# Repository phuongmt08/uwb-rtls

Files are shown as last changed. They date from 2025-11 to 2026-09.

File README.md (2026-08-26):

<div align="center">

# UWB-RTLS

### On-device indoor positioning for autonomous mobile robots







**[Results](#experimental-validation) · [System](#system-overview) · [Features](#core-capabilities) · [Quick start](#quick-start) · [Documentation](#documentation)**

</div>

UWB-RTLS is an end-to-end real-time location system developed for indoor mobile robots. Fixed UWB Anchors measure their distance to a mobile Tag using DS-TWR. The Tag validates the ranges, selects a reliable Anchor subset, fuses UWB with IMU data, and calculates its pose directly on an STM32F411. RTLS Studio provides wireless configuration, live diagnostics, visualization, and experiment logging.

<table>
  <tr>
    <th align="center">Best evaluated MAE</th>
    <th align="center">Best evaluated RMSE</th>
    <th align="center">Positioning</th>
    <th align="center">Validation</th>
  </tr>
  <tr>
    <td align="center"><strong>8.5 cm</strong></td>
    <td align="center"><strong>10.9 cm</strong></td>
    <td align="center"><strong>On the Tag</strong></td>
    <td align="center"><strong>2 real environments</strong></td>
  </tr>
</table>

## System Overview

Fixed Anchors provide UWB references around the operating area. The mobile Tag performs ranging and position estimation, sends pose data directly to the vehicle controller, and exposes configuration and telemetry through the BLE gateway.

```mermaid
flowchart TD
    Anchors["Fixed UWB Anchors"] <-->|"DS-TWR ranging"| Tag["Mobile Tag<br/>On-device positioning"]
    Tag -->|"Pose over USB"| Robot["Vehicle Controller"]
    Tag <-->|"Configuration + telemetry"| Gateway["BLE Gateway"]
    Gateway <-->|"USB serial"| Studio["RTLS Studio"]
```

Positioning remains operational without the desktop application: RTLS Studio is a configuration and observability tool, not the positioning engine.

## System in Practice

The experimental platform uses the developed Anchor/Tag hardware and a 1:10-scale vehicle. The photographs below show the actual Chapter 5 test-yard deployment.

<p align="center">
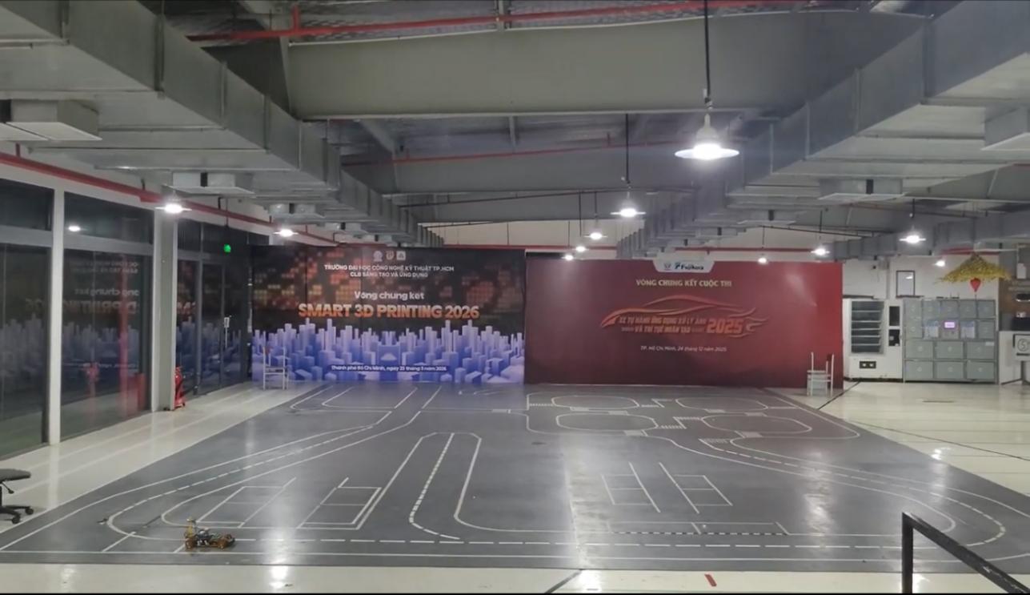
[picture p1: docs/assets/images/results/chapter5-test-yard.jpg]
Full UWB RTLS test-yard environment
  <br>
  <sub>Full four-Anchor test-yard deployment</sub>
</p>

<table>
  <tr>
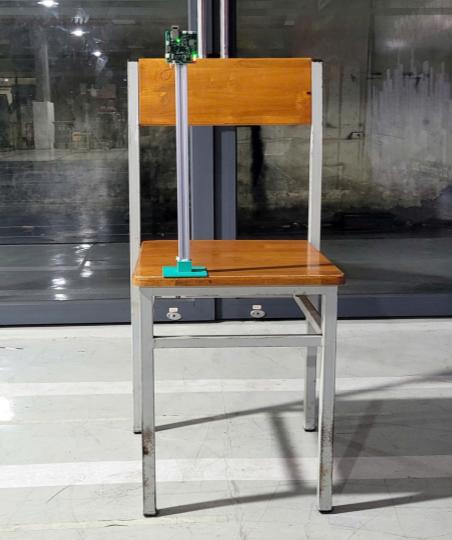
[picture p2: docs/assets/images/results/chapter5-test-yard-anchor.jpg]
UWB Anchor mounted at the test yard
    <td width="50%" align="center"><br><sub>Anchor installed at the surveyed height</sub></td>
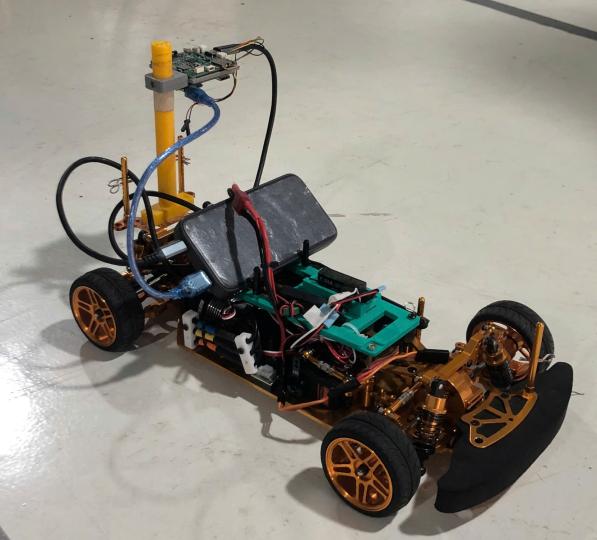
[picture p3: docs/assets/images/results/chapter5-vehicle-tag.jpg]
Mobile robot carrying the UWB Tag
    <td width="50%" align="center"><br><sub>1:10-scale vehicle carrying the Tag</sub></td>
  </tr>
</table>

RTLS Studio provides the host-side view of the deployed system for device configuration, diagnostics, and experiment recording.

<p align="center">
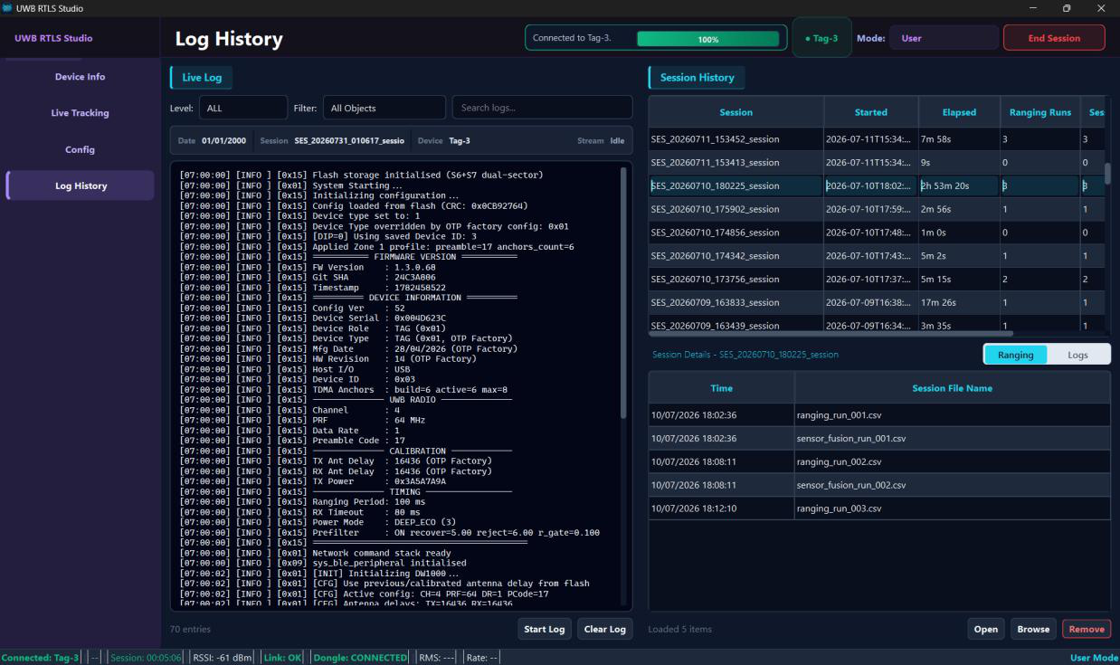
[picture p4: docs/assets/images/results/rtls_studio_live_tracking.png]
RTLS Studio diagnostics and session history
  <br>
  <sub>Connected-device diagnostics, live logs, and recorded ranging sessions</sub>
</p>

## Experimental Validation

Two dynamic cases were evaluated: a large, mostly line-of-sight test yard and a furnished classroom with stronger multipath and partial obstruction. Direct trilateration and UKF outputs were recorded simultaneously so both estimators saw the same motion and UWB measurements.

### Evaluation protocol

| Item | Method |
|---|---|
| Reference path | Manually surveyed control points connected by interpolation |
| Point error | Euclidean distance from each estimate to the nearest point on the reference path |
| Active interval | Samples before departure and after the vehicle stopped were excluded |
| Repetition | Three runs for each trajectory or Anchor configuration |
| Reported metrics | MAE, RMSE, 95th-percentile error, and maximum error |

### Case 1 — Test yard, four Anchors

The first case used a **9.76 m × 11.64 m** indoor test yard with mostly clear line of sight. Four Anchors surrounded the working area at **0.895 m**, while the Tag was mounted at **0.350 m**. The vehicle followed two surveyed trajectories, each repeated three times.

<table>
  <tr>
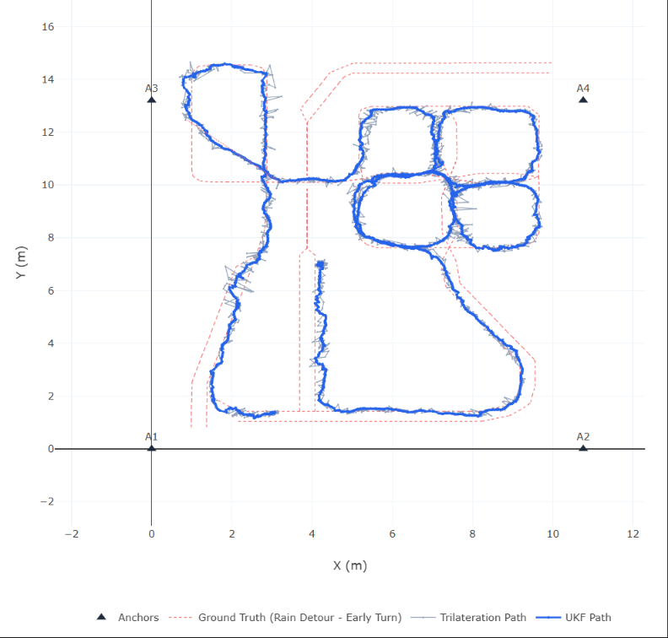
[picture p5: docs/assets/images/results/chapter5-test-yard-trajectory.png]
Test-yard reference, trilateration, and UKF trajectories
    <td width="50%" align="center"></td>
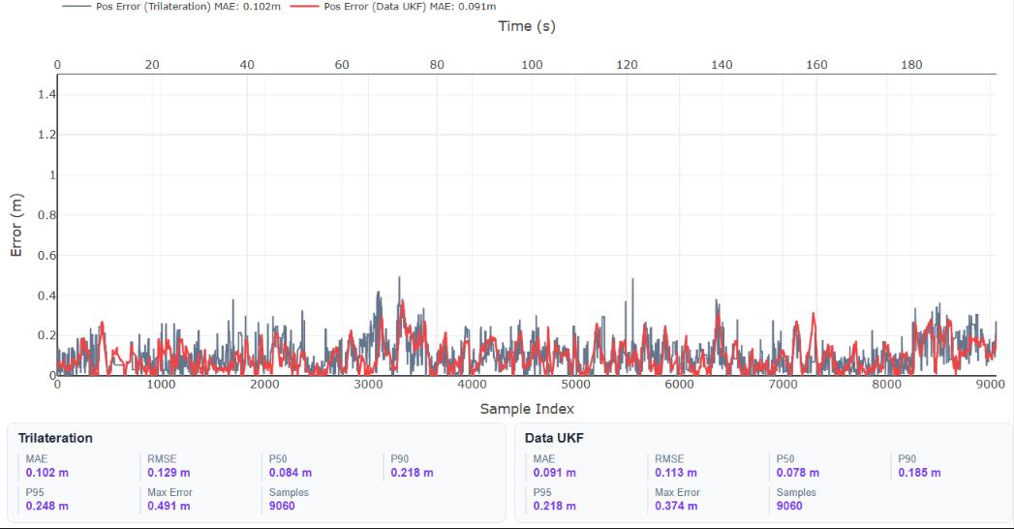
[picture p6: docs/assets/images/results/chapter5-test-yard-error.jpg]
Test-yard position error over time
    <td width="50%" align="center"></td>
  </tr>
  <tr>
    <td align="center"><sub>Reference path, direct trilateration, and UKF trajectory</sub></td>
    <td align="center"><sub>Position error from the same representative run</sub></td>
  </tr>
</table>

| Estimator | MAE (m) | RMSE (m) | P95 (m) | Max (m) |
|---|---:|---:|---:|---:|
| Direct trilateration | 0.102 ± 0.006 | 0.134 ± 0.010 | 0.268 ± 0.024 | 0.782 ± 0.281 |
| **UKF** | **0.091 ± 0.005** | **0.117 ± 0.005** | **0.236 ± 0.014** | **0.456 ± 0.063** |

Across the test-yard runs, the UKF reduced average MAE by **10.9%**, RMSE by **12.8%**, and maximum error from **0.782 m to 0.456 m**.

### Case 2 — Classroom, four and six Anchors

The second case used an **8.3 m × 8.7 m** classroom containing desks, people, and reflective surfaces. Anchors were installed at **2.495 m** and the Tag at **0.585 m**. Both four- and six-Anchor layouts were tested to measure the value of additional spatial redundancy.

<table>
  <tr>
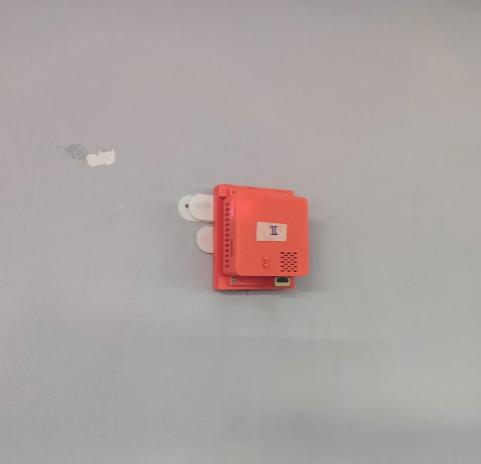
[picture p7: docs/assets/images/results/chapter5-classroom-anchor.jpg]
UWB Anchor mounted on a classroom wall
    <td width="50%" align="center"></td>
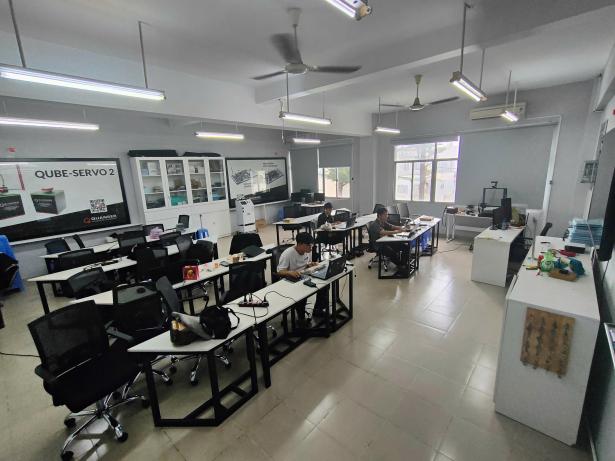
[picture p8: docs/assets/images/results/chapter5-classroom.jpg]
Classroom UWB RTLS deployment
    <td width="50%" align="center"></td>
  </tr>
  <tr>
    <td align="center"><sub>Wall-mounted Anchor</sub></td>
    <td align="center"><sub>Classroom deployment with furniture and occupants</sub></td>
  </tr>
</table>

<table>
  <tr>
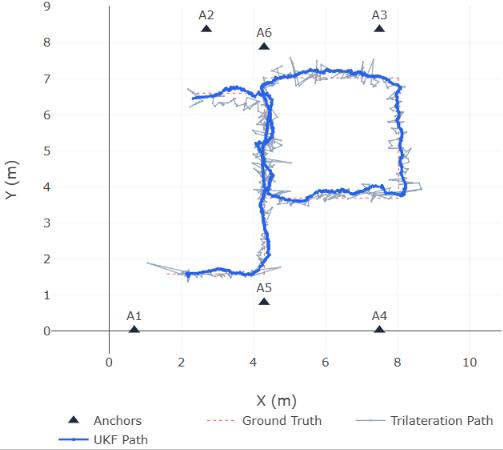
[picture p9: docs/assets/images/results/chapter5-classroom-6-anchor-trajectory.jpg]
Six-Anchor classroom trajectory result
    <td width="50%" align="center"></td>
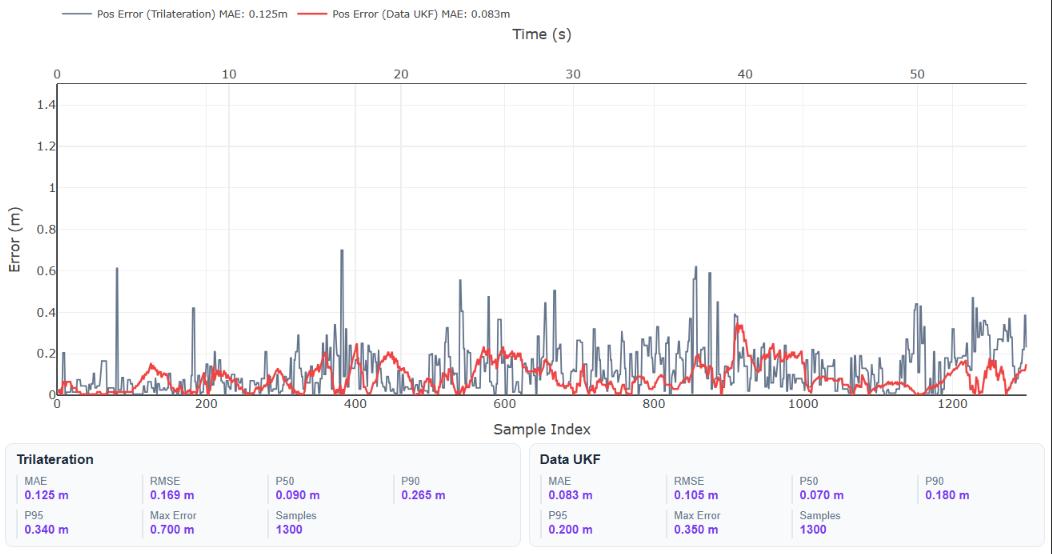
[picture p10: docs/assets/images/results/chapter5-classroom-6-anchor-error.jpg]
Six-Anchor classroom position error
    <td width="50%" align="center"></td>
  </tr>
  <tr>
    <td align="center"><sub>Six-Anchor reference, trilateration, and UKF trajectories</sub></td>
    <td align="center"><sub>Position error from the same representative run</sub></td>
  </tr>
</table>

| Layout | Estimator | MAE (m) | RMSE (m) | P95 (m) | Max (m) |
|---|---|---:|---:|---:|---:|
| 4 Anchors | Direct trilateration | 0.173 ± 0.027 | 0.230 ± 0.037 | 0.457 ± 0.084 | 1.099 ± 0.131 |
| 4 Anchors | **UKF** | **0.139 ± 0.036** | **0.185 ± 0.043** | **0.393 ± 0.085** | **0.583 ± 0.064** |
| 6 Anchors | Direct trilateration | 0.123 ± 0.006 | 0.177 ± 0.007 | 0.340 ± 0.035 | 1.150 ± 0.562 |
| 6 Anchors | **UKF** | **0.085 ± 0.013** | **0.109 ± 0.015** | **0.215 ± 0.035** | **0.340 ± 0.026** |

The six-Anchor UKF configuration produced the strongest overall result: **8.5 cm MAE**, **10.9 cm RMSE**, **21.5 cm P95**, and **34.0 cm maximum error**. The result demonstrates the benefit of additional valid ranging links in a difficult indoor environment.

> **Measurement scope:** the reference trajectory was reconstructed from manually measured control points, not an independent motion-capture system. The results therefore quantify tracking performance under the documented procedure rather than metrology-grade absolute accuracy.

## Core Capabilities

| Area | Implemented capability | Purpose |
|---|---|---|
| Ranging | Asymmetric DS-TWR with TDMA scheduling | Measures multiple Tag-to-Anchor ranges without clock synchronization |
| Measurement validation | Spatial innovation prefilter | Rejects inconsistent range combinations before estimation |
| Anchor selection | Robust precision and WGDOP ranking | Chooses a geometrically useful three-Anchor measurement set |
| Sensor fusion | 8-state UWB/IMU UKF | Estimates planar position, velocity, yaw, and IMU biases |
| Embedded runtime | FreeRTOS task-based firmware | Separates ranging, fusion, communication, storage, and supervision |
| Hardware flexibility | Unified Tag/Anchor STM32 firmware | Selects the device role and Anchor identity without maintaining separate applications |
| Configuration | Persistent profiles with CRC-protected storage | Keeps deployment parameters across resets |
| Communication | Shared Protobuf messages with COBS-framed transport | Maintains one contract across STM32, BLE, and Python |
| Desktop tooling | RTLS Studio and firmware programmer | Supports commissioning, live diagnostics, logs, and updates |

## Hardware and Software

| Layer | Main technology | Responsibility |
|---|---|---|
| Tag and Anchor MCU | STM32F411CEU6, Cortex-M4F | Real-time protocol, positioning, sensor fusion, and interfaces |
| UWB radio | Decawave/Qorvo DW1000 module | Precision packet timestamping for DS-TWR |
| Motion sensor | 6-DOF SPI IMU | Acceleration and yaw-rate input to the UKF |
| BLE nodes | Nordic nRF52 | Wireless configuration and telemetry |
| USB gateway | Nordic nRF52840 dongle | BLE central and USB bridge |
| Embedded OS | FreeRTOS | Deterministic task and queue organization |
| Desktop | Python 3.10+ and PyQt6 | RTLS Studio, programming, and analysis tools |

### Verified Development Environment

| Tool | Verified version |
|---|---|
| STM32CubeIDE | 1.19.0; project supports the 1.10+ workflow |
| Arm GNU Toolchain | 10.3.1 and 13.3.Rel1 |
| GNU Make | 4.4.1 |
| Nordic nRF5 SDK | 17.1.0 |
| Python | 3.10+; 3.12 verified |

## Quick Start

The commands below build the repository and launch RTLS Studio. Device flashing, antenna-delay calibration, Anchor surveying, and commissioning are covered in the [Getting Started Guide](docs/getting_started.md) and [Deployment Guide](docs/deployment.md).

### 1. Clone and generate the shared protocol

```powershell
git clone --recursive https://github.com/phuongmt08/uwb-rtls.git
cd uwb-rtls
make -C protocol
```

### 2. Build the STM32 firmware

Install STM32CubeIDE or an Arm GNU toolchain, then point `GCC_PATH` to its compiler `bin` directory.

```powershell
$env:GCC_PATH = "C:\path\to\arm-none-eabi\bin"
make -C firmware/uwb -j8
```

The build produces ELF, HEX, and BIN files under `firmware/uwb/build`.

### 3. Build the BLE firmware when required

The gateway and BLE bridge targets use Nordic nRF5 SDK 17.1.0.

```powershell
$env:SDK_ROOT = "C:\nRF5_SDK_17.1.0_ddde5a0"
make -C firmware/ble_firmware/central/armgcc
make -C firmware/ble_firmware/peripheral/armgcc
```

### 4. Launch RTLS Studio

```powershell
cd software
python -m venv .venv
.\.venv\Scripts\Activate.ps1
pip install -r requirements.txt
python uwb_rtls_studio/main.py
```

### 5. Commission a deployment

1. Install at least four Anchors around the operating area and assign unique IDs.
2. Survey their coordinates and create the deployment profile in RTLS Studio.
3. Mount the Tag on the vehicle and enter the Tag height.
4. Connect the BLE gateway, select the Tag, and push the configuration.
5. Start ranging and confirm that at least three valid Anchor links are available.
6. Monitor the embedded pose or record a session for offline evaluation.

## Repository Structure

```text
uwb-rtls/
├── firmware/     STM32 application, BLE firmware, and bootloader
├── software/     RTLS Studio, programmer, and analysis tools
├── protocol/     Protobuf contracts and generated bindings
├── hardware/     Schematics, PCB sources, and calibration data
└── docs/         Setup, deployment, architecture, algorithms, and thesis
```

## Documentation

| Start here | Scope |
|---|---|
| **[Getting Started](docs/getting_started.md)** | Toolchains, builds, flashing, and first connection |
| **[Deployment and Commissioning](docs/deployment.md)** | Physical layout, Anchor survey, calibration, and validation |
| **[Firmware Architecture](docs/firmware/architecture.md)** | Embedded layers, RTOS tasks, queues, and runtime ownership |
| **[DS-TWR Ranging Protocol](docs/firmware/ranging_protocol.md)** | Packet sequence, timestamps, timing, and TDMA behavior |
| **[Positioning Algorithms](docs/firmware/positioning_algorithms.md)** | Mathematical model, prefilter, Anchor selection, and UKF |
| **[Schematics and Specifications](docs/hardware/schematics_and_specs.md)** | Hardware boards, interfaces, and design references |
| **[RTLS Studio and Tools](docs/software/rtls_studio_and_tools.md)** | Desktop configuration, monitoring, logging, and programming |
| **[Thesis](docs/thesis/thesis_final.pdf)** | Full design, implementation, and experimental evaluation |

## Team

Developed at the **Faculty of Mechanical Engineering**, Ho Chi Minh City University of Technology and Engineering (**HCMUTE**).

- **Phuong Mai** — Firmware and system architecture
- **Dong Son** — Project co-developer
- **Trung Quan** — Project co-developer

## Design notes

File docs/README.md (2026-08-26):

# UWB-RTLS Documentation Index

[GitHub Repository](https://github.com/phuongmt08/uwb-rtls)

This directory contains the comprehensive technical documentation for the **UWB-RTLS** embedded indoor positioning system, covering firmware architecture, RF ranging protocols, positioning mathematics, hardware specifications, and desktop tools.

---

## 1. Documentation Map

| Section | Document | Description |
| --- | --- | --- |
| **Setup & Build** | **[Getting Started Guide](getting_started.md)** | Step-by-step toolchain setup, `GCC_PATH` configuration, and build instructions |
| **Firmware** | **[Firmware Architecture](firmware/architecture.md)** | Embedded layers, FreeRTOS runtime tasks, role selection, and source map |
| **Firmware** | **[DS-TWR Ranging Protocol](firmware/ranging_protocol.md)** | Timestamp mechanics, TDMA frame timing budget, and failure handling |
| **Firmware** | **[Positioning Algorithms](firmware/positioning_algorithms.md)** | Mahalanobis prefiltering, Huber weighting, WGDOP selection, and 8-State UKF |
| **Hardware** | **[Hardware Specifications](hardware/schematics_and_specs.md)** | System components, MCU/UWB/IMU/BLE pinout mappings, and power architecture |
| **Hardware** | **[Antenna Delay Calibration](hardware/antenna_calibration.md)** | Calibration theory, baseline measurement methodology, and tuning formula |
| **Software** | **[RTLS Studio & Tools](software/rtls_studio_and_tools.md)** | PyQt6 MVVM architecture, live 2D tracking, session export, and USB DFU Programmer |
| **Deployment** | **[Deployment & Commissioning](deployment.md)** | Anchor placement guidelines, GDOP optimization, and commissioning checklist |
| **Assets** | **[Asset Catalog](assets/README.md)** | Extracted thesis diagrams, architecture figures, and vector illustrations |

---

## 2. Thesis Benchmark & Performance Summary

The underlying academic thesis presents a modular indoor positioning system evaluated in a 6-Anchor classroom deployment:

| Metric | Measured Value | Operational Condition |
| --- | :---: | --- |
| **Mean Absolute Error (MAE)** | **$0.085\text{ m}$** ($8.5\text{ cm}$) | In-zone dynamic trajectory |
| **Root Mean Square Error (RMSE)** | **$0.109\text{ m}$** ($10.9\text{ cm}$) | 6-Anchor TDMA constellation |
| **95th-Percentile Error** | **$0.215\text{ m}$** ($21.5\text{ cm}$) | Under typical indoor multipath conditions |
| **Nominal Update Rate** | **$10\text{ Hz}$** ($100\text{ ms}$ frame) | Complete 6-Anchor ranging & UKF cycle |

---

## 3. Project Team & Credits

Developed at the **Faculty of Mechanical Engineering**, Ho Chi Minh City University of Technology and Engineering (**HCMUTE**).

- **Phuong Mai** — Lead Firmware & System Architecture
- **Dong Son** — Project Co-Developer
- **Trung Quan** — Project Co-Developer

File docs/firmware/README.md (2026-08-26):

# Firmware Documentation Guide

[Documentation Home](../README.md) · [Getting Started](../getting_started.md)

This section details the embedded firmware running on the STM32F411 microcontrollers, from low-level hardware abstraction up to real-time positioning algorithms and sensor fusion.

---

## 1. Reading Order

```mermaid
flowchart TD
    A["1. Firmware Architecture"] --> B["2. DS-TWR Ranging Protocol"]
    B --> C["3. Positioning Algorithms"]
```

1. **[Embedded Firmware Architecture](architecture.md)**
   - Role selection (Tag vs. Anchor via User Button hold).
   - Layered architecture (HAL $\rightarrow$ BSP $\rightarrow$ Middleware $\rightarrow$ Services $\rightarrow$ App).
   - FreeRTOS runtime task model and inter-task communication.

2. **[UWB Ranging Protocol](ranging_protocol.md)**
   - Asymmetric Double-Sided Two-Way Ranging (DS-TWR) message exchange.
   - TDMA superframe slot timing and multi-Anchor scheduling.
   - Outlier detection and timestamp arithmetic.

3. **[Embedded Positioning Algorithms](positioning_algorithms.md)**
   - Spatial Mahalanobis innovation prefiltering.
   - Robust Huber weighting and WGDOP Anchor triplet selection.
   - 8-State Unscented Kalman Filter (UKF) with 6-DOF IMU sensor fusion.

---

## 2. Architecture at a Glance

```
Fixed Anchors (0..N)
      ↕  UWB DS-TWR (10 Hz TDMA)
Mobile Robot Tag ──► Onboard 8-State UKF ──► USB CDC ──► Robot Controller
      ↕
BLE Node Bridge ──► BLE 5.0 ──► USB Dongle Gateway ──► RTLS Studio GUI
```

> **Core Principle:** Positioning calculations execute 100% onboard the Tag's STM32 MCU. Desktop tools and BLE gateways are strictly used for live visualization and configuration.

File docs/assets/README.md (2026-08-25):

# Documentation Assets

This directory contains visual material used by the technical Markdown documentation.

## Directory structure

```text
assets/
  images/
    thesis/
      raw/        Every image object extracted from all 128 PDF pages
      chapter3/   Curated Chapter 3 system figures
      chapter4/   Curated Chapter 4 figures with descriptive names
  diagrams/
    thesis/
      chapter3/   Exact Figure 3.1 deployment model
      chapter4/   Exact copies of the original diagram-type Chapter 4 figures
    english/
      chapter4/   English diagram translations
```

## Thesis figure extraction

All image objects from the complete 128-page thesis were extracted with Poppler:

```powershell
pdfimages -png thesis/thesis_final.pdf assets/images/thesis/raw/thesis-image
```

This produces 144 PNG files, numbered `thesis-image-000.png` through `thesis-image-143.png`. The count includes soft masks because they are independent image objects inside the PDF. No extracted object is translated, cropped, redrawn or otherwise modified.

The curated Chapter 3 and Chapter 4 files were selected from that extraction and renamed according to their thesis figure numbers. Soft-mask files for Figures 4.15 and 4.16 are retained because they are part of the original PDF image objects. Markdown should normally reference the main PNG, not the mask.

## Original thesis diagrams

| Diagram | Used by |
| --- | --- |
| `diagrams/thesis/chapter3/figure-3-1-system-deployment-model.png` | System overview |
| `diagrams/thesis/chapter4/figure-4-1-system-software-overview.png` | Documentation index and firmware architecture |
| `diagrams/thesis/chapter4/figure-4-8-ds-twr-sequence.png` | UWB ranging protocol |
| `diagrams/thesis/chapter4/figure-4-10-tdma-superframe.png` | UWB ranging protocol |
| `diagrams/thesis/chapter4/figure-4-14-extended-positioning-flow.png` | Embedded positioning algorithms |

Files under `diagrams/thesis` are exact, hash-verified copies of image objects extracted from the thesis. Their original language and content are intentionally preserved. English Markdown captions and surrounding explanations provide context without altering the source figures.

Files under `diagrams/english` are translated reproductions. A translated diagram must be checked against the original source geometry before it is referenced by documentation.

| English translation | Original source |
| --- | --- |
| `english/chapter4/figure-4-1-system-software-overview-en.svg` | `thesis/chapter4/figure-4-1-system-software-overview.png` |

## Source figure mapping

### Chapter 3

| File | Thesis figure | PDF page | Printed page |
| --- | --- | ---: | ---: |
| `chapter3/figure-3-1-system-deployment-model.png` | Figure 3.1 | 40 | 23 |

### Chapter 4

| File | Thesis figure | PDF page | Printed page |
| --- | --- | ---: | ---: |
| `figure-4-1-system-software-overview.png` | Figure 4.1 | 65 | 48 |
| `figure-4-2-firmware-startup-flow.png` | Figure 4.2 | 66 | 49 |
| `figure-4-3-firmware-layering.png` | Figure 4.3 | 66 | 49 |
| `figure-4-4-firmware-update-flow.png` | Figure 4.4 | 69 | 52 |
| `figure-4-5-flash-memory-map.png` | Figure 4.5 | 70 | 53 |
| `figure-4-6-dual-sector-storage.png` | Figure 4.6 | 72 | 55 |
| `figure-4-7-flash-write-and-swap-flow.png` | Figure 4.7 | 72 | 55 |
| `figure-4-8-ds-twr-sequence.png` | Figure 4.8 | 75 | 58 |
| `figure-4-9-tag-anchor-state-flow.png` | Figure 4.9 | 76 | 59 |
| `figure-4-10-tdma-superframe.png` | Figure 4.10 | 76 | 59 |
| `figure-4-11-initial-positioning-flow.png` | Figure 4.11 | 79 | 62 |
| `figure-4-12-system-mathematical-model.png` | Figure 4.12 | 80 | 63 |
| `figure-4-13-ukf-flow.png` | Figure 4.13 | 87 | 70 |
| `figure-4-14-extended-positioning-flow.png` | Figure 4.14 | 88 | 71 |
| `figure-4-15-nlos-cir-sample.png` | Figure 4.15 | 90 | 73 |
| `figure-4-16-los-cir-sample.png` | Figure 4.16 | 90 | 73 |
| `figure-4-17-ble-discovery-flow.png` | Figure 4.17 | 94 | 77 |
| `figure-4-18-ble-connection-flow.png` | Figure 4.18 | 95 | 78 |
| `figure-4-19-ble-data-exchange-flow.png` | Figure 4.19 | 95 | 78 |
| `figure-4-20-ble-disconnect-flow.png` | Figure 4.20 | 96 | 79 |
| `figure-4-21-unified-frame-format.png` | Figure 4.21 | 97 | 80 |
| `figure-4-22-ble-routing-flow.png` | Figure 4.22 | 98 | 81 |

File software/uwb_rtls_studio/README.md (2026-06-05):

# 🔵 UWB RTLS Studio

> Desktop monitoring dashboard cho hệ thống UWB RTLS (Ultra-Wideband Real-Time Location System).  
> Built with **PySide6** + **MVVM Architecture** + **Protobuf Protocol**.

---

## 📌 Tổng Quan

UWB RTLS Studio là ứng dụng desktop cho phép:
- **Detect & Connect** dongle NRF52840 Central qua USB
- **Scan & Select** các BLE devices (Tags, Anchors)
- **Live Tracking** — vị trí tag realtime trên 2D map
- **Config** — đọc/ghi cấu hình (anchor layout, time sync, UWB, Ranging, ...)
- **Calibration** — antenna delay tuning, IMU calibration (Developer)
- **Log & Session History** — xem logs, browse + debug past sessions

---

## 🏗 Architecture — MVVM + Repository

```
┌───────────────────────────────────────────────────────────────────────┐
│                         APPLICATION FLOW                              │
│                                                                       │
│   ┌──────────┐    ┌──────────┐    ┌──────────────────────────────┐   │
│   │  Dongle  │───►│   Scan   │───►│         Main Window          │   │
│   │  Popup   │    │  Popup   │    │  ┌─────┬─────┬─────┬───┬───┐│   │
│   │  (auto)  │    │  (list)  │    │  │Info │Track│Conf │Cal│Log ││   │
│   └──────────┘    └──────────┘    │  │ Tab │ Tab │ Tab │Tab│Tab ││   │
│                                    │  └─────┴─────┴─────┴───┴───┘│   │
│                                    │  [End Session]    [Status Bar]│   │
│                                    └──────────────────────────────┘   │
│                                              │ End Session           │
│                                              ▼                       │
│                                    ┌──────────────────┐              │
│                                    │   Repository     │              │
│                                    │  (Session Save)  │              │
│                                    │  data/sessions/  │              │
│                                    └──────────────────┘              │
└───────────────────────────────────────────────────────────────────────┘
```

### MVVM + Repository Layer Diagram

```
┌─────────────────┐     Qt Signals     ┌──────────────────┐    Direct     ┌─────────────────┐
│      VIEWS      │ ◄════════════════► │   VIEWMODELS     │ ════════════► │     MODELS      │
│  (Pure UI)      │                    │  (Business Logic) │              │  (Data/State)   │
├─────────────────┤                    ├──────────────────┤              ├─────────────────┤
│ • DonglePopup   │                    │ • DongleVM       │              │ • DongleModel   │
│ • ScanPopup     │                    │ • ScanVM         │              │ • DeviceModel   │
│ • MainWindow    │                    │ • MainVM         │              │ • SessionModel  │
│ • DeviceInfoTab │                    │ • DeviceInfoVM   │              │ • RangingModel  │
│ • TrackingTab   │                    │ • TrackingVM     │              │ • ConfigModel   │
│ • ConfigTab     │                    │ • ConfigVM       │              │ • TelemetryModel│
│ • CalibTab      │                    │ • CalibVM        │              │ • LogModel      │
│ • LogTab        │                    │ • LogVM          │              │                 │
└─────────────────┘                    └──────────────────┘              └─────────────────┘
                                              │         │
                                              ▼         ▼
                                    ┌──────────────────┐  ┌─────────────────┐
                                    │    SERVICES       │  │   REPOSITORY    │
                                    ├──────────────────┤  ├─────────────────┤
                                    │ • SerialService   │  │ • SessionRepo   │
                                    │ • ProtocolService │  │ • SessionBrowser│
                                    │ • DongleDetect    │  │                 │
                                    │ • DataExport      │  │ → data/sessions/│
                                    └──────────────────┘  └─────────────────┘
```

### Quy tắc MVVM

| Rule | Mô tả |
|---|---|
| View → ViewModel | View gọi ViewModel methods khi user tương tác |
| ViewModel → View | ViewModel emit Qt Signals, View listen via Slots |
| ViewModel → Model | ViewModel đọc/ghi Model trực tiếp |
| ViewModel → Repository | ViewModel gọi Repository để save/load sessions |
| View ✕ Model | View **KHÔNG BAO GIỜ** truy cập Model trực tiếp |
| ViewModel ✕ Import View | ViewModel **KHÔNG** import View classes |

---

## 🧵 Threading & Concurrency Architecture

Để đảm bảo ứng dụng không bị đơ (freeze), giật lag (stutter), hay tràn bộ nhớ (memory leak) khi phải nhận/gửi dữ liệu liên tục từ UWB/BLE ở tốc độ cao (ví dụ 10Hz - 30Hz), ứng dụng sử dụng mô hình đa luồng (Multi-threading) với **PyQt6 QThread** và cơ chế đồng bộ luồng nghiêm ngặt.

### 1. Phân chia luồng (Thread Separation)

Ứng dụng được chia làm 2 nhóm luồng chính:

*   **Main Thread (UI Thread):**
    *   Chạy vòng lặp sự kiện chính của Qt (`QApplication.exec()`).
    *   **Nhiệm vụ:** Render giao diện (Views), cập nhật bản đồ 2D tracking, xử lý logic (ViewModels), và quản lý trạng thái dữ liệu (Models).
    *   **Quy tắc:** Tuyệt đối KHÔNG chạy các tác vụ I/O (đọc/ghi file lớn, đọc/ghi Serial, network, delay/sleep) trên luồng này để tránh làm treo giao diện.
    *   Các `QTimer` (periodic poll battery, BLE status) cũng chạy trên Main Thread — chúng chỉ emit signal gọi `ProtocolService.send_command()` nên không blocking.

*   **Background Threads (Workers):**
    *   Chạy độc lập với UI, chuyên xử lý các tác vụ I/O hoặc blocking.
    *   `SerialReadWorker` (QThread): Chạy vòng lặp vô hạn `serial.read()`. Liên tục lắng nghe byte thô từ phần cứng mà không làm nghẽn UI.
    *   `DongleDetectWorker` (QThread): Gọi `serial.tools.list_ports` (hàm này rất chậm trên Windows, làm khựng app nếu chạy ở UI thread) để quét tìm thiết bị.
    *   `PeriodicPollWorker` (QThread): Chạy ngầm, dùng sleep/timer để định kỳ gửi lệnh hỏi (poll) pin, trạng thái hệ thống mỗi N giây.
    *   Tại bất kỳ thời điểm nào, chỉ có **TỐI ĐA 1 background thread** chiếm dụng cổng COM.

#### Vòng đời Thread & COM Port Ownership

Quan trọng: Trên Windows, một cổng COM chỉ cho phép **DUY NHẤT MỘT** process/object mở nó tại một thời điểm (Exclusive Access). Kiến trúc thread được thiết kế để đảm bảo điều này:

```
  Giai đoạn 1 (Detect)            Giai đoạn 2 (Runtime)
  ──────────────────────           ──────────────────────
  Main Thread (UI)                 Main Thread (UI)
  DongleDetectWorker (QThread)     SerialService._read_loop (threading.Thread)
     ↕ mở/đóng COM tạm thời          ↕ ĐỘC CHIẾM COM port
     ↕ (probe xong → đóng ngay)      ↕ (chạy suốt đến khi close)
     ↕ thread TỰ KẾT THÚC           
```

*   **`DongleDetectWorker` (QThread) — Thread lâm thời:**
    *   Chạy khi app khởi động, dò tìm dongle bằng protobuf handshake.
    *   Mở COM port tạm thời (< 0.5s) để gửi `device_information_get` → chờ ACK → **đóng ngay lập tức**.
    *   Khi tìm thấy dongle → emit signal → **thread tự chết**.
    *   Không bao giờ tồn tại đồng thời với Serial Reader Thread.

*   **`SerialService._read_loop` (threading.Thread) — Thread thường trú:**
    *   Chỉ được tạo SAU KHI DongleDetectWorker đã kết thúc.
    *   `SerialService.open(port)` tạo thread này — **ĐỘC CHIẾM COM port** xuyên suốt vòng đời app.
    *   Chạy vòng lặp vô hạn `serial.read()` để hứng dữ liệu từ phần cứng.
    *   Mọi tác vụ ghi (TX) đều đi qua `SerialService.write()` với `threading.Lock` bảo vệ.

*   **`PeriodicPollWorker` — KHÔNG phải OS Thread:**
    *   Chỉ là các `QTimer` chạy trên Main Thread.
    *   Định kỳ gọi `ProtocolService.send_command()` (battery, BLE status, etc.).
    *   Không tạo thread mới, không mở COM port riêng.

### 2. Cơ chế đồng bộ và giao tiếp (Communication Mechanism)

Nếu luồng Background (như `SerialReadWorker`) trực tiếp thay đổi dữ liệu của Model hoặc gọi hàm vẽ của View, ứng dụng sẽ bị **CRASH** lập tức (Lỗi *Cross-thread UI access* hoặc *Race condition*). 
Vì vậy, luồng giao tiếp được thiết kế bảo mật bằng **Signals** và **Queues**:

*   **Từ Worker ➡️ Main Thread (Sử dụng Qt Signals):**
    *   Khi `SerialReadWorker` đọc được 1 khối byte, nó không tự xử lý mà phát ra một **Signal** (ví dụ: `data_received(bytes)`).
    *   Cơ chế của Qt (QueuedConnection) sẽ tự động bắt lấy tín hiệu này, đưa nó vào một hàng đợi an toàn, rồi Main Thread sẽ từ từ lấy ra xử lý.
    *   Main Thread giao khối byte cho `ProtocolService` để parse thành Protobuf, rồi cập nhật vào Model.

*   **Từ Main Thread ➡️ Hardware (Sử dụng Thread-safe Queue):**
    *   Khi người dùng nhấn nút trên giao diện, ViewModel sẽ ra lệnh tạo ra một mảng bytes.
    *   Thay vì gọi trực tiếp `serial.write()` (có thể bị OS block nếu buffer đầy), Main Thread đẩy mảng bytes này vào một **Thread-safe Queue** (`queue.Queue` trong Python).
    *   Một Service ở dưới (như `SerialService`) sẽ lấy dữ liệu từ Queue này và ghi xuống cổng USB một cách an toàn.

*   **Cơ chế chống tràn RAM (Backpressure & Buffering):**
    *   **Models:** Các model lưu trữ dữ liệu liên tục như `position_history` (Ranging) hay `entries` (Logs) sử dụng cấu trúc dữ liệu có giới hạn (như `collections.deque(maxlen=10000)`). Khi dữ liệu quá nhiều, cái cũ nhất sẽ tự động bị đẩy ra. Nhờ vậy, dù cắm máy chạy 24/7 thì RAM của app vẫn không bị phình to (Memory Leak).
    *   **Data Export/Repository:** Khi người dùng nhấn *End Session*, việc gom toàn bộ dữ liệu ghi xuống ổ cứng sẽ được đẩy sang Background Thread hoặc sử dụng Async I/O để giao diện vẫn mượt mà trong lúc lưu file lớn.

### 3. Cơ chế phân loại và điều phối dữ liệu (Data Routing & Queue)

Vì toàn bộ app kết nối qua duy nhất **1 Dongle**, rủi ro đơ app hoặc sập phần cứng do các Tab "giẫm đạp" lên nhau để giao tiếp là rất cao. Kiến trúc xử lý như sau:

*   **Bộ Điều Phối Trung Tâm (Central Dispatcher - `ProtocolService`):**
    *   Mọi dữ liệu từ Dongle bắn lên đều hội tụ về `ProtocolService`.
    *   Service này đọc mã lệnh (`tag`) và làm nhiệm vụ **Router**.
    *   *Ví dụ:* Gói tin streaming `ranging_result_t` bắn lên 10 lần/giây, `ProtocolService` sẽ **chỉ** phân phối nó về `LiveTrackingViewModel`. Các Tab khác như Info, Config, hay Log sẽ hoàn toàn không nhận được, không bị đánh thức, giúp bảo toàn CPU.

*   **Hàng Đợi Lệnh & Van Điều Tiết (Command Queue & Throttling):**
    *   Nếu Tab 1 đòi đọc Pin, Tab 3 đòi lưu Cấu hình, Tab 4 đòi lấy dữ liệu IMU trong cùng 1 mili-giây, Dongle UART Buffer sẽ bị tràn (Overflow).
    *   **Giải pháp:** Các Tab khi gửi lệnh **không** gọi trực tiếp vào phần cứng. Lệnh được đẩy vào một **Write Queue** (Hàng đợi gửi) nằm trong `SerialService`.
    *   Hệ thống sẽ bốc từng lệnh từ Queue ra, gửi xuống USB, và có khoảng nghỉ vi mô (vài ms) giữa các lệnh. Dongle sẽ không bao giờ bị nghẹn.

### 4. Sơ đồ Luồng (Thread & Concurrency Layout)

Dưới đây là sơ đồ kiến trúc luồng, minh họa rõ vị trí của **Queue** và **Semaphore (Lock)** để ngăn chặn đụng độ (Race Condition) làm crash app:

```text
                                [ MAIN THREAD (UI) ]
 ┌────────────────┐ ┌────────────────┐ ┌────────────────┐ ┌────────────────┐
 │ Tab 1 (Info)   │ │ Tab 2 (Track)  │ │ Tab 3 (Config) │ │ Tab 4 (Log)    │
 └───────┬────────┘ └───────┬────────┘ └───────┬────────┘ └───────┬────────┘
         │ (Gửi lệnh)       │ (Gửi lệnh)       │ (Gửi lệnh)       │
         ▼                  ▼                  ▼                  ▼
 ┌─────────────────────────────────────────────────────────────────────────┐
 │                       ProtocolService (Router)                          │
 └────────────────────────────────────┬────────────────────────────────────┘
                                      │ 1. Đẩy lệnh (bytes) vào Queue
                                      ▼
                      [ Thread-safe WRITE QUEUE ] (queue.Queue)
                                      │
 ═════════════════════════════════════╪═════════════════════════════════════
                                      │ 2. Background Thread lấy lệnh ra
                      [ BACKGROUND THREAD (I/O) ]
                                      │
 ┌────────────────────────────────────▼────────────────────────────────────┐
 │                            SerialService                                │
 │                                                                         │
 │  ┌─────────────────────┐                         ┌───────────────────┐  │
 │  │ SerialWriteWorker   │ ◄── (SEMAPHORE/LOCK) ──►│ SerialReadWorker  │  │
 │  │ (Pop lệnh từ Queue) │    (Bảo vệ cổng USB)    │ (Vòng lặp đọc)    │  │
 │  └────────┬────────────┘                         └─────────▲─────────┘  │
 │           │ 3. serial.write()                              │ 4. read()  │
 └───────────┼────────────────────────────────────────────────┼────────────┘
             ▼                                                │
       [ USB PORT ] ──────────────────────────────────────────┘
```

**Vai trò của các công cụ đồng bộ (Synchronization Tools):**
1.  **Thread-safe Queue (Hàng đợi gửi lệnh):** 
    Dùng để chứa các lệnh từ Main Thread dội xuống. `queue.Queue` tự động xử lý khóa (thread-safe), nên 5 Tab có ra lệnh cùng lúc thì lệnh vẫn xếp hàng ngay ngắn, không bị đè lên nhau.
2.  **Semaphore / Mutex Lock (Khóa bảo vệ cổng USB):**
    Thư viện `pyserial` có thể bị lỗi (Crash cấp OS) nếu có 2 luồng khác nhau cùng thao tác trên 1 cổng COM (một luồng đang `read()` thì luồng kia lại nhào vô `write()`). Để giải quyết, `SerialService` sử dụng một cái khóa (`QMutex` hoặc `threading.Semaphore`). 
    *Luật:* Trọng tài (Semaphore) chỉ cho 1 luồng cầm chìa khóa. Nếu WriteWorker đang gửi lệnh, ReadWorker phải đứng đợi vài mili-giây. Viết xong, trả chìa khóa lại thì ReadWorker mới được đọc. Điều này bảo vệ tuyệt đối cổng Dongle không bị đứng máy.

---

## 📂 Cấu Trúc Thư Mục

```
uwb_rtls_studio/
├── main.py                          # 🚀 Entry point — bootstrapper
├── version.py                       # 📌 Version string
├── README.md                        # 📖 File này
│
├── models/                          # 📦 DATA LAYER
│   ├── __init__.py                  #     Package description
│   ├── dongle_model.py              #     USB dongle state
│   ├── device_model.py              #     BLE devices (scan list, connected)
│   ├── session_model.py             #     Session lifecycle + data bundle + meta
│   ├── ranging_model.py             #     Position data + trajectory history
│   ├── config_model.py              #     All config groups
│   ├── telemetry_model.py           #     Battery, temperature, diagnostics
│   └── log_model.py                 #     Log entries (device + app logs)
│
├── viewmodels/                      # 🧠 LOGIC LAYER
│   ├── __init__.py                  #     Package description + MVVM diagram
│   ├── dongle_viewmodel.py          #     Detect + connect dongle flow
│   ├── scan_viewmodel.py            #     BLE scan + device selection flow
│   ├── main_viewmodel.py            #     Tab switching, session, User/Dev mode
│   ├── device_info_viewmodel.py     #     Tab 1: Device identity + telemetry
│   ├── live_tracking_viewmodel.py   #     Tab 2: Ranging + position updates
│   ├── config_viewmodel.py          #     Tab 3: Config (User+Dev scoped)
│   ├── calibration_viewmodel.py     #     Tab 4: Calibration (Developer only)
│   └── log_viewmodel.py             #     Tab 5: Log + Session History (User+Dev)
│
├── views/                           # 🎨 UI LAYER
│   ├── __init__.py                  #     Package description
│   ├── windows/
│   │   └── main_window.py           #     Main window (tabs + status bar)
│   ├── popups/
│   │   ├── dongle_popup.py          #     Popup 1: Detect dongle
│   │   └── scan_popup.py            #     Popup 2: Scan + connect device
│   ├── tabs/
│   │   ├── device_info_tab.py       #     Tab 1: Device Info (User+Dev)
│   │   ├── live_tracking_tab.py     #     Tab 2: Live Tracking (User+Dev)
│   │   ├── config_tab.py            #     Tab 3: Config (User+Dev scoped)
│   │   ├── calibration_tab.py       #     Tab 4: Calibration (Developer only)
│   │   └── log_tab.py               #     Tab 5: Log + Session History (User+Dev)
│   └── components/
│       ├── status_bar.py            #     Bottom status bar
│       ├── glass_button.py          #     Glassmorphism button
│       ├── position_canvas.py       #     2D position map (QPainter)
│       └── log_text_widget.py       #     Color-coded log display
│
├── services/                        # 🔌 I/O & COMMUNICATION LAYER
│   ├── __init__.py
│   ├── serial_service.py            #     USB/Serial port management
│   ├── protocol_service.py          #     HDLC + Protobuf encode/decode
│   ├── dongle_detect_service.py     #     Auto-detect dongle via protobuf probe
│   └── data_export_service.py       #     Manual export (ad-hoc CSV/JSON)
│
├── repository/                      # 💾 PERSISTENCE LAYER (NEW)
│   ├── __init__.py                  #     Package description
│   ├── session_repository.py        #     Save/load/list session bundles
│   └── session_browser.py           #     Browse + filter past sessions
│
├── workers/                         # ⚡ BACKGROUND THREADS
│   ├── __init__.py
│   ├── serial_read_worker.py        #     (DEPRECATED — merged into SerialService)
│   ├── dongle_detect_worker.py      #     Protobuf probe + port-change monitor + check all COMx 
│   └── periodic_poll_worker.py      #     (Placeholder — dùng QTimer trên Main Thread)
│
├── utils/                           # 🛠 UTILITIES
│   ├── __init__.py
│   ├── constants.py                 #     Probe config, baud rate, timeouts, UI sizes
│   ├── theme.py                     #     Dark theme (QSS stylesheet + colors)
│   └── helpers.py                   #     Format functions, conversions
│
├── resources/                       # 🎨 STATIC ASSETS
│   ├── __init__.py
│   └── icons/
│       └── README.txt               #     Icon inventory list
│
└── data/                            # 💾 SESSION HISTORY (gitignored)
    ├── __init__.py
    └── sessions/                    #     ← Tất cả session history ở đây
        ├── SES_20260530_123000_ranging/
        │   ├── session_meta.json    #     Metadata: type, time, device, stats
        │   ├── positions.csv        #     Position samples
        │   ├── logs.csv             #     Log entries
        │   ├── config_snapshot.json #     Device config snapshot
        │   └── ranging_stats.json   #     Ranging statistics
        ├── SES_20260530_140500_streaming/
        │   ├── session_meta.json
        │   └── logs.csv
        └── ... (all history preserved)
```

---

## 🔄 Application Flow

### Flow 1: Dongle Detection (Startup)

App tự động detect dongle bằng **protobuf handshake** — không dùng VID/PID.
```
App Start → DonglePopup opens → DongleDetectWorker start (background thread)

  ┌─── Phase 1: Initial Scan ────────────────────────────────────────────┐
  │                                                                       │
  │  1. Liệt kê TẤT CẢ COM ports hiện có (serial.tools.list_ports)      │
  │  2. Sắp xếp theo priority score:                                     │
  │     - STM VCP (0483:5740) → score cao nhất                          │
  │     - USB Serial / Virtual COM → score trung bình                    │
  │     - Bluetooth Serial → score âm (skip ưu tiên)                    │
  │  3. Với mỗi port (theo thứ tự priority):                            │
  │     a. Mở serial tạm thời (115200 baud, timeout 0.05s)              │
  │     b. Gửi protobuf: device_information_get (HDLC wrapped)          │
  │     c. Chờ response trong 0.5s                                       │
  │     d. Nhận ACK hoặc device_information_resp?                        │
  │        ├─ YES → Đây là dongle! → emit dongle_found → Phase 3        │
  │        └─ NO  → Retry (tối đa 3 lần) → không ACK → skip port       │
  │     e. ĐÓNG serial port ngay lập tức (giải phóng COM)               │
  │                                                                       │
  └───────────────────────────────────────────────────────────────────────┘

  ┌─── Phase 2: Monitor Port Changes (nếu Phase 1 không tìm thấy) ──────┐
  │                                                                       │
  │  1. Lưu danh sách ports hiện tại: known_ports = {COM1, COM2, ...}         │
  │  2. Mỗi 800ms, so sánh port list hiện tại với known_ports            │
  │     (chỉ gọi list_ports — KHÔNG mở COM port, rất nhẹ)               │
  │  3. Có port MỚI xuất hiện (dongle vừa cắm vào)?                     │
  │     ├─ YES → Đợi 500ms cho driver enumerate → Quay lại Phase 1      │
  │     └─ NO  → Tiếp tục monitor                                       │
  │  4. Hết timeout (30s) → emit timeout → hiện lỗi [Retry] / [Cancel]  │
  │                                                                       │
  └───────────────────────────────────────────────────────────────────────┘

  ┌─── Phase 3: Open & Verify ───────────────────────────────────────────┐
  │                                                                       │
  │  1. DongleDetectWorker thread TỰ KẾT THÚC (end session)                 │
  │  2. DongleModel nhận signal dongle_found(DongleInfo)                 │
  │  3. Mở serial CHÍNH THỨC qua SerialService.open(port)               │
  │     → Tạo SerialReader thread (ĐỘC CHIẾM COM port từ đây)          │
  │  4. Gửi device_information_get qua ProtocolService                   │
  │  5. Nhận device_information_resp?                                     │
  │     ├─ YES → Lấy fw_version, serial, role → ✅ dongle_verified      │
  │     └─ TIMEOUT (3s) → ⚠️ Proceed unverified                        │
  │  6. DonglePopup auto-close → Mở ScanPopup                           │
  │                                                                       │
  └───────────────────────────────────────────────────────────────────────┘
```

**Tại sao không dùng VID/PID?**
- VID/PID phụ thuộc vào USB chip cụ thể (Nordic, STM, etc.) — dễ sai.
- Protobuf handshake xác nhận được firmware thật sự đang chạy trên device.
- Có khả năng bị trùng với VID/PID khác của các device khác nhau.

### Flow 2: BLE Scanning (Scan Popup)

```
ScanPopup opens → Auto send ble_scan_start (tag=51)
              → Dongle scans BLE devices
              → Receive ble_scan_result (tag=54) for each device
              → Display in table: Name | Type | RSSI | MAC | Serial
              → User selects a TAG device
              → Click [Connect]
              → Send ble_connect (tag=53)
              → Log: "Connecting..."
              → Receive confirmation + adv info
              → Log: "✅ Connected to UWB-Tag-01"
              → Close popup → Open MainWindow
```

### Flow 3: Main Window (Tabs)

```
MainWindow opens with connected device
├── Tab 1: Device Info     → device_info, battery, ble_status     (User+Dev)
├── Tab 2: Live Tracking   → ranging_start/stop/result            (User+Dev)
├── Tab 3: Config          → anchor layout, time sync, UWB, ...   (User+Dev scoped)
├── Tab 4: Calibration     → pos_calib, calib_status, IMU         (Developer only)
└── Tab 5: Log & History   → device logs, session history browser  (User+Dev)

[End Session] → Dừng protobuf activities → Save session → Browse later
[Close Window] → Full app shutdown
```

### Flow 4: End Session (Chi tiết)

```
User đang ranging/streaming/log
         │
         ▼
    [🔴 End Session] clicked
         │
         ├─ 1. Gửi end_session_t (tag=65) với reason phù hợp
         │     - SESSION_END_REASON_RANGING_RESULTS  (nếu ranging)
         │     - SESSION_END_REASON_DEBUG_STREAMING   (nếu streaming)
         │     - SESSION_END_REASON_LOG_DATA          (nếu log upload)
         │
         ├─ 2. Dừng protobuf activities
         │     - ranging_stop_t (nếu ranging)
         │     - Stop log stream (nếu streaming)
         │     ⚠ KHÔNG disconnect dongle / BLE / device
         │
         ├─ 3. Bundle toàn bộ session data
         │     - SessionState (type, time, stats)
         │     - Positions CSV (nếu ranging)
         │     - Logs CSV (tất cả log trong session)
         │     - Config snapshot JSON
         │     - Ranging stats JSON (nếu ranging)
         │     - Device info + Dongle info
         │
         ├─ 4. Save vào Repository
         │     → data/sessions/SES_20260530_123000_ranging/
         │     → session_meta.json + positions.csv + logs.csv + ...
         │     → Session được lưu VĨNH VIỄN (không tự xóa)
         │
         ├─ 5. App vẫn chạy bình thường
         │     - Dongle vẫn connected (USB serial)
         │     - BLE device vẫn connected
         │     - Có thể bắt đầu session mới ngay
         │
         └─ 6. User browse session history bất kỳ lúc nào
               → Tab 5 (Log & History) → Session History section
               → Open session → xem lại data để debug
```

### Flow 5: Kill App (khác End Session)

```
User đóng window hoặc File > Exit
         │
         ├─ Nếu session đang active → auto End Session + save trước
         ├─ Disconnect BLE (ble_disconnect_t)
         ├─ Close serial port
         ├─ Stop all worker threads
         ├─ Cleanup resources
         └─ Exit process (sys.exit)
```

---

## 🖥 User Mode vs Developer Mode

### Tab Visibility

| Tab | User Mode | Developer Mode |
|-----|---|---|
| Tab 1: Device Info | ✅ Full | ✅ Full |
| Tab 2: Live Tracking | ✅ Full | ✅ Full |
| Tab 3: Config | ✅ User sections | ✅ All sections |
| Tab 4: Calibration | ❌ **Hidden** | ✅ Full |
| Tab 5: Log & History | ✅ Device logs | ✅ All logs |

### Config Tab — Section Visibility

| Config Section | User Mode | Developer Mode |
|---|---|---|
| 👤 Anchor/Tag Layout | ✅ Read | ✅ Read/Write |
| 👤 Time Synchronization | ✅ Read/Write | ✅ Read/Write |
| 👤 Ranging Configuration | ✅ Read/Write | ✅ Read/Write |
| 👤 UWB Basic Info | ✅ Read-only | ✅ Read/Write |
| 🔧 UWB Advanced Config | ❌ Hidden | ✅ Read/Write |
| 🔧 Sensor Fusion (UKF) | ❌ Hidden | ✅ Read/Write |
| 🔧 BLE Connection Params | ❌ Hidden | ✅ Read/Write |
| 🔧 System Commands | ❌ Hidden | ✅ |

### Log Tab — Content Visibility

| Log Content | User Mode | Developer Mode |
|---|---|---|
| Device Logs (INFO/WARN/ERROR) | ✅ | ✅ |
| Device Logs (DEBUG) | ❌ Filtered | ✅ |
| App Internal Logs | ❌ Hidden | ✅ |
| Raw Protocol Logs (TX/RX) | ❌ Hidden | ✅ |
| Session History Browser | ✅ | ✅ |
| Export CSV/TXT | ✅ | ✅ |
| Clear Device Logs | ❌ Hidden | ✅ |
| Advanced Filters | ❌ Hidden | ✅ |

Toggle via dropdown/button in title bar.

---

## 📡 Protocol Dependency

Toàn bộ communication sử dụng **Protobuf** messages qua **HDLC framing**.

| Layer | Module | Location |
|---|---|---|
| Proto defs | `protocol.proto` | `protocol/protos/` |
| Python bindings | `protocol_pb2.py` | `software/common/` |
| HDLC + Parser | `transport.py` | `software/common/` |
| Command factory | `commands.py` | `software/common/` |

Packet flow:
```
ViewModel → CommandFactory.build() → ProtocolService.encode()
         → SerialService.write() → USB → Dongle → BLE → Device

Device → BLE → Dongle → USB → SerialService.read()
       → ProtocolService.decode() → dispatch → ViewModel
```

---

## 📦 Dependencies

| Package | Version | Purpose |
|---|---|---|
| PyQt6 | ≥ 6.5 | Qt GUI framework |
| pyserial | ≥ 3.5 | Serial/USB communication |
| protobuf | ≥ 4.0 | Protocol buffer runtime |

---

## 🚧 Development Status

- [x] Project layout (MVVM + Repository structure)
- [x] File scaffolding with documentation
- [x] Session persistence design (Repository layer)
- [x] Models implementation (dataclasses)
- [x] Services implementation (serial, protocol, dongle detect)
- [x] Workers implementation (DongleDetectWorker — protobuf probe)
- [x] ViewModels implementation (dongle, scan, device info, tracking)
- [x] Views implementation (PyQt6 UI — popups, tabs, main window)
- [x] Theme & styling (dark theme, glassmorphism)
- [x] Dongle auto-detection (protobuf handshake, event-based)
- [ ] Repository implementation (session save/load)
- [ ] PeriodicPollWorker (battery, BLE status)
- [ ] Calibration tab (Developer mode)
- [ ] Icon assets
- [ ] Testing
- [ ] Build & packaging

---

## ✍ Author

**Trung Quan** — UWB RTLS Project  
Date: 2026

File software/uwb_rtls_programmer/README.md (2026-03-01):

# UWB-RTLS Programmer

Ứng dụng Python + Qt6 để nạp firmware qua USB DFU (STM32 ROM DFU/bootloader DFU), tối ưu cho layout hiện tại:

- App range: `0x0800C000 .. 0x0803FFFF`
- App sectors: `0x0800C000`, `0x08010000`, `0x08020000`

## Tính năng

- Scan theo VID/PID đang nhập (mặc định `0483:DF11`) để tránh bắt nhầm thiết bị DFU khác
- Auto Connect từ danh sách thiết bị đã scan
- Erase theo bảng sector có checkbox (S3..S7), gồm cả vùng App và Data storage
- Mass erase (gửi lệnh DFU `0x41`)
- Flash file `.hex` (Intel HEX), tự lấy địa chỉ từ file
- Nút chọn file `Browse` + lưu danh sách đường dẫn HEX gần đây
- Verify readback sau khi flash
- Nút `Build UWB` để build firmware `firmware/uwb` trực tiếp từ app
- Progress + log realtime

## Yêu cầu

- Python 3.10+
- Trên Windows: thiết bị DFU cần driver WinUSB/libusb (thường cài bằng Zadig)
- Cần có `make` (hoặc `mingw32-make`) trong PATH
- Cần đặt biến môi trường `GCC_PATH` trỏ tới thư mục GNU Arm toolchain (bin), ví dụ: `C:/ST/STM32CubeCLT/.../GNU-tools-for-STM32/bin`

## Cài đặt

```bat
cd software
install_requirements.bat
```

Script sẽ tự tạo virtualenv tại `software\\.venv` và cài toàn bộ modules từ `software\\requirements.txt`.
Script dùng `py -3.12`, nên cần cài Python 3.12 trên máy.

## Chạy

```bash
python main.py
```
    
## Quy trình khuyến nghị

1. Connect device
2. Chọn file `.hex` bằng `Browse` (hoặc chọn lại từ danh sách recent)
3. Tick sector cần xoá trong bảng (nếu không tick, `Erase App Sectors` sẽ báo lỗi)
4. Chạy `Erase App Sectors` hoặc `Mass Erase` nếu cần
5. Chạy `Flash`
6. Chạy `Verify`

## Lưu ý

- App chỉ được phép flash trong vùng `0x0800C000 .. 0x0803FFFF`.
- Nếu không connect được trên Windows, kiểm tra driver bằng Zadig (WinUSB) cho interface DFU.
- Nếu báo `No backend available`: PyUSB chưa thấy `libusb`. Dùng Python `3.12` cho venv, cài `libusb-package`, và cài driver DFU bằng Zadig (WinUSB/libusbK).

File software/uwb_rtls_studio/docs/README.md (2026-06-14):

# UWB RTLS Studio

Desktop app theo dõi và debug hệ thống UWB RTLS. App dùng **PyQt6**, kiến trúc
**MVVM + Repository**, giao tiếp firmware qua **HDLC + Protobuf**.

## Mục Tiêu Kiến Trúc

Project này phục vụ firmware/hardware workflow, nên code software chỉ giữ mức
cần thiết để dễ debug, dễ mở rộng command/API, và không over-engineering.

Nguyên tắc chính:

- Một dongle/COM port là nguồn giao tiếp duy nhất.
- Mọi command đi qua một command path chung.
- Mọi packet từ firmware đi vào packet repository chung trước khi phân phối.
- UI không parse protobuf và không truy cập raw packet trực tiếp.
- View chỉ hiển thị UI và phát trigger.

## Layer Ownership

```text
View
  UI widgets, user trigger, dialog confirm, table/chart rendering.

ViewModel
  Nhận trigger từ View, validate command/API, gọi Model/CommandBus,
  format dữ liệu cho View, emit Qt signals.

Model
  Business/domain logic: connection state, session lifecycle state,
  ranging state, calculations, buffer domain data.

Repository
  Nhận decoded protobuf packet, parse thành dict/domain data,
  cache dữ liệu dùng chung, lưu/load session history.

Data
  RawPacket, RawPacketStore, raw byte/file-based session data.

Service/Common
  Serial I/O, HDLC framing, protobuf encode/decode, command builder,
  command queue/cache/dedupe.
```

## Data Flow Từ Firmware Lên UI

```text
MCU/BLE peripheral
  -> Dongle
  -> SerialService.read()
  -> ProtocolService.decode_from_frames()
  -> ProtocolPacketRepository.handle_packet()
  -> RawPacketStore + domain repositories
  -> Model/ViewModel signals
  -> View update UI
```

Ví dụ `ranging_result`:

```text
protocol.proto:ranging_result
  -> ProtocolService decode
  -> ProtocolPacketRepository
  -> RangingRepository parse position/anchors
  -> RangingModel update history/stats
  -> LiveTrackingViewModel emit position_updated
  -> LiveTrackingTab/PositionCanvas render
```

Ví dụ `log_data`:

```text
protocol.proto:log_data
  -> ProtocolPacketRepository
  -> LogRepository parse firmware log records
  -> LogViewModel append live log/session log
  -> LogTab stream live log
  -> End Session saves logs.csv + logs.txt
```

## Command Flow Từ UI Xuống Firmware

```text
View button/action
  -> ViewModel method
  -> Model or CommandBus
  -> common.commands builder
  -> ProtocolService.wrap_packet()
  -> SerialService.write()
  -> Dongle/Device
```

View không gọi `ProtocolService.send_command()` trực tiếp.

## Shared State

`utils/app_state.py` là shared memory nhẹ cho app:

- shared config: anchor layout, sys config, ranging config.
- shared telemetry: battery, BLE status, RTOS diagnostics.
- shared job state: query queue, ranging session.
- thread registry: detect/read worker ownership.

Shared state không thay thế MVVM. View không nên đọc trực tiếp shared state.
ViewModel/Model/Repository đọc hoặc cập nhật shared state rồi emit signal cho UI.

## Repository Hiện Có

- `ProtocolPacketRepository`: entry point cho mọi decoded protobuf packet.
- `TelemetryRepository`: battery/telemetry packets.
- `BleScanRepository`: BLE scan result và advertising status.
- `RangingRepository`: ranging result/status và anchor layout.
- `ConfigRepository`: sys config, ranging config, sensor fusion, pos calib.
- `DiagnosticsRepository`: calibration status, RTOS resource/task stats.
- `LogRepository`: firmware log_data parsing và live/session log cache.
- `SessionRepository`: save/load session metadata, positions, logs, config snapshot.
- `SessionBrowser`: API browse/filter/open/delete session history.

## Thread Ownership

- UI thread: PyQt6 widgets, ViewModels, Models, repository signal handling.
- `SerialService`: owns the runtime serial port and read loop.
- `DongleDetectWorker`: temporary worker for probing COM ports before runtime open.
- Query queue: centralized in `SharedAppState`/`QueryQueueManager`.

Rule quan trọng: không mở nhiều serial owner cho cùng một COM port.

## Session History

Khi user bấm End Session:

1. `MainWindow` chỉ hỏi confirm.
2. `MainViewModel.end_session()` điều phối flow.
3. ViewModel gom positions/logs/config/device info từ domain layer.
4. `SessionRepository.save_session()` lưu:
   - `session_meta.json`
   - `positions.csv` nếu có ranging
   - `logs.csv` và `logs.txt` nếu có log
   - `config_snapshot.json` nếu có config
   - metadata vao `session_meta.json` va `data/sessions/index.json`
5. `LogViewModel.refresh_sessions()` cập nhật tab history.

## MVVM Rules

| Rule | Đúng |
| --- | --- |
| View -> ViewModel | View gọi method khi user thao tác |
| ViewModel -> View | ViewModel emit signal, View render |
| ViewModel -> CommandBus/Model | ViewModel validate và gọi command/domain API |
| Model -> Repository/Data | Model dùng data đã parse hoặc domain repository |
| Repository -> Data | Repository đọc/lưu raw/domain/session data |

| Anti-pattern | Tránh |
| --- | --- |
| View đọc `shared_app_state` trực tiếp | Đưa qua ViewModel signal |
| View tự gọi `SessionRepository` | Đưa qua MainViewModel/SessionRepository |
| ViewModel giữ `_protocol` private của Model | Dùng CommandBus hoặc Model public API |
| Nhiều Model cùng parse một packet | Parse tập trung ở Repository |
| Command gửi rải rác ở nhiều tab | Đi qua CommandBus/query queue |

## PyQt6

`uwb_rtls_studio` dùng PyQt6:

- signal: `pyqtSignal`
- widgets/core/gui: `PyQt6.QtWidgets`, `PyQt6.QtCore`, `PyQt6.QtGui`
- UI load: `PyQt6.uic.loadUi`

Không dùng PySide6 trong `uwb_rtls_studio`.

## Development Checklist

Khi thêm API mới từ `protocol.proto`:

1. Thêm command builder trong `software/common/commands.py` nếu là command TX.
2. Đảm bảo expected response trong query/command state machine nếu cần.
3. Thêm parse route trong repository phù hợp.
4. Repository emit signal hoặc cập nhật shared state/domain cache.
5. Model xử lý logic nghiệp vụ nếu cần.
6. ViewModel expose method/signal cho UI.
7. View chỉ bind signal và trigger method.

## Known Refactor Direction

Các phần đã đi đúng hướng nhưng còn có thể làm sạch tiếp:

- Giảm dần packet parsing còn lại trong `DeviceModel`.
- Cho `ScanModel` dùng hoàn toàn `BleScanRepository` thay vì fallback parse trực tiếp.
- Đưa các write/update shared state tạm thời trong ViewModel về Model khi domain logic lớn hơn.
- Chuẩn hóa session start time thay vì dùng end time làm start time khi session chưa có tracker riêng.
# 🔵 UWB RTLS Studio

> Desktop monitoring dashboard cho hệ thống UWB RTLS (Ultra-Wideband Real-Time Location System).  
> Built with **PySide6** + **MVVM Architecture** + **Protobuf Protocol**.

---

## 📌 Tổng Quan

UWB RTLS Studio là ứng dụng desktop cho phép:
- **Detect & Connect** dongle NRF52840 Central qua USB
- **Scan & Select** các BLE devices (Tags, Anchors)
- **Live Tracking** — vị trí tag realtime trên 2D map
- **Config** — đọc/ghi cấu hình (anchor layout, time sync, UWB, Ranging, ...)
- **Calibration** — antenna delay tuning, IMU calibration (Developer)
- **Log & Session History** — xem logs, browse + debug past sessions

---

## 🏗 Architecture — MVVM + Repository

```
┌───────────────────────────────────────────────────────────────────────┐
│                         APPLICATION FLOW                              │
│                                                                       │
│   ┌──────────┐    ┌──────────┐    ┌──────────────────────────────┐   │
│   │  Dongle  │───►│   Scan   │───►│         Main Window          │   │
│   │  Popup   │    │  Popup   │    │  ┌─────┬─────┬─────┬───┬───┐│   │
│   │  (auto)  │    │  (list)  │    │  │Info │Track│Conf │Cal│Log ││   │
│   └──────────┘    └──────────┘    │  │ Tab │ Tab │ Tab │Tab│Tab ││   │
│                                    │  └─────┴─────┴─────┴───┴───┘│   │
│                                    │  [End Session]    [Status Bar]│   │
│                                    └──────────────────────────────┘   │
│                                              │ End Session           │
│                                              ▼                       │
│                                    ┌──────────────────┐              │
│                                    │   Repository     │              │
│                                    │  (Session Save)  │              │
│                                    │  data/sessions/  │              │
│                                    └──────────────────┘              │
└───────────────────────────────────────────────────────────────────────┘
```

### MVVM + Repository Layer Diagram

```
┌─────────────────┐     Qt Signals     ┌──────────────────┐    Direct     ┌─────────────────┐
│      VIEWS      │ ◄════════════════► │   VIEWMODELS     │ ════════════► │     MODELS      │
│  (Pure UI)      │                    │  (Business Logic) │              │  (Data/State)   │
├─────────────────┤                    ├──────────────────┤              ├─────────────────┤
│ • DonglePopup   │                    │ • DongleVM       │              │ • DongleModel   │
│ • ScanPopup     │                    │ • ScanVM         │              │ • DeviceModel   │
│ • MainWindow    │                    │ • MainVM         │              │ • SessionModel  │
│ • DeviceInfoTab │                    │ • DeviceInfoVM   │              │ • RangingModel  │
│ • TrackingTab   │                    │ • TrackingVM     │              │ • ConfigModel   │
│ • ConfigTab     │                    │ • ConfigVM       │              │ • TelemetryModel│
│ • CalibTab      │                    │ • CalibVM        │              │ • LogModel      │
│ • LogTab        │                    │ • LogVM          │              │                 │
└─────────────────┘                    └──────────────────┘              └─────────────────┘
                                              │         │
                                              ▼         ▼
                                    ┌──────────────────┐  ┌─────────────────┐
                                    │    SERVICES       │  │   REPOSITORY    │
                                    ├──────────────────┤  ├─────────────────┤
                                    │ • SerialService   │  │ • SessionRepo   │
                                    │ • ProtocolService │  │ • SessionBrowser│
                                    │ • DongleDetect    │  │                 │
                                    │ • DataExport      │  │ → data/sessions/│
                                    └──────────────────┘  └─────────────────┘
```

### Quy tắc MVVM

| Rule | Mô tả |
|---|---|
| View → ViewModel | View gọi ViewModel methods khi user tương tác |
| ViewModel → View | ViewModel emit Qt Signals, View listen via Slots |
| ViewModel → Model | ViewModel đọc/ghi Model trực tiếp |
| ViewModel → Repository | ViewModel gọi Repository để save/load sessions |
| View ✕ Model | View **KHÔNG BAO GIỜ** truy cập Model trực tiếp |
| ViewModel ✕ Import View | ViewModel **KHÔNG** import View classes |

---

## 🧵 Threading & Concurrency Architecture

Để đảm bảo ứng dụng không bị đơ (freeze), giật lag (stutter), hay tràn bộ nhớ (memory leak) khi phải nhận/gửi dữ liệu liên tục từ UWB/BLE ở tốc độ cao (ví dụ 10Hz - 30Hz), ứng dụng sử dụng mô hình đa luồng (Multi-threading) với **PyQt6 QThread** và cơ chế đồng bộ luồng nghiêm ngặt.

### 1. Phân chia luồng (Thread Separation)

Ứng dụng được chia làm 2 nhóm luồng chính:

*   **Main Thread (UI Thread):**
    *   Chạy vòng lặp sự kiện chính của Qt (`QApplication.exec()`).
    *   **Nhiệm vụ:** Render giao diện (Views), cập nhật bản đồ 2D tracking, xử lý logic (ViewModels), và quản lý trạng thái dữ liệu (Models).
    *   **Quy tắc:** Tuyệt đối KHÔNG chạy các tác vụ I/O (đọc/ghi file lớn, đọc/ghi Serial, network, delay/sleep) trên luồng này để tránh làm treo giao diện.
    *   Các `QTimer` (periodic poll battery, BLE status) cũng chạy trên Main Thread — chúng chỉ emit signal gọi `ProtocolService.send_command()` nên không blocking.

*   **Background Threads (Workers):**
    *   Chạy độc lập với UI, chuyên xử lý các tác vụ I/O hoặc blocking.
    *   `SerialReadWorker` (QThread): Chạy vòng lặp vô hạn `serial.read()`. Liên tục lắng nghe byte thô từ phần cứng mà không làm nghẽn UI.
    *   `DongleDetectWorker` (QThread): Gọi `serial.tools.list_ports` (hàm này rất chậm trên Windows, làm khựng app nếu chạy ở UI thread) để quét tìm thiết bị.
    *   `PeriodicPollWorker` (QThread): Chạy ngầm, dùng sleep/timer để định kỳ gửi lệnh hỏi (poll) pin, trạng thái hệ thống mỗi N giây.
    *   Tại bất kỳ thời điểm nào, chỉ có **TỐI ĐA 1 background thread** chiếm dụng cổng COM.

#### Vòng đời Thread & COM Port Ownership

Quan trọng: Trên Windows, một cổng COM chỉ cho phép **DUY NHẤT MỘT** process/object mở nó tại một thời điểm (Exclusive Access). Kiến trúc thread được thiết kế để đảm bảo điều này:

```
  Giai đoạn 1 (Detect)            Giai đoạn 2 (Runtime)
  ──────────────────────           ──────────────────────
  Main Thread (UI)                 Main Thread (UI)
  DongleDetectWorker (QThread)     SerialService._read_loop (threading.Thread)
     ↕ mở/đóng COM tạm thời          ↕ ĐỘC CHIẾM COM port
     ↕ (probe xong → đóng ngay)      ↕ (chạy suốt đến khi close)
     ↕ thread TỰ KẾT THÚC           
```

*   **`DongleDetectWorker` (QThread) — Thread lâm thời:**
    *   Chạy khi app khởi động, dò tìm dongle bằng protobuf handshake.
    *   Mở COM port tạm thời (< 0.5s) để gửi `device_information_get` → chờ ACK → **đóng ngay lập tức**.
    *   Khi tìm thấy dongle → emit signal → **thread tự chết**.
    *   Không bao giờ tồn tại đồng thời với Serial Reader Thread.

*   **`SerialService._read_loop` (threading.Thread) — Thread thường trú:**
    *   Chỉ được tạo SAU KHI DongleDetectWorker đã kết thúc.
    *   `SerialService.open(port)` tạo thread này — **ĐỘC CHIẾM COM port** xuyên suốt vòng đời app.
    *   Chạy vòng lặp vô hạn `serial.read()` để hứng dữ liệu từ phần cứng.
    *   Mọi tác vụ ghi (TX) đều đi qua `SerialService.write()` với `threading.Lock` bảo vệ.

*   **`PeriodicPollWorker` — KHÔNG phải OS Thread:**
    *   Chỉ là các `QTimer` chạy trên Main Thread.
    *   Định kỳ gọi `ProtocolService.send_command()` (battery, BLE status, etc.).
    *   Không tạo thread mới, không mở COM port riêng.

### 2. Cơ chế đồng bộ và giao tiếp (Communication Mechanism)

Nếu luồng Background (như `SerialReadWorker`) trực tiếp thay đổi dữ liệu của Model hoặc gọi hàm vẽ của View, ứng dụng sẽ bị **CRASH** lập tức (Lỗi *Cross-thread UI access* hoặc *Race condition*). 
Vì vậy, luồng giao tiếp được thiết kế bảo mật bằng **Signals** và **Queues**:

*   **Từ Worker ➡️ Main Thread (Sử dụng Qt Signals):**
    *   Khi `SerialReadWorker` đọc được 1 khối byte, nó không tự xử lý mà phát ra một **Signal** (ví dụ: `data_received(bytes)`).
    *   Cơ chế của Qt (QueuedConnection) sẽ tự động bắt lấy tín hiệu này, đưa nó vào một hàng đợi an toàn, rồi Main Thread sẽ từ từ lấy ra xử lý.
    *   Main Thread giao khối byte cho `ProtocolService` để parse thành Protobuf, rồi cập nhật vào Model.

*   **Từ Main Thread ➡️ Hardware (Sử dụng Thread-safe Queue):**
    *   Khi người dùng nhấn nút trên giao diện, ViewModel sẽ ra lệnh tạo ra một mảng bytes.
    *   Thay vì gọi trực tiếp `serial.write()` (có thể bị OS block nếu buffer đầy), Main Thread đẩy mảng bytes này vào một **Thread-safe Queue** (`queue.Queue` trong Python).
    *   Một Service ở dưới (như `SerialService`) sẽ lấy dữ liệu từ Queue này và ghi xuống cổng USB một cách an toàn.

*   **Cơ chế chống tràn RAM (Backpressure & Buffering):**
    *   **Models:** Các model lưu trữ dữ liệu liên tục như `position_history` (Ranging) hay `entries` (Logs) sử dụng cấu trúc dữ liệu có giới hạn (như `collections.deque(maxlen=10000)`). Khi dữ liệu quá nhiều, cái cũ nhất sẽ tự động bị đẩy ra. Nhờ vậy, dù cắm máy chạy 24/7 thì RAM của app vẫn không bị phình to (Memory Leak).
    *   **Data Export/Repository:** Khi người dùng nhấn *End Session*, việc gom toàn bộ dữ liệu ghi xuống ổ cứng sẽ được đẩy sang Background Thread hoặc sử dụng Async I/O để giao diện vẫn mượt mà trong lúc lưu file lớn.

### 3. Cơ chế phân loại và điều phối dữ liệu (Data Routing & Queue)

Vì toàn bộ app kết nối qua duy nhất **1 Dongle**, rủi ro đơ app hoặc sập phần cứng do các Tab "giẫm đạp" lên nhau để giao tiếp là rất cao. Kiến trúc xử lý như sau:

*   **Bộ Điều Phối Trung Tâm (Central Dispatcher - `ProtocolService`):**
    *   Mọi dữ liệu từ Dongle bắn lên đều hội tụ về `ProtocolService`.
    *   Service này đọc mã lệnh (`tag`) và làm nhiệm vụ **Router**.
    *   *Ví dụ:* Gói tin streaming `ranging_result_t` bắn lên 10 lần/giây, `ProtocolService` sẽ **chỉ** phân phối nó về `LiveTrackingViewModel`. Các Tab khác như Info, Config, hay Log sẽ hoàn toàn không nhận được, không bị đánh thức, giúp bảo toàn CPU.

*   **Hàng Đợi Lệnh & Van Điều Tiết (Command Queue & Throttling):**
    *   Nếu Tab 1 đòi đọc Pin, Tab 3 đòi lưu Cấu hình, Tab 4 đòi lấy dữ liệu IMU trong cùng 1 mili-giây, Dongle UART Buffer sẽ bị tràn (Overflow).
    *   **Giải pháp:** Các Tab khi gửi lệnh **không** gọi trực tiếp vào phần cứng. Lệnh được đẩy vào một **Write Queue** (Hàng đợi gửi) nằm trong `SerialService`.
    *   Hệ thống sẽ bốc từng lệnh từ Queue ra, gửi xuống USB, và có khoảng nghỉ vi mô (vài ms) giữa các lệnh. Dongle sẽ không bao giờ bị nghẹn.

### 4. Sơ đồ Luồng (Thread & Concurrency Layout)

Dưới đây là sơ đồ kiến trúc luồng, minh họa rõ vị trí của **Queue** và **Semaphore (Lock)** để ngăn chặn đụng độ (Race Condition) làm crash app:

```text
                                [ MAIN THREAD (UI) ]
 ┌────────────────┐ ┌────────────────┐ ┌────────────────┐ ┌────────────────┐
 │ Tab 1 (Info)   │ │ Tab 2 (Track)  │ │ Tab 3 (Config) │ │ Tab 4 (Log)    │
 └───────┬────────┘ └───────┬────────┘ └───────┬────────┘ └───────┬────────┘
         │ (Gửi lệnh)       │ (Gửi lệnh)       │ (Gửi lệnh)       │
         ▼                  ▼                  ▼                  ▼
 ┌─────────────────────────────────────────────────────────────────────────┐
 │                       ProtocolService (Router)                          │
 └────────────────────────────────────┬────────────────────────────────────┘
                                      │ 1. Đẩy lệnh (bytes) vào Queue
                                      ▼
                      [ Thread-safe WRITE QUEUE ] (queue.Queue)
                                      │
 ═════════════════════════════════════╪═════════════════════════════════════
                                      │ 2. Background Thread lấy lệnh ra
                      [ BACKGROUND THREAD (I/O) ]
                                      │
 ┌────────────────────────────────────▼────────────────────────────────────┐
 │                            SerialService                                │
 │                                                                         │
 │  ┌─────────────────────┐                         ┌───────────────────┐  │
 │  │ SerialWriteWorker   │ ◄── (SEMAPHORE/LOCK) ──►│ SerialReadWorker  │  │
 │  │ (Pop lệnh từ Queue) │    (Bảo vệ cổng USB)    │ (Vòng lặp đọc)    │  │
 │  └────────┬────────────┘                         └─────────▲─────────┘  │
 │           │ 3. serial.write()                              │ 4. read()  │
 └───────────┼────────────────────────────────────────────────┼────────────┘
             ▼                                                │
       [ USB PORT ] ──────────────────────────────────────────┘
```

**Vai trò của các công cụ đồng bộ (Synchronization Tools):**
1.  **Thread-safe Queue (Hàng đợi gửi lệnh):** 
    Dùng để chứa các lệnh từ Main Thread dội xuống. `queue.Queue` tự động xử lý khóa (thread-safe), nên 5 Tab có ra lệnh cùng lúc thì lệnh vẫn xếp hàng ngay ngắn, không bị đè lên nhau.
2.  **Semaphore / Mutex Lock (Khóa bảo vệ cổng USB):**
    Thư viện `pyserial` có thể bị lỗi (Crash cấp OS) nếu có 2 luồng khác nhau cùng thao tác trên 1 cổng COM (một luồng đang `read()` thì luồng kia lại nhào vô `write()`). Để giải quyết, `SerialService` sử dụng một cái khóa (`QMutex` hoặc `threading.Semaphore`). 
    *Luật:* Trọng tài (Semaphore) chỉ cho 1 luồng cầm chìa khóa. Nếu WriteWorker đang gửi lệnh, ReadWorker phải đứng đợi vài mili-giây. Viết xong, trả chìa khóa lại thì ReadWorker mới được đọc. Điều này bảo vệ tuyệt đối cổng Dongle không bị đứng máy.

---

## 📂 Cấu Trúc Thư Mục

```
uwb_rtls_studio/
├── main.py                          # 🚀 Entry point — bootstrapper
├── version.py                       # 📌 Version string
├── README.md                        # 📖 File này
│
├── models/                          # 📦 DATA LAYER
│   ├── __init__.py                  #     Package description
│   ├── dongle_model.py              #     USB dongle state
│   ├── device_model.py              #     BLE devices (scan list, connected)
│   ├── session_model.py             #     Session lifecycle + data bundle + meta
│   ├── ranging_model.py             #     Position data + trajectory history
│   ├── config_model.py              #     All config groups
│   ├── telemetry_model.py           #     Battery, temperature, diagnostics
│   └── log_model.py                 #     Log entries (device + app logs)
│
├── viewmodels/                      # 🧠 LOGIC LAYER
│   ├── __init__.py                  #     Package description + MVVM diagram
│   ├── dongle_viewmodel.py          #     Detect + connect dongle flow
│   ├── scan_viewmodel.py            #     BLE scan + device selection flow
│   ├── main_viewmodel.py            #     Tab switching, session, User/Dev mode
│   ├── device_info_viewmodel.py     #     Tab 1: Device identity + telemetry
│   ├── live_tracking_viewmodel.py   #     Tab 2: Ranging + position updates
│   ├── config_viewmodel.py          #     Tab 3: Config (User+Dev scoped)
│   ├── calibration_viewmodel.py     #     Tab 4: Calibration (Developer only)
│   └── log_viewmodel.py             #     Tab 5: Log + Session History (User+Dev)
│
├── views/                           # 🎨 UI LAYER
│   ├── __init__.py                  #     Package description
│   ├── windows/
│   │   └── main_window.py           #     Main window (tabs + status bar)
│   ├── popups/
│   │   ├── dongle_popup.py          #     Popup 1: Detect dongle
│   │   └── scan_popup.py            #     Popup 2: Scan + connect device
│   ├── tabs/
│   │   ├── device_info_tab.py       #     Tab 1: Device Info (User+Dev)
│   │   ├── live_tracking_tab.py     #     Tab 2: Live Tracking (User+Dev)
│   │   ├── config_tab.py            #     Tab 3: Config (User+Dev scoped)
│   │   ├── calibration_tab.py       #     Tab 4: Calibration (Developer only)
│   │   └── log_tab.py               #     Tab 5: Log + Session History (User+Dev)
│   └── components/
│       ├── status_bar.py            #     Bottom status bar
│       ├── glass_button.py          #     Glassmorphism button
│       ├── position_canvas.py       #     2D position map (QPainter)
│       └── log_text_widget.py       #     Color-coded log display
│
├── services/                        # 🔌 I/O & COMMUNICATION LAYER
│   ├── __init__.py
│   ├── serial_service.py            #     USB/Serial port management
│   ├── protocol_service.py          #     HDLC + Protobuf encode/decode
│   ├── dongle_detect_service.py     #     Auto-detect dongle via protobuf probe
│   └── data_export_service.py       #     Manual export (ad-hoc CSV/JSON)
│
├── repository/                      # 💾 PERSISTENCE LAYER (NEW)
│   ├── __init__.py                  #     Package description
│   ├── session_repository.py        #     Save/load/list session bundles
│   └── session_browser.py           #     Browse + filter past sessions
│
├── workers/                         # ⚡ BACKGROUND THREADS
│   ├── __init__.py
│   ├── serial_read_worker.py        #     (DEPRECATED — merged into SerialService)
│   ├── dongle_detect_worker.py      #     Protobuf probe + port-change monitor + check all COMx 
│   └── periodic_poll_worker.py      #     (Placeholder — dùng QTimer trên Main Thread)
│
├── utils/                           # 🛠 UTILITIES
│   ├── __init__.py
│   ├── constants.py                 #     Probe config, baud rate, timeouts, UI sizes
│   ├── theme.py                     #     Dark theme (QSS stylesheet + colors)
│   └── helpers.py                   #     Format functions, conversions
│
├── resources/                       # 🎨 STATIC ASSETS
│   ├── __init__.py
│   └── icons/
│       └── README.txt               #     Icon inventory list
│
└── data/                            # 💾 SESSION HISTORY (gitignored)
    ├── __init__.py
    └── sessions/                    #     ← Tất cả session history ở đây
        ├── SES_20260530_123000_ranging/
        │   ├── session_meta.json    #     Metadata: type, time, device, stats
        │   ├── positions.csv        #     Position samples
        │   ├── logs.csv             #     Log entries
        │   ├── config_snapshot.json #     Device config snapshot
        │   └── ranging_stats.json   #     Ranging statistics
        ├── SES_20260530_140500_streaming/
        │   ├── session_meta.json
        │   └── logs.csv
        └── ... (all history preserved)
```

---

## 🔄 Application Flow

### Flow 1: Dongle Detection (Startup)

App tự động detect dongle bằng **protobuf handshake** — không dùng VID/PID.
```
App Start → DonglePopup opens → DongleDetectWorker start (background thread)

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

  ┌─── Phase 2: Monitor Port Changes (nếu Phase 1 không tìm thấy) ──────┐
  │                                                                       │
  │  1. Lưu danh sách ports hiện tại: known_ports = {COM1, COM2, ...}         │
  │  2. Mỗi 800ms, so sánh port list hiện tại với known_ports            │
  │     (chỉ gọi list_ports — KHÔNG mở COM port, rất nhẹ)               │
  │  3. Có port MỚI xuất hiện (dongle vừa cắm vào)?                     │
  │     ├─ YES → Đợi 500ms cho driver enumerate → Quay lại Phase 1      │
  │     └─ NO  → Tiếp tục monitor                                       │
  │  4. Hết timeout (30s) → emit timeout → hiện lỗi [Retry] / [Cancel]  │
  │                                                                       │
  └───────────────────────────────────────────────────────────────────────┘

  ┌─── Phase 3: Open & Verify ───────────────────────────────────────────┐
  │                                                                       │
  │  1. DongleDetectWorker thread TỰ KẾT THÚC (end session)                 │
  │  2. DongleModel nhận signal dongle_found(DongleInfo)                 │
  │  3. Mở serial CHÍNH THỨC qua SerialService.open(port)               │
  │     → Tạo SerialReader thread (ĐỘC CHIẾM COM port từ đây)          │
  │  4. Gửi device_information_get qua ProtocolService                   │
  │  5. Nhận device_information_resp?                                     │
  │     ├─ YES → Lấy fw_version, serial, role → ✅ dongle_verified      │
  │     └─ TIMEOUT (3s) → ⚠️ Proceed unverified                        │
  │  6. DonglePopup auto-close → Mở ScanPopup                           │
  │                                                                       │
  └───────────────────────────────────────────────────────────────────────┘
```

**Tại sao không dùng VID/PID?**
- VID/PID phụ thuộc vào USB chip cụ thể (Nordic, STM, etc.) — dễ sai.
- Protobuf handshake xác nhận được firmware thật sự đang chạy trên device.
- Có khả năng bị trùng với VID/PID khác của các device khác nhau.

### Flow 2: BLE Scanning (Scan Popup)

```
ScanPopup opens → Auto send ble_scan_start (tag=51)
              → Dongle scans BLE devices
              → Receive ble_scan_result (tag=54) for each device
              → Display in table: Name | Type | RSSI | MAC | Serial
              → User selects a TAG device
              → Click [Connect]
              → Send ble_connect (tag=53)
              → Log: "Connecting..."
              → Receive confirmation + adv info
              → Log: "✅ Connected to UWB-Tag-01"
              → Close popup → Open MainWindow
```

### Flow 3: Main Window (Tabs)

```
MainWindow opens with connected device
├── Tab 1: Device Info     → device_info, battery, ble_status     (User+Dev)
├── Tab 2: Live Tracking   → ranging_start/stop/result            (User+Dev)
├── Tab 3: Config          → anchor layout, time sync, UWB, ...   (User+Dev scoped)
├── Tab 4: Calibration     → pos_calib, calib_status, IMU         (Developer only)
└── Tab 5: Log & History   → device logs, session history browser  (User+Dev)

[End Session] → Dừng protobuf activities → Save session → Browse later
[Close Window] → Full app shutdown
```

### Flow 4: End Session (Chi tiết)

```
User đang ranging/streaming/log
         │
         ▼
    [🔴 End Session] clicked
         │
         ├─ 1. Gửi end_session_t (tag=65) với reason phù hợp
         │     - SESSION_END_REASON_RANGING_RESULTS  (nếu ranging)
         │     - SESSION_END_REASON_DEBUG_STREAMING   (nếu streaming)
         │     - SESSION_END_REASON_LOG_DATA          (nếu log upload)
         │
         ├─ 2. Dừng protobuf activities
         │     - ranging_stop_t (nếu ranging)
         │     - Stop log stream (nếu streaming)
         │     ⚠ KHÔNG disconnect dongle / BLE / device
         │
         ├─ 3. Bundle toàn bộ session data
         │     - SessionState (type, time, stats)
         │     - Positions CSV (nếu ranging)
         │     - Logs CSV (tất cả log trong session)
         │     - Config snapshot JSON
         │     - Ranging stats JSON (nếu ranging)
         │     - Device info + Dongle info
         │
         ├─ 4. Save vào Repository
         │     → data/sessions/SES_20260530_123000_ranging/
         │     → session_meta.json + positions.csv + logs.csv + ...
         │     → Session được lưu VĨNH VIỄN (không tự xóa)
         │
         ├─ 5. App vẫn chạy bình thường
         │     - Dongle vẫn connected (USB serial)
         │     - BLE device vẫn connected
         │     - Có thể bắt đầu session mới ngay
         │
         └─ 6. User browse session history bất kỳ lúc nào
               → Tab 5 (Log & History) → Session History section
               → Open session → xem lại data để debug
```

### Flow 5: Kill App (khác End Session)

```
User đóng window hoặc File > Exit
         │
         ├─ Nếu session đang active → auto End Session + save trước
         ├─ Disconnect BLE (ble_disconnect_t)
         ├─ Close serial port
         ├─ Stop all worker threads
         ├─ Cleanup resources
         └─ Exit process (sys.exit)
```

---

## 🖥 User Mode vs Developer Mode

### Tab Visibility

| Tab | User Mode | Developer Mode |
|-----|---|---|
| Tab 1: Device Info | ✅ Full | ✅ Full |
| Tab 2: Live Tracking | ✅ Full | ✅ Full |
| Tab 3: Config | ✅ User sections | ✅ All sections |
| Tab 4: Calibration | ❌ **Hidden** | ✅ Full |
| Tab 5: Log & History | ✅ Device logs | ✅ All logs |

### Config Tab — Section Visibility

| Config Section | User Mode | Developer Mode |
|---|---|---|
| 👤 Anchor/Tag Layout | ✅ Read | ✅ Read/Write |
| 👤 Time Synchronization | ✅ Read/Write | ✅ Read/Write |
| 👤 Ranging Configuration | ✅ Read/Write | ✅ Read/Write |
| 👤 UWB Basic Info | ✅ Read-only | ✅ Read/Write |
| 🔧 UWB Advanced Config | ❌ Hidden | ✅ Read/Write |
| 🔧 Sensor Fusion (UKF) | ❌ Hidden | ✅ Read/Write |
| 🔧 BLE Connection Params | ❌ Hidden | ✅ Read/Write |
| 🔧 System Commands | ❌ Hidden | ✅ |

### Log Tab — Content Visibility

| Log Content | User Mode | Developer Mode |
|---|---|---|
| Device Logs (INFO/WARN/ERROR) | ✅ | ✅ |
| Device Logs (DEBUG) | ❌ Filtered | ✅ |
| App Internal Logs | ❌ Hidden | ✅ |
| Raw Protocol Logs (TX/RX) | ❌ Hidden | ✅ |
| Session History Browser | ✅ | ✅ |
| Export CSV/TXT | ✅ | ✅ |
| Clear Device Logs | ❌ Hidden | ✅ |
| Advanced Filters | ❌ Hidden | ✅ |

Toggle via dropdown/button in title bar.

---

## 📡 Protocol Dependency

Toàn bộ communication sử dụng **Protobuf** messages qua **HDLC framing**.

| Layer | Module | Location |
|---|---|---|
| Proto defs | `protocol.proto` | `protocol/protos/` |
| Python bindings | `protocol_pb2.py` | `software/common/` |
| HDLC + Parser | `transport.py` | `software/common/` |
| Command factory | `commands.py` | `software/common/` |

Packet flow:
```
ViewModel → CommandFactory.build() → ProtocolService.encode()
         → SerialService.write() → USB → Dongle → BLE → Device

Device → BLE → Dongle → USB → SerialService.read()
       → ProtocolService.decode() → dispatch → ViewModel
```

---

## 📦 Dependencies

| Package | Version | Purpose |
|---|---|---|
| PyQt6 | ≥ 6.5 | Qt GUI framework |
| pyserial | ≥ 3.5 | Serial/USB communication |
| protobuf | ≥ 4.0 | Protocol buffer runtime |

---

## 🚧 Development Status

- [x] Project layout (MVVM + Repository structure)
- [x] File scaffolding with documentation
- [x] Session persistence design (Repository layer)
- [x] Models implementation (dataclasses)
- [x] Services implementation (serial, protocol, dongle detect)
- [x] Workers implementation (DongleDetectWorker — protobuf probe)
- [x] ViewModels implementation (dongle, scan, device info, tracking)
- [x] Views implementation (PyQt6 UI — popups, tabs, main window)
- [x] Theme & styling (dark theme, glassmorphism)
- [x] Dongle auto-detection (protobuf handshake, event-based)
- [ ] Repository implementation (session save/load)
- [ ] PeriodicPollWorker (battery, BLE status)
- [ ] Calibration tab (Developer mode)
- [ ] Icon assets
- [ ] Testing
- [ ] Build & packaging

---

## ✍ Author

**Trung Quan** — UWB RTLS Project  
Date: 2026

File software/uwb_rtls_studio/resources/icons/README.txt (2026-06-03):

# This directory contains icon assets for the UWB RTLS Studio application.
# 
# Required icons (SVG preferred, PNG fallback):
#   - app_icon.png          → Application icon (256x256)
#   - dongle.svg            → USB dongle icon
#   - tag.svg               → Tag device icon
#   - anchor.svg            → Anchor device icon
#   - battery_full.svg      → Battery 75-100%
#   - battery_mid.svg       → Battery 25-75%
#   - battery_low.svg       → Battery 0-25%
#   - signal_strong.svg     → RSSI > -50 dBm
#   - signal_medium.svg     → RSSI -50 to -70 dBm
#   - signal_weak.svg       → RSSI < -70 dBm
#   - connected.svg         → Green dot / checkmark
#   - disconnected.svg      → Red dot / X
#   - tab_info.svg          → Tab 1 icon
#   - tab_tracking.svg      → Tab 2 icon
#   - tab_config.svg        → Tab 3 icon
#   - tab_calib.svg         → Tab 4 icon
#   - tab_log.svg           → Tab 5 icon
#   - btn_start.svg         → Play / Start
#   - btn_stop.svg          → Stop / Square
#   - btn_refresh.svg       → Refresh / Reload
#   - btn_export.svg        → Download / Export
#   - btn_end_session.svg   → End session (red)
#
# Placeholder: Using emoji icons until proper SVG assets are created.

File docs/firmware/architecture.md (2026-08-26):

# Embedded Firmware Architecture

[Documentation home](../README.md) | [Firmware guide](README.md) | [Ranging protocol](ranging_protocol.md)

One STM32 firmware image supports both Tag and Anchor roles. Configuration selects the runtime behavior; hardware access and platform services remain shared.

## Runtime Roles

| Concern | Tag | Anchor |
|---|---|---|
| UWB | Initiates scheduled DS-TWR exchanges | Responds to DS-TWR exchanges |
| Positioning | Runs preprocessing, Anchor selection and UKF | Disabled |
| IMU | Supplies UKF prediction data | Platform service only |
| Communication | Commands and positioning telemetry | Configuration and status |

## Firmware Structure

```text
firmware/uwb/
|-- app/                  Tag and Anchor application state machines
|-- sys/                  Ranging, fusion, configuration, logging and power services
|-- middlewares/          TDMA, filters, trilateration and reusable state machines
|-- bsp/                  Board-level UWB, IMU, Flash, battery and I/O access
|-- deca/                 DW1000 driver adaptation
|-- Drivers/              STM32 HAL and CMSIS
|-- Middlewares/          FreeRTOS and third-party libraries
|-- USB_DEVICE/           USB CDC device stack
`-- Core/
    |-- Src/freertos.c    Tasks, queues, semaphores and mutexes
    `-- Inc/              Shared RTOS handles and application interfaces
```

Role logic stays in `app/`; system workflows stay in `sys/`; hardware access stays behind `bsp/`. This is the practical dependency boundary represented by thesis Figure 4.3.

<div align="center">

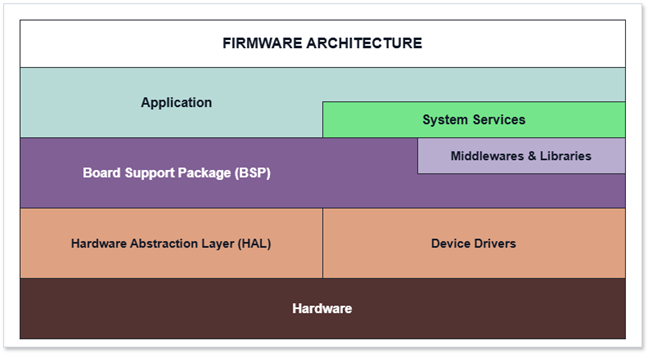
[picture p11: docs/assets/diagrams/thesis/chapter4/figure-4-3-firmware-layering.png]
Firmware Layering Architecture


</div>

## FreeRTOS Execution Architecture

The firmware uses a **preemptive, priority-based scheduler** on a single-core STM32F411. Tasks do not execute in parallel. The highest-priority task in the Ready state owns the CPU; queues, semaphores and delays move inactive tasks to the Blocked state.

```text
Higher urgency
|
|-- Realtime       UwbRanging
|-- High           SensorFusion
|-- Normal         Network
|-- BelowNormal    SysMonitoring
`-- Low
    |-- FlashStorage
    |-- IO
    `-- PM
Lower urgency
```

This ordering protects DS-TWR deadlines first, then positioning computation. Communication, monitoring, storage and power services run when the real-time path is blocked.

### Task Responsibilities

| Task | Priority | Stack | Activation | Responsibility |
|---|---:|---:|---|---|
| `UwbRanging` | Realtime | 6144 B | DW1000 semaphore or dynamic ranging deadline | Dispatches the DW1000 ISR work and advances the Tag/Anchor state machine |
| `SensorFusion` | High | 8192 B | Tag only; waits up to 20 ms for a UWB frame | Reads IMU data, predicts the UKF, preprocesses ranges, selects Anchors and performs the range update |
| `Network` | Normal | 4096 B | Service loop with 2 ms delay | Processes commands, serial transport and BLE peripheral service |
| `SysMonitoring` | BelowNormal | 2048 B | Every 30 s | Samples CPU, heap and task stack health, then publishes RTOS telemetry |
| `FlashStorage` | Low | 1536 B | Every 2 s | Flushes buffered logs to Flash when Flash logging is enabled |
| `IO` | Low | 1536 B | Button semaphore or 100 ms timeout | Handles button events, LED timing, ranging toggle and role-change reboot |
| `PM` | Low | 2560 B | Every 100 ms | Runs battery/power policy and uses SPI only when ranging is idle |

### Real-Time Ranging Path

```text
DW1000 EXTI interrupt
`-- release g_uwb_isr_sem
    `-- UwbRanging wakes at Realtime priority
        |-- lock g_spi1_mutex
        |-- dispatch DW1000 event
        |-- run Tag or Anchor state machine
        |-- unlock g_spi1_mutex
        `-- block until the next interrupt or protocol deadline
```

The hardware interrupt only signals work. Protocol processing runs in task context, where the state machine can safely use drivers, logging and RTOS services. A dynamic timeout also wakes `UwbRanging` when the next protocol deadline arrives without an interrupt.

### Tag Positioning Path

```text
UwbRanging / app_tag
`-- completed ranging frame
    `-- g_uwb_distance_queue [4 frames]
        `-- SensorFusion
            |-- discard queued stale frames; retain the newest frame
            |-- read IMU sample
            |   `-- g_imu_data_queue [8 samples]
            |       `-- drain samples and retain the newest for prediction
            |-- UKF prediction
            |-- range projection and prefilter
            |-- robust weights and Anchor-triplet selection
            |-- trilateration for initialization/diagnostics
            |-- UKF update from three ranges
            `-- publish fusion telemetry
```

`SensorFusion` exits immediately on an Anchor. Therefore Anchor firmware keeps the ranging, network, monitoring, I/O and power tasks but does not allocate runtime CPU to the positioning loop.

### Synchronization and Resource Ownership

| RTOS object | Producer / requester | Consumer / owner | Contract |
|---|---|---|---|
| `g_uwb_isr_sem` | DW1000 EXTI, ranging-control requests and IO ranging toggle | `UwbRanging` | Transfers UWB events into task context without performing long work in the ISR |
| `g_io_btn_sem` | Button EXTI | `IO` | Wakes button processing immediately; 100 ms timeout also services LED timing |
| `g_uwb_distance_queue` | `app_tag` | `SensorFusion` | Capacity 4; transfers complete range frames without sharing a mutable frame buffer |
| `g_imu_data_queue` | Sensor-fusion IMU acquisition | UKF prediction | Capacity 8; decouples sampling from prediction and allows stale samples to be drained |
| `g_spi1_mutex` | UWB, IMU and PM code | Current lock holder | Serializes the shared SPI bus; UWB holds it only around DW1000 dispatch |
| `g_logger_mutex` | Any logging task | Logger | Protects the shared RAM logging state |
| RAM log buffer | Logger | `FlashStorage` | Defers slow Flash writes away from the UWB timing path |

### Scheduling Semantics

| Situation | Scheduler behavior | Design consequence |
|---|---|---|
| DW1000 interrupt arrives | `UwbRanging` becomes Ready and preempts lower-priority work | Ranging deadlines take precedence over fusion and services |
| No UWB event is pending | `UwbRanging` blocks on its semaphore with a deadline timeout | CPU is available to other tasks |
| Several UWB frames accumulate | `SensorFusion` drains the queue and processes only the newest | Bounds latency instead of replaying obsolete positions |
| SPI is busy | IMU/UWB waits on the mutex; PM uses a non-blocking attempt | Power telemetry cannot delay active ranging |
| Log data is produced | Data remains in RAM until the background flush | Flash latency is removed from the critical UWB path |

### Task Execution Timing & Periodic Semantics

| Task | Execution Period / Trigger | Scheduling Behavior |
|---|---|---|
| `UwbRanging` | Event-driven (UWB Semaphore) + dynamic deadline timeout | Realtime preemption for timestamp dispatch |
| `SensorFusion` | Event-driven (Wait up to 20 ms for UWB distance queue) | Drains stale frames, executes UKF prediction & update |
| `Network` | 2 ms periodic service | Processes serial packets and BLE telemetry |
| `SysMonitoring` | 30 s periodic | Samples CPU load, heap usage, and stack watermarks |
| `FlashStorage` | 2 s periodic | Flushes RAM log buffers to persistent Flash |
| `PM` | 100 ms periodic | Battery voltage sensing and thermal policy |
| `IO` | Button EXTI + 100 ms timeout | Debounces pushbutton and services LED blink patterns |

## Source Traceability

| Concern | Source |
|---|---|
| Tasks, priorities and RTOS objects | `firmware/uwb/Core/Src/freertos.c` |
| ISR-to-task UWB signaling | `firmware/uwb/bsp/bsp_uwb.c` |
| Completed range-frame producer | `firmware/uwb/app/app_tag.c` |
| IMU queue and UKF ownership | `firmware/uwb/sys/sys_sensor_fusion.c` |
| Button ISR signaling | `firmware/uwb/bsp/bsp_io.c` |

## Continue Reading

- [UWB ranging protocol](ranging_protocol.md)
- [Embedded positioning algorithms](positioning_algorithms.md)

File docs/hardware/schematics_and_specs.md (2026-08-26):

# Hardware Specifications & Schematics

[Documentation Home](../README.md) · [Getting Started](../getting_started.md) · [Antenna Calibration](antenna_calibration.md) · [Deployment Guide](../deployment.md)

This document provides visual hardware references, 3D PCB layouts, component specifications, and pinout mappings for the **UWB-RTLS** hardware ecosystem.

---

## 1. Hardware Ecosystem Overview

<div align="center">

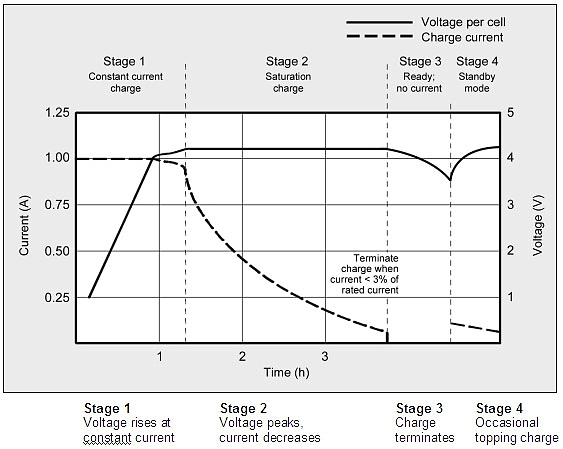
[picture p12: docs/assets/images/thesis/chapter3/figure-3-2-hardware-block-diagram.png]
Hardware System Architecture


</div>

The UWB-RTLS system utilizes three dedicated hardware entities designed for distinct roles in the positioning infrastructure:

| Hardware Entity | Core MCU | RF / Sensing Hardware | Power Supply | Primary System Role |
| --- | --- | --- | --- | --- |
| **Tag Board** | STM32F411CEU6 | DW1000 + 6-DOF IMU + nRF52832 | 3.7V LiPo / 5V USB | Mobile ranging, UKF fusion, USB pose stream |
| **Anchor Board** | STM32F411CEU6 | DW1000 + nRF52832 + 3-bit DIP | 5.0V USB Type-C | Fixed reference beacons (ID 0..7) |
| **USB Dongle Gateway** | Nordic nRF52840 | BLE 5.0 Central Controller | USB VBUS | Wireless telemetry bridge to PC GUI |

---

## 2. Tag Board Hardware

The Tag board is mounted directly onto the Autonomous Mobile Robot (AMR). It performs real-time DS-TWR ranging, reads high-rate inertial measurements from the 6-DOF IMU, executes the onboard 8-State UKF, and streams pose telemetry over USB CDC.

| Tag PCB Front (DW1000, STM32F411, 6-DOF IMU) | Tag PCB Back (nRF52832 BLE, LiPo Circuit) |
| :---: | :---: |
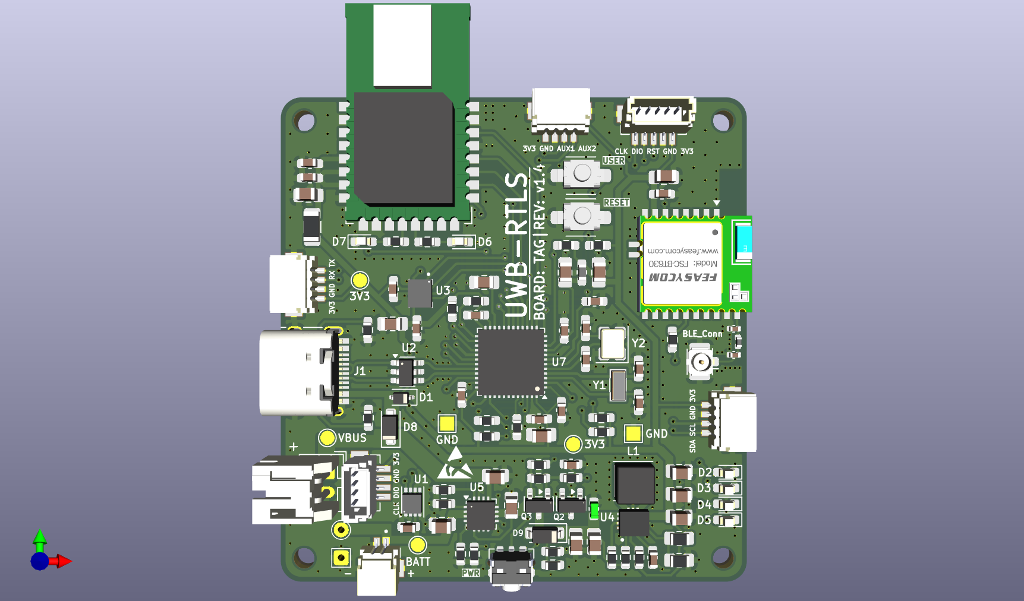
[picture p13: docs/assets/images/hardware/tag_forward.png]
Tag PCB Front
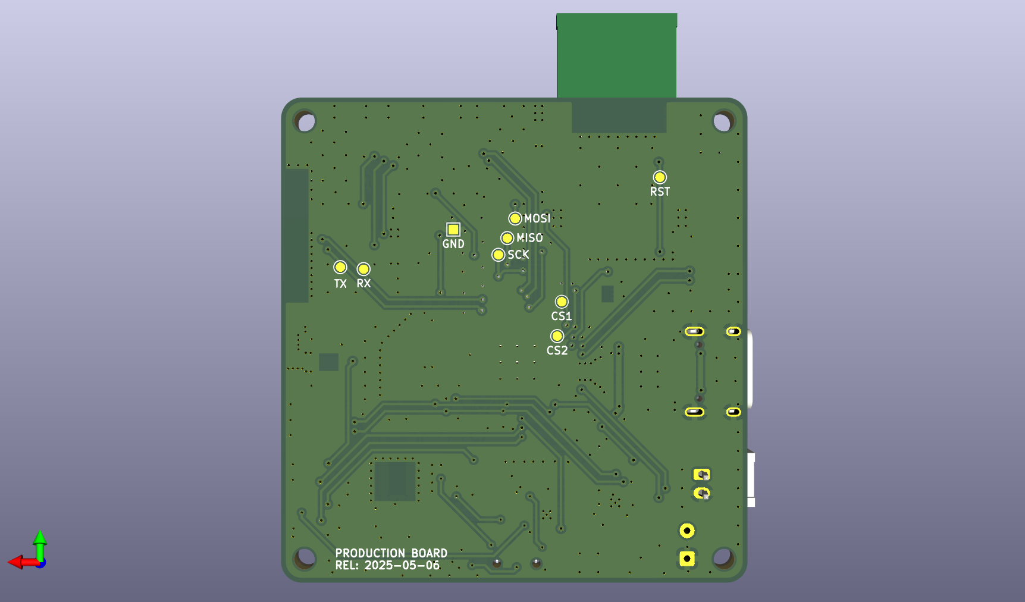
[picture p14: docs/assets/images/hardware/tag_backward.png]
Tag PCB Back
|  |  |

| Subsystem | Component | Interface | Key Function |
| --- | --- | --- | --- |
| **MCU** | STM32F411CEU6 | 100 MHz Cortex-M4F | Runs FreeRTOS, DS-TWR ranging, and 8-State UKF fusion |
| **UWB Radio** | Decawave DW1000 / BU01 | SPI1 @ 20 MHz + PB0 (EXTI) | Sub-nanosecond timestamping for time-of-flight |
| **Inertial Sensor** | 6-DOF IMU (Accel + Gyro) | SPI2 @ 100 Hz | High-rate motion prediction for UKF state propagation |
| **Wireless Bridge** | Nordic nRF52832 | USART1 @ 115200 baud | BLE 5.0 telemetry broadcast and OTA configuration |
| **Robot Link** | USB Type-C OTG FS | USB CDC Virtual COM | Streams real-time pose (`px, py, vx, vy, yaw`) to robot computer |
| **User Control** | Pushbutton (`PA0`) | EXTI0 | Hold ~3s: Role toggle & reboot; Click: Toggle ranging |

---

## 3. Anchor Board Hardware

Anchor boards are installed at fixed, surveyed coordinates around the tracking perimeter. Each Anchor responds to Tag ranging polls within its allocated TDMA time slot.

| Anchor PCB Front (DW1000, STM32, 3-bit DIP) | Anchor PCB Back (nRF52832 BLE, 5V LDO Rail) |
| :---: | :---: |
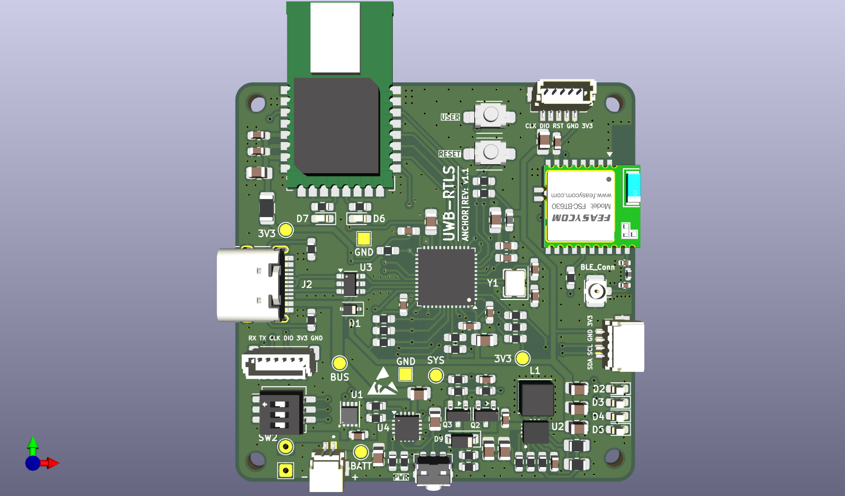
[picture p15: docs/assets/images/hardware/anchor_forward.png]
Anchor PCB Front
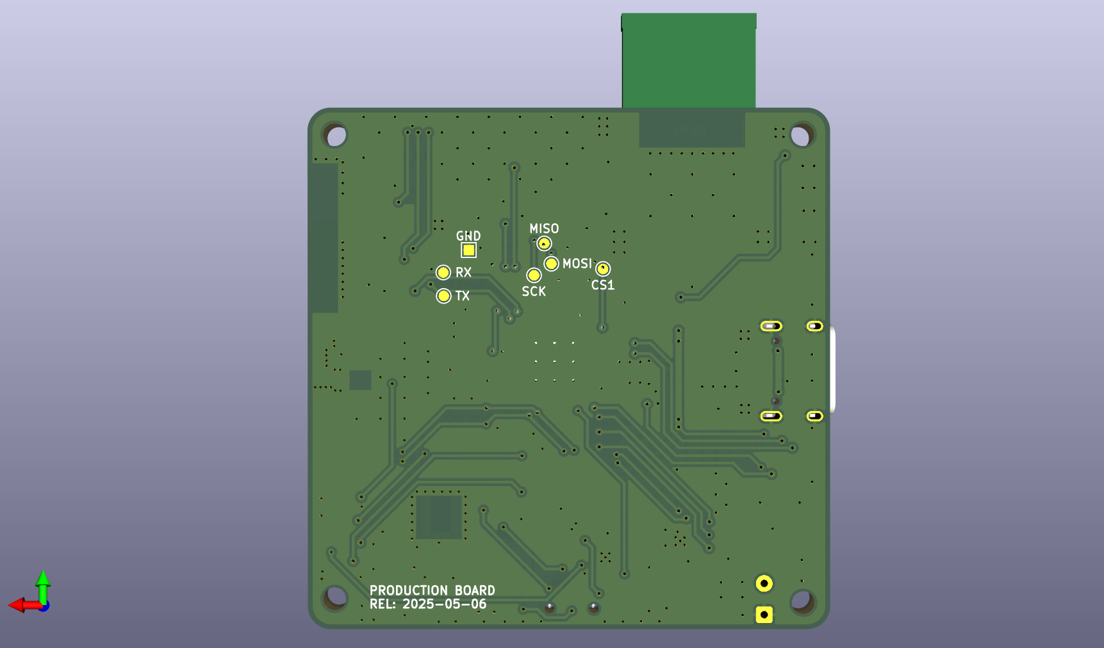
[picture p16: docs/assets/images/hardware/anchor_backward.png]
Anchor PCB Back
|  |  |

| Subsystem | Component | Interface | Key Function |
| --- | --- | --- | --- |
| **MCU** | STM32F411CEU6 | 100 MHz Cortex-M4F | Manages DW1000 RX/TX timing and packet compilation |
| **UWB Radio** | Decawave DW1000 / BU01 | SPI1 @ 20 MHz + PB0 (EXTI) | Transmits timestamped response frames |
| **ID Selector** | 3-position DIP Switch (`SW1`) | `PB3..PB5` (Inputs) | Configures Anchor ID ($0 \dots 7$, up to 8 Anchors) |
| **Wireless Bridge** | Nordic nRF52832 | USART1 @ 115200 baud | BLE 5.0 diagnostic status reporting |
| **Power Input** | 5.0V USB Type-C | Dual High-PSRR LDOs | Supplies isolated 3.3V power to digital and RF stages |

---

## 4. MCU Pinout & Interface Mapping

| Peripheral | STM32 Pin Assignment | Connected Hardware | Function & Protocol |
| --- | --- | --- | --- |
| **SPI1** | `PA5 (SCK)`, `PA6 (MISO)`, `PA7 (MOSI)`, `PA4 (NSS)` | Decawave DW1000 | 20 MHz transceiver register read/write & frame buffer access |
| **EXTI0** | `PB0` | Decawave DW1000 `IRQ` | Hardware microsecond interrupt on TX/RX timestamp event |
| **SPI2** | `PB13 (SCK)`, `PB14 (MISO)`, `PB15 (MOSI)`, `PB12 (NSS)` | 6-DOF IMU (Tag Only) | Synchronous $100\text{ Hz}$ accelerometer and gyroscope sampling |
| **USART1** | `PA9 (TX)`, `PA10 (RX)` | Nordic nRF52832 | Bidirectional Protobuf packet transport between MCU and BLE |
| **USB OTG FS** | `PA11 (DM)`, `PA12 (DP)` | Robot Controller / PC | USB CDC pose streaming ($10\text{ Hz}$) and USB DFU flashing |
| **GPIO Button** | `PA0` (EXTI) | User Pushbutton | Hold ~3s: Toggle Tag/Anchor role & reboot; Click: Toggle ranging |
| **GPIO DIP** | `PB3..PB5` (Inputs) | 3-position DIP Switch (Anchor) | Configures Anchor ID ($0 \dots 7$, up to 8 Anchors) |
| **ADC1** | `PA1` | Battery Divider (Tag) | Real-time LiPo battery voltage sensing |

---

## 5. Hardware Projects & Manufacturing Files

All KiCad PCB project source files, schematics, and manufacturing Gerbers are organized in the repository:

| Board Project | KiCad Source Project | Schematic PDF | Production Gerbers |
| --- | --- | --- | --- |
| **Tag Board** | `hardware/tag/` | [Tag Schematic PDF](../assets/schematics/tag_schematic.pdf) | `hardware/tag/tag_genber/` |
| **Anchor Board** | `hardware/anchor/` | [Anchor Schematic PDF](../assets/schematics/anchor_schematic.pdf) | `hardware/anchor/anchor_genber/` |

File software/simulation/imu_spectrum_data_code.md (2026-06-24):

# Trich code Spectrum / Data / IMU

File nay gom cac doan code lien quan den luong du lieu IMU, xu ly LPF/ZUPT, tinh spectrum va cap nhat bieu do tu:

- `software/simulation/uwb-rtls_simulation.py`
- `software/simulation/src/core/config.js`
- `software/simulation/src/core/math_utils.js`
- `software/simulation/src/filters/ukf_prefilter.js`
- `software/simulation/src/workers/sim_worker.js`
- `software/simulation/src/view/plot_init.js`
- `software/simulation/src/view/plot_updater.js`
- `software/simulation/src/controller/ui_controller.js`
- `software/simulation/src/controller/ui_utils.js`

## `software/simulation/uwb-rtls_simulation.py`

### Parse log: lay du lieu IMU `ax`, `ay`, `gz` va payload data

```python
def parse_log(filepath):
    data = []
    pattern = re.compile(r"""
        (?P<type>Update|Init|Predict)          # Loai log
        \s+ax:\s*(?P<ax>[\d.-]+)               # Accel X
        \s+ay:\s*(?P<ay>[\d.-]+)               # Accel Y
        \s+gz:\s*(?P<gz>[\d.-]+)               # Gyro Z
        \s+px:\s*(?P<px>[\d.-]+)               # Pos X (Firmware)
        \s+py:\s*(?P<py>[\d.-]+)               # Pos Y (Firmware)
        \s+dt:\s*(?P<dt>[\d.-]+)               # Delta Time
        .*?                                    # Skip unknown content
        (?:mask:\s*(?P<mask>\d+)\s+)?          # Anchor Mask (Optional)
        d1:\s*(?P<d1>[\d.-]+)\s+               # Distance 1
        d2:\s*(?P<d2>[\d.-]+)\s+               # Distance 2
        d3:\s*(?P<d3>[\d.-]+)\s+               # Distance 3
        d4:\s*(?P<d4>[\d.-]+)                  # Distance 4
        \s+err:\s*(?P<err>\d+)                 # Error Code
    """, re.VERBOSE)
    try:
        with open(filepath, 'r', encoding='utf-8') as f:
            for line_no, line in enumerate(f, 1):
                raw_line = line.rstrip('\r\n')
                m = pattern.search(line)
                if m:
                    d = m.groupdict()

                    def parse_float_list(s):
                        return [float(x.strip()) for x in (s or "").split(',') if x.strip()] or [0,0,0,0]

                    def parse_quality(prefix):
                        bracket = re.search(rf"{prefix}:\s*\[([\d.,\s-]+)\]", raw_line)
                        if bracket:
                            return parse_float_list(bracket.group(1))

                        values = []
                        for anchor_idx in range(1, 5):
                            scalar = re.search(rf"{prefix}{anchor_idx}:\s*([\d.-]+)", raw_line)
                            values.append(float(scalar.group(1)) if scalar else 0)
                        return values

                    amp_vals = parse_quality('amp') if 'amp' in raw_line or 'fp_amp_norm' in raw_line else [0,0,0,0]
                    snr_vals = parse_quality('snr') if 'snr' in raw_line or 'fp_snr' in raw_line else [0,0,0,0]

                    amp_vals = [v if (math.isfinite(v) and -5000.0 < v < 5000.0) else 0.0 for v in amp_vals]
                    snr_vals = [v if (math.isfinite(v) and -5000.0 < v < 5000.0) else 0.0 for v in snr_vals]

                    data.append({
                        'line_no': line_no,
                        'raw_line': raw_line,
                        'type': d['type'],
                        'ax': float(d['ax']), 'ay': float(d['ay']), 'gz': float(d['gz']),
                        'px_fw': float(d['px']), 'py_fw': float(d['py']), 'dt': float(d['dt']),
                        'fp_amp_norm': amp_vals,
                        'fp_snr': snr_vals,
                        'mask': int(d['mask']) if d.get('mask') else 15,
                        'distances': [float(d['d1']), float(d['d2']), float(d['d3']), float(d['d4'])],
                        'err': int(d['err'])
                    })
    except: pass
    return data
```

```python
def run_gen(log_file):
    log_data = parse_log(log_file)
    if not log_data: return None
    bias = {'ax': 0.0, 'ay': 0.0, 'gz': 0.0}
    fw_path = {'x': [], 'y': [], 'mask': []}
    fp_logs = {'amp': [[], [], [], []], 'snr': [[], [], [], []]}

    for entry in log_data:
        if entry['type'] == 'Init':
            bias['ax'], bias['ay'], bias['gz'] = entry['ax'], entry['ay'], entry['gz']
        if entry['type'] == 'Update':
            fw_path['x'].append(entry['px_fw'])
            fw_path['y'].append(entry['py_fw'])
            fw_path['mask'].append(entry.get('mask', 15))
            for i in range(4):
                val_amp = entry['fp_amp_norm'][i] if len(entry.get('fp_amp_norm', [])) > i else 0
                val_snr = entry['fp_snr'][i] if len(entry.get('fp_snr', [])) > i else 0
                fp_logs['amp'][i].append(val_amp)
                fp_logs['snr'][i].append(val_snr)

    payload = {
        'fw_path': fw_path,
        'fp_logs': fp_logs,
        'all_entries': log_data,
        'biases': bias,
        'thumb_svg': f'<svg viewBox="0 0 60 60">{svg_content}</svg>'
    }
    return payload
```

## `software/simulation/src/core/config.js`

### Cau hinh IMU / Dead Reckoning

```javascript
// --- IMU / Dead Reckoning ---
IMU: {
    VELOCITY_DECAY: 0.98,   // Velocity damping factor
    DEFAULT_ENABLE_ZUPT_UKF: false,
    ZUPT_COUNT_THRESHOLD: 10,
    DEFAULT_ZUPT_ACC: 0.15,
    DEFAULT_ZUPT_GYR: 0.05,
    DEFAULT_ENABLE_LPF: true,
    DEFAULT_LPF_CUTOFF_HZ: 2.0
},
```

## `software/simulation/src/core/math_utils.js`

### Tinh spectrum tu du lieu time-domain

```javascript
function computeTimeDomainSpectrum(values, times) {
    const clean = [];
    const cleanTimes = [];
    values.forEach((v, i) => {
        const t = times && times[i];
        if (Number.isFinite(v) && Number.isFinite(t)) {
            clean.push(v);
            cleanTimes.push(t);
        }
    });

    const n = clean.length;
    if (n < 4) return { freq: [], mag: [] };

    const maxFftSize = 16384;
    let nfft = 1;
    while ((nfft * 2) <= n && (nfft * 2) <= maxFftSize) nfft *= 2;
    if (nfft < 4) return { freq: [], mag: [] };

    const start = Math.max(0, n - nfft);
    const duration = cleanTimes[start + nfft - 1] - cleanTimes[start];
    const fs = duration > 0 ? (nfft - 1) / duration : 0;
    if (!Number.isFinite(fs) || fs <= 0) return { freq: [], mag: [] };

    let mean = 0;
    for (let i = 0; i < nfft; i++) mean += clean[start + i];
    mean /= nfft;

    const re = new Array(nfft);
    const im = new Array(nfft).fill(0);
    let windowSum = 0;
    for (let i = 0; i < nfft; i++) {
        const w = 0.5 - 0.5 * Math.cos((2 * Math.PI * i) / (nfft - 1));
        re[i] = (clean[start + i] - mean) * w;
        windowSum += w;
    }

    for (let i = 1, j = 0; i < nfft; i++) {
        let bit = nfft >> 1;
        for (; j & bit; bit >>= 1) j ^= bit;
        j ^= bit;
        if (i < j) {
            const tr = re[i]; re[i] = re[j]; re[j] = tr;
            const ti = im[i]; im[i] = im[j]; im[j] = ti;
        }
    }

    for (let len = 2; len <= nfft; len <<= 1) {
        const angle = -2 * Math.PI / len;
        const wLenRe = Math.cos(angle);
        const wLenIm = Math.sin(angle);
        for (let i = 0; i < nfft; i += len) {
            let wRe = 1;
            let wIm = 0;
            const half = len >> 1;
            for (let j = 0; j < half; j++) {
                const uRe = re[i + j];
                const uIm = im[i + j];
                const vRe = re[i + j + half] * wRe - im[i + j + half] * wIm;
                const vIm = re[i + j + half] * wIm + im[i + j + half] * wRe;
                re[i + j] = uRe + vRe;
                im[i + j] = uIm + vIm;
                re[i + j + half] = uRe - vRe;
                im[i + j + half] = uIm - vIm;

                const nextWRe = wRe * wLenRe - wIm * wLenIm;
                wIm = wRe * wLenIm + wIm * wLenRe;
                wRe = nextWRe;
            }
        }
    }

    const freq = [];
    const mag = [];
    const scale = windowSum > 0 ? 2 / windowSum : 2 / nfft;
    for (let k = 1; k <= Math.floor(nfft / 2); k++) {
        freq.push(k * fs / nfft);
        mag.push(scale * Math.sqrt(re[k] * re[k] + im[k] * im[k]));
    }

    return { freq, mag };
}
```

## `software/simulation/src/filters/ukf_prefilter.js`

### UKF predict dung IMU

```javascript
predict(imu, dt) {
    if (!this.is_initialized) return;
    if (!Number.isFinite(dt) || dt <= 0) return;

    const imuAx = Number.isFinite(imu.ax) ? imu.ax : this.x[5];
    const imuAy = Number.isFinite(imu.ay) ? imu.ay : this.x[6];
    const imuGz = Number.isFinite(imu.gz) ? imu.gz : this.x[7];

    // Generate augmented state/covariance, sigma points...

    for (let m = 0; m < this.num_sigmas; m++) {
        const sp = sigma_pts[m];
        const px = sp[0], py = sp[1], vx = sp[2], vy = sp[3], theta = sp[4];
        const bax = sp[5], bay = sp[6], bgz = sp[7];
        const n_ax = sp[8], n_ay = sp[9], n_gz = sp[10];

        const corrected_ax = imuAx - bax + n_ax;
        const corrected_ay = imuAy - bay + n_ay;
        const corrected_gz = imuGz - bgz + n_gz;

        const theta_new = normalizeAngle(theta + corrected_gz * dt);
        const cos_t = Math.cos(theta);
        const sin_t = Math.sin(theta);

        const ax_world = corrected_ax * cos_t - corrected_ay * sin_t;
        const ay_world = corrected_ax * sin_t + corrected_ay * cos_t;

        this.X_sigma_pred[m][0] = px + vx * dt + 0.5 * ax_world * dt * dt;
        this.X_sigma_pred[m][1] = py + vy * dt + 0.5 * ay_world * dt * dt;
        this.X_sigma_pred[m][2] = vx + ax_world * dt;
        this.X_sigma_pred[m][3] = vy + ay_world * dt;
        this.X_sigma_pred[m][4] = theta_new;
        this.X_sigma_pred[m][5] = bax;
        this.X_sigma_pred[m][6] = bay;
        this.X_sigma_pred[m][7] = bgz;
    }
}
```

## `software/simulation/src/workers/sim_worker.js`

### Khoi tao plot data va series cho spectrum

```javascript
const plotData = {
    vx_raw: [], vy_raw: [], vx: [], vy: [], vx_lpf: [], vy_lpf: [], zupt: [], ax: [], ay: [], gz: [],
    ax_lpf: [], ay_lpf: [], gz_lpf: [], yaw: [], times: [],
    ukf_yaw: []
};

const imuSpectrumSeries = {
    times: [],
    ax: [],
    ay: [],
    ax_lpf: [],
    ay_lpf: []
};
```

### Loc IMU bang LPF

```javascript
const applyImuLpf = (entry) => {
    if (!params.enable_imu_lpf) {
        last_ax_lpf = entry.ax;
        last_ay_lpf = entry.ay;
        last_gz_lpf = entry.gz;
        lpfInitialized = true;
        return { ax: entry.ax, ay: entry.ay, gz: entry.gz };
    }

    if (!lpfInitialized) {
        last_ax_lpf = entry.ax;
        last_ay_lpf = entry.ay;
        last_gz_lpf = entry.gz;
        lpfInitialized = true;
        return { ax: last_ax_lpf, ay: last_ay_lpf, gz: last_gz_lpf };
    }

    const cutoff = Math.max(0.01, params.imu_lpf_cutoff_hz || SIM_CONFIG.IMU.DEFAULT_LPF_CUTOFF_HZ);
    const dt = Number.isFinite(entry.dt) && entry.dt > 0 ? entry.dt : 0;
    const tau = 1 / (2 * Math.PI * cutoff);
    const alpha = dt > 0 ? dt / (tau + dt) : 1;
    last_ax_lpf += alpha * (entry.ax - last_ax_lpf);
    last_ay_lpf += alpha * (entry.ay - last_ay_lpf);
    last_gz_lpf += alpha * (entry.gz - last_gz_lpf);
    return { ax: last_ax_lpf, ay: last_ay_lpf, gz: last_gz_lpf };
};
```

### Xu ly Predict: IMU, ZUPT, velocity, yaw, spectrum series

```javascript
if (entry.type === 'Predict' && entry.dt > 0) {
    last_ax = entry.ax; last_ay = entry.ay; last_gz = entry.gz;
    const imuLpf = applyImuLpf(entry);

    const acc_mag = Math.sqrt((entry.ax - bias.ax)**2 + (entry.ay - bias.ay)**2);
    const gyr_mag = Math.abs(entry.gz - bias.gz);
    if (acc_mag < params.zupt_acc && gyr_mag < params.zupt_gyr) zupt_cnt++; else zupt_cnt = 0;
    zuptActive = zupt_cnt > SIM_CONFIG.IMU.ZUPT_COUNT_THRESHOLD;

    filter.predict({ ax: entry.ax, ay: entry.ay, gz: entry.gz }, entry.dt);
    filterLpf.predict(imuLpf, entry.dt);

    v_raw.x += (entry.ax - bias.ax) * entry.dt;
    v_raw.y += (entry.ay - bias.ay) * entry.dt;
    v_raw.x *= SIM_CONFIG.IMU.VELOCITY_DECAY;
    v_raw.y *= SIM_CONFIG.IMU.VELOCITY_DECAY;

    v_lpf.x += (imuLpf.ax - bias.ax) * entry.dt;
    v_lpf.y += (imuLpf.ay - bias.ay) * entry.dt;
    v_lpf.x *= SIM_CONFIG.IMU.VELOCITY_DECAY;
    v_lpf.y *= SIM_CONFIG.IMU.VELOCITY_DECAY;

    if (zuptActive) {
        v_clean.x = 0;
        v_clean.y = 0;
    } else {
        v_clean.x += (entry.ax - bias.ax) * entry.dt;
        v_clean.y += (entry.ay - bias.ay) * entry.dt;
        v_clean.x *= SIM_CONFIG.IMU.VELOCITY_DECAY;
        v_clean.y *= SIM_CONFIG.IMU.VELOCITY_DECAY;
    }

    yaw += (entry.gz - bias.gz) * entry.dt;

    imuSpectrumSeries.times.push(total_time);
    imuSpectrumSeries.ax.push(entry.ax - bias.ax);
    imuSpectrumSeries.ay.push(entry.ay - bias.ay);
    imuSpectrumSeries.ax_lpf.push(imuLpf.ax - bias.ax);
    imuSpectrumSeries.ay_lpf.push(imuLpf.ay - bias.ay);
}
```
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

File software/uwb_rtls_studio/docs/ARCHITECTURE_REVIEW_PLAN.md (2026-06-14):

# UWB RTLS Studio - Review flow, thread, state machine và data architecture

Tài liệu này review hiện trạng của `software/uwb_rtls_studio`, `software/common`
và `protocol/protos/protocol.proto` theo đúng câu hỏi:

- Flow View -> ViewModel -> Model -> Repository -> Data hiện tại đã đúng chưa.
- Thread/background worker hiện tại có đang dùng đúng cho API/command không.
- State machine đã gom về một nơi để nhiều file dùng chung chưa.
- Define biến/config đã gom về một nơi chưa.
- Bug ngầm/rủi ro kiến trúc cần xử lý trước khi app phát triển tiếp.
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

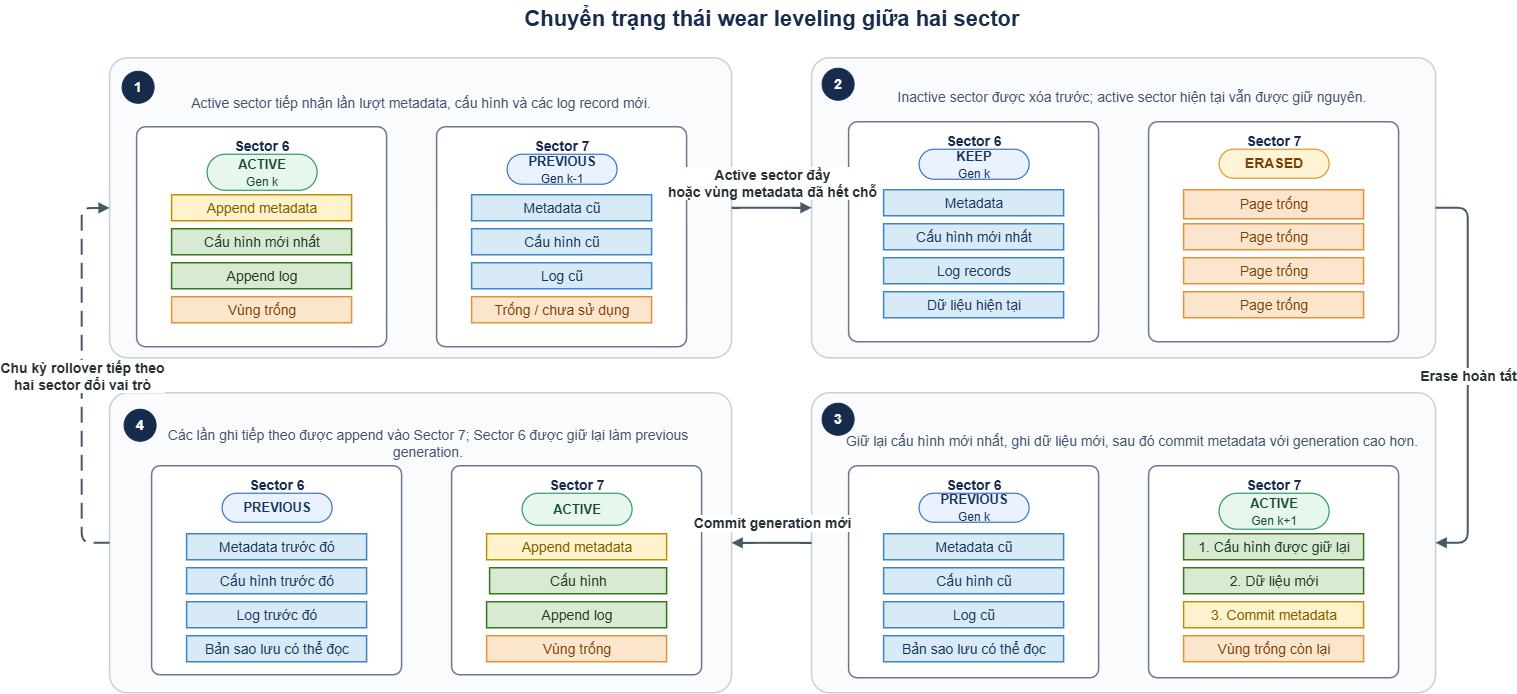
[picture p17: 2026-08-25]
docs/assets/images/thesis/chapter4/figure-4-6-dual-sector-storage.png

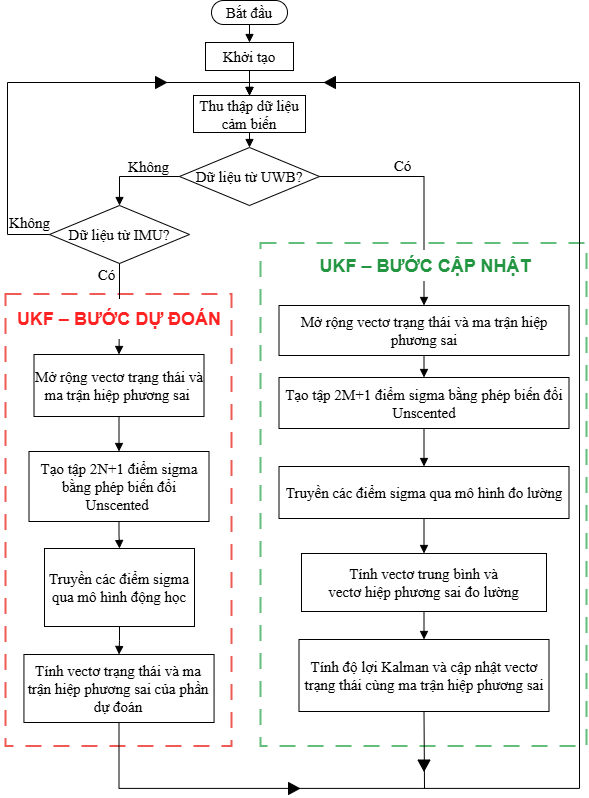
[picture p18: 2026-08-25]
docs/assets/diagrams/thesis/chapter4/figure-4-13-ukf-flow.png

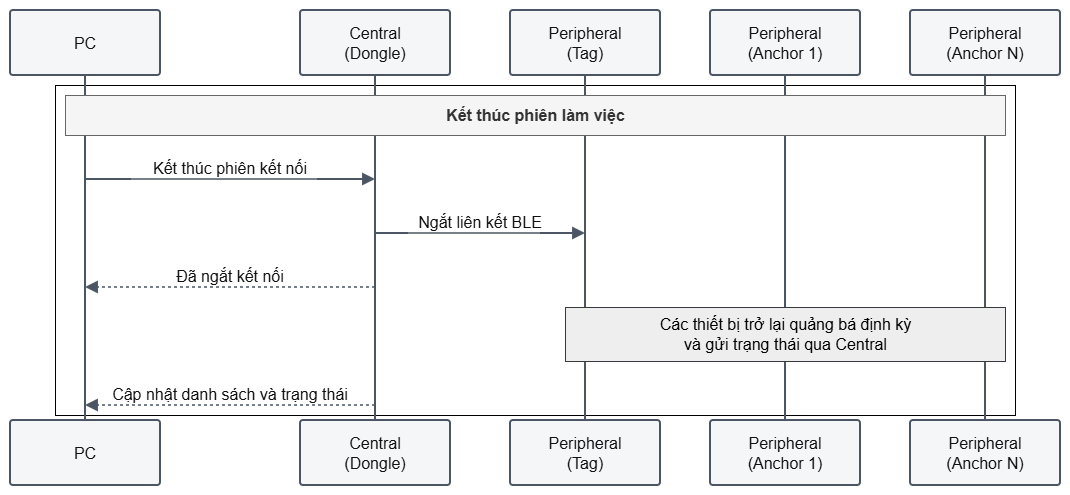
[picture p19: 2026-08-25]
docs/assets/images/thesis/chapter4/figure-4-20-ble-disconnect-flow.png

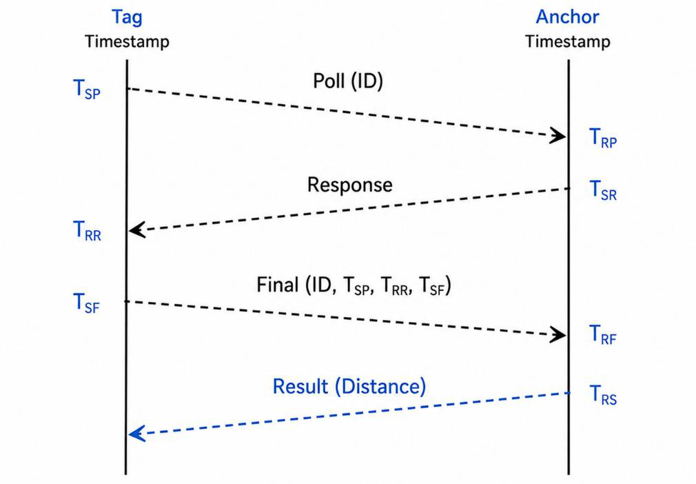
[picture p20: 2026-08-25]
docs/assets/diagrams/thesis/chapter4/figure-4-8-ds-twr-sequence.png

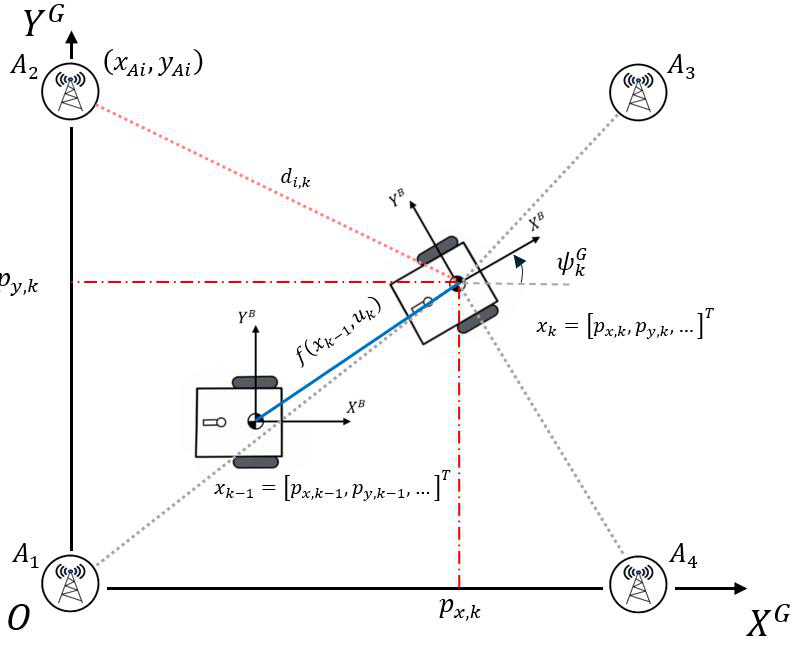
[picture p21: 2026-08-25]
docs/assets/images/thesis/chapter4/figure-4-12-system-mathematical-model.png

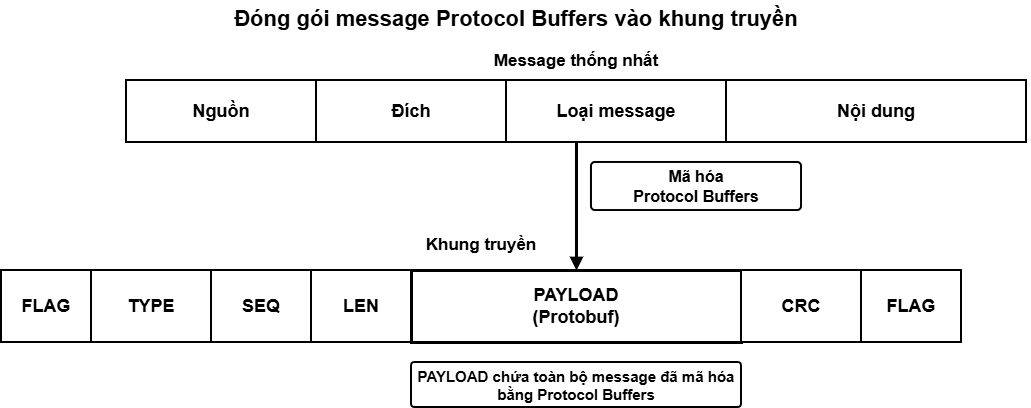
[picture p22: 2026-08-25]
docs/assets/diagrams/thesis/chapter4/figure-4-21-unified-frame-format.png

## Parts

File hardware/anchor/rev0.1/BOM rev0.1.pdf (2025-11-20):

Designators | Qty | Value | Package | Tol | Voltage
C1,C2,C3,C9,C13, C23,C26 | 15 | 10 µF | 805 | ±10–20% ≥20 V, X7R/X5R
C4,C8,C14,C15,C 16,C17,C19,C20, C22,C24,C25 | 25 | 0.1 µF | 603 | ±10% ≥10 V, X7R
C5,C21 | 5 | 1 µF | 805 | ±10% ≥10 V, X7R
C6,C7 | 5 | 4.7 µF | 805 | ±10–20% ≥10 V, X7R
C10,C11 | 8 | 22 µF | 805 | ±20% ≥20 V, X7R
C18 | 5 | 2.2 µF | 805 | ±10% ≥10 V, X7R
CY1,CY2 | 5 | 12 pF | 603 | ±5% ≥50 V, C0G/NP0
Designators | Qty | Value | Package | Tol | Power
R1,R4,R9,R14,R16 ,R17,R18,R24,R15, R19,R20 | 25 | 10 kΩ | 603 | ±1% 1/10 W
R2 | 5 | 3.1kΩ | 603 | ±1% 1/10 W
R5 | 5 | 3.56 kΩ | 603 | ±1% 1/10 W
R7,R8 | 5 | 5.1 kΩ | 603 | ±1% 1/10 W
R10,R11 | 5 | 6 kΩ | 603 | ±1% 1/10 W
R12 | 5 | 470 kΩ | 805 | ±1% 1/8 W
R13 | 5 | 150 kΩ | 805 | ±1% 1/8 W
R21,22,23 | 8 | 2.2 kΩ | 603 | ±1% 1/10 W
| 5 | 1.50 kΩ | 603 | ±1% 1/10 W
| 5 | 1.8kΩ | 603 | ±1% 1/10 W
Designators | Qty | Part / Value | Package | Note
D1 | 3 | ESD9B5.0 ST5G | SOD-923

# DIODE

# Capacitors

# Resistors

| 3 | ESD9X5.0 ST5G | SOD-923
D2,D4,D6 | 8 | LED Yellow | 603
D3,D5 | 5 | LED Red | 603

Designators | Qty | Part | Package | Note
U1 | 2 | BQ24075RGT | VQFN-16 3×3 mm
U2 | 2 | TPS63070RNMR | VQFN
U3 | 2 | USBLC6-2SC6 | SOT-23-6
U4 | 2 | STM32F411CEU6 | UFQFPN-48
U5 | 2 | MDBT42Q-512K | Module
DWM1 | 2 | DWM1000 | Module
Y1 | 3 | NX3225SA-24 MHz 8pF | 3.2×2.5-4pin
Designators | Qty | Part / Value | Package | Note
L1 | 3 | 1.5 µH | 1008 (2520) | I_sat ≥1.5 A, DCR thấp
FB1 | 3 | Ferrite bead | 603 | 600Ω at 100 MHz, I ≥ 0.5 A
Designators | Qty | Part | Package | Note
J2 | 3 | USB-C 16P HRO TYPE-C-31-M-12 | Receptacle | Link (https://linhkien.cxtvn.com/3738-cong-type-c-cai-16p-chat-luong-cao.html)
J1 | 3 | BM02B-SRSS-TB | JST-SH 2-pin
J3 | 3 | BM04B-SRSS-TB | JST-SH 4-pin
J4 | 3 | BM05B-SRSS-TB | JST-SH 5-pin
SW1 | 3 | DIP-3, 1.27 mm | SMD
SW2 | 5 | SW Tact 2P 3x4mm | SMD | Link (https://linhkien.cxtvn.com/6582-nut-nhan-smd-2p.html)
SW3 | 3 | SPDT PCM12 | SMD | Link (https://linhkien.cxtvn.com/1781-msk-12c02-cong-tac-gat-smd-7p.html)
F1 | 3 | Polyfuse 0.5A | 1206

# Connectors & Switches

# Magnetics / Bead

# IC & Modules

# Other

Designators | Qty | Part | Package | Note
| 1 | Pin Li-Polymer 3.7V 1000mAh | 503450 Link (https://linhkien.cxtvn.com/10690-pin-li-polymer-503450-37v-1000mah-50x34x50mm-co-mach-bao-ve.html)

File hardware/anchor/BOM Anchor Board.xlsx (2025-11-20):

Capacitors |  |  |  |  |  | IC & Modules
Designators | Qty | Value | Package | Tol | Voltage | Designators | Qty | Part | Package | Note
C1,C2,C3,C9,C13,C23,C26 | 15 | 10 µF | 805 | ±10–20% | ≥20 V, X7R/X5R | U1 | 2 | BQ24075RGT | VQFN-16 3×3 mm
C4,C8,C14,C15,C16,C17,C19,C20,C22,C24,C25 | 25 | 0.1 µF | 603 | ±10% | ≥10 V, X7R | U2 | 3 | TPS63070RNMR | VQFN
C5,C21 | 5 | 1 µF | 805 | ±10% | ≥10 V, X7R | U3 | 2 | USBLC6-2SC6 | SOT-23-6
C6,C7 | 5 | 4.7 µF | 805 | ±10–20% | ≥10 V, X7R | U4 | 3 | STM32F411CEU6 | UFQFPN-48
C10,C11 | 8 | 22 µF | 805 | ±20% | ≥20 V, X7R | U5 | 3 | MDBT42Q-512K | Module |  | replace with
C18 | 5 | 2.2 µF | 805 | ±10% | ≥10 V, X7R | DWM1 | 2 | DWM1000 | Module
CY1,CY2 | 5 | 12 pF | 603 | ±5% | ≥50 V, C0G/NP0 | Y1 | 3 | NX3225SA-24 MHz 8pF | 3.2×2.5-4pin
Resistors |  |  |  |  |  | Magnetics / Bead
Designators | Qty | Value | Package | Tol | Power | Designators | Qty | Part / Value | Package | Note
R1,R4,R9,R14,R16,R17,R18,R24,R15,R19,R20 | 25 | 10 kΩ | 603 | ±1% | 1/10 W | L1 | 5 | 1.5 µH | 1008 (2520) | I_sat ≥1.5 A, DCR thấp
R2 | 5 | 3.1kΩ | 603 | ±1% | 1/10 W | FB1 | 3 | Ferrite bead | 603 | 600Ω at 100 MHz, I ≥ 0.5 A
R5 | 5 | 3.56 kΩ | 603 | ±1% | 1/10 W | Connectors & Switches
R7,R8 | 5 | 5.1 kΩ | 603 | ±1% | 1/10 W | Designators | Qty | Part | Package | Note
R10,R11 | 5 | 6 kΩ | 603 | ±1% | 1/10 W | J2 | 3 | USB-C 16P HRO TYPE-C-31-M-12 | Receptacle
R12 | 5 | 470 kΩ | 805 | ±1% | 1/8 W | J1 | 5 | BM02B-SRSS-TB | JST-SH 2-pin
R13 | 5 | 150 kΩ | 805 | ±1% | 1/8 W | J3 | 5 | BM04B-SRSS-TB | JST-SH 4-pin
R21,22,23 | 8 | 2.2 kΩ | 603 | ±1% | 1/10 W | J4 | 5 | BM05B-SRSS-TB | JST-SH 5-pin
 | 5 | 1.50 kΩ | 603 | ±1% | 1/10 W | SW1 | 5 | DIP-3, 1.27 mm | SMD
 | 5 | 1.8kΩ | 603 | ±1% | 1/10 W | SW2 | 5 | SW Tact 2P 3x4mm | SMD
DIODE |  |  |  |  |  | SW3 | 3 | SPDT PCM12 | SMD
Designators | Qty | Part / Value | Package | Note |  | F1 | 3 | Polyfuse 0.5A | 1206
D1 | 3 | ESD9B5.0ST5G | SOD-923 |  |  | Other
 | 3 | ESD9X5.0ST5G | SOD-923 |  |  | Designators | Qty | Part | Package | Note
D2,D4,D6 | 8 | LED Yellow | 603
D3,D5 | 5 | LED Red | 603

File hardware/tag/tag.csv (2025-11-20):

Reference | Qty | Value | DNP | Exclude from BOM | Exclude from Board | Footprint | Datasheet
C1,C2,C3,C4,C14 | 5 | 100n |  |  |  | Capacitor_SMD:C_0805_2012Metric_Pad1.18x1.45mm_HandSolder | ~
C5 | 1 | 10u |  |  |  | Capacitor_SMD:C_0805_2012Metric_Pad1.18x1.45mm_HandSolder | ~
C6,C7,C17 | 3 | 1u |  |  |  |  | ~
C8 | 1 | 10n |  |  |  |  | ~
C12 | 1 | 2.2u |  |  |  |  | ~
C15,C23 | 2 | 100n |  |  |  |  | ~
C16,C18 | 2 | 4.7u |  |  |  |  | ~
C19,C20,C21,C22 | 4 | 10u |  |  |  |  | ~
C24,C25,C26 | 3 | 22u |  |  |  |  | ~
CY1,CY2 | 2 | 10p |  |  |  | Capacitor_SMD:C_0805_2012Metric_Pad1.18x1.45mm_HandSolder | ~
CY3,CY4 | 2 | 22p |  |  |  | Capacitor_SMD:C_0805_2012Metric_Pad1.18x1.45mm_HandSolder | ~
D1 | 1 | ESD9B5.0ST5G |  |  |  | Diode_SMD:D_SOD-923 | https://www.onsemi.com/pub/Collateral/ESD9B-D.PDF
D3,D4,D5,D6,D7,D8 | 6 | LED |  |  |  |  | ~
D9 | 1 | R |  |  |  |  | ~
DWM1 | 1 | DWM1000 |  |  |  | RF_Module:DWM1000 | https://www.decawave.com/sites/default/files/resources/dwm1000-datasheet-v1.3.pdf
F1 | 1 | Polyfuse |  |  |  |  | ~
FB1 | 1 | FerriteBead |  |  |  |  | ~
J1 | 1 | USB_C_Receptacle_USB2.0_16P |  |  |  |  | https://www.usb.org/sites/default/files/documents/usb_type-c.zip
J2 | 1 | Conn_01x04_Pin |  |  |  | Connector_PinHeader_2.54mm:PinHeader_1x04_P2.54mm_Vertical | ~
J3 | 1 | BATTERY |  |  |  | B2B-PH-SM4-TB:JST_B2B-PH-SM4-TB
L2 | 1 | 1.5u |  |  |  |  | ~
R3,R4 | 2 | 10K |  |  |  |  | ~
R5,R6 | 2 | 4.7k |  |  |  |  | ~
R7,R12,R13,R14 | 4 | 100k |  |  |  |  | ~
R8,R9,R10,R11,R15,R16,R22,R23,R26 | 9 | 10k |  |  |  |  | ~
R17,R18 | 2 | 5k1 |  |  |  |  | ~
R19 | 1 | 1.13k |  |  |  |  | ~
R20 | 1 | 1.18k |  |  |  |  | ~
R21 | 1 | 1.5k |  |  |  |  | ~
R24 | 1 | 470k |  |  |  |  | ~
R25 | 1 | 150k |  |  |  |  | ~
SW1 | 1 | SW_SPDT |  |  |  |  | ~
SW2 | 1 | SW_Push |  |  |  |  | ~
U1 | 1 | STM32F411CEUx |  |  |  | Package_DFN_QFN:QFN-48-1EP_7x7mm_P0.5mm_EP5.6x5.6mm | https://www.st.com/resource/en/datasheet/stm32f411ce.pdf
U2 | 1 | ICM-42688-P |  |  |  | ICM-42688-P:PQFN50P300X250X97-14N
U4 | 1 | BQ24075RGT |  |  |  | Package_DFN_QFN:VQFN-16-1EP_3x3mm_P0.5mm_EP1.6x1.6mm | http://www.ti.com/lit/ds/symlink/bq24075.pdf
U5 | 1 | TPS63070RNMR |  |  |  | TPS63070RNMR:VREG_TPS63070RNMR
Y2 | 1 | NX3215SA-32.768kHz |  |  |  | Crystal:Crystal_SMD_HC49-SD_HandSoldering | ~
Y3 | 1 | NX3225SA-24MHz |  |  |  | Crystal:Crystal_SMD_3225-4Pin_3.2x2.5mm_HandSoldering | ~

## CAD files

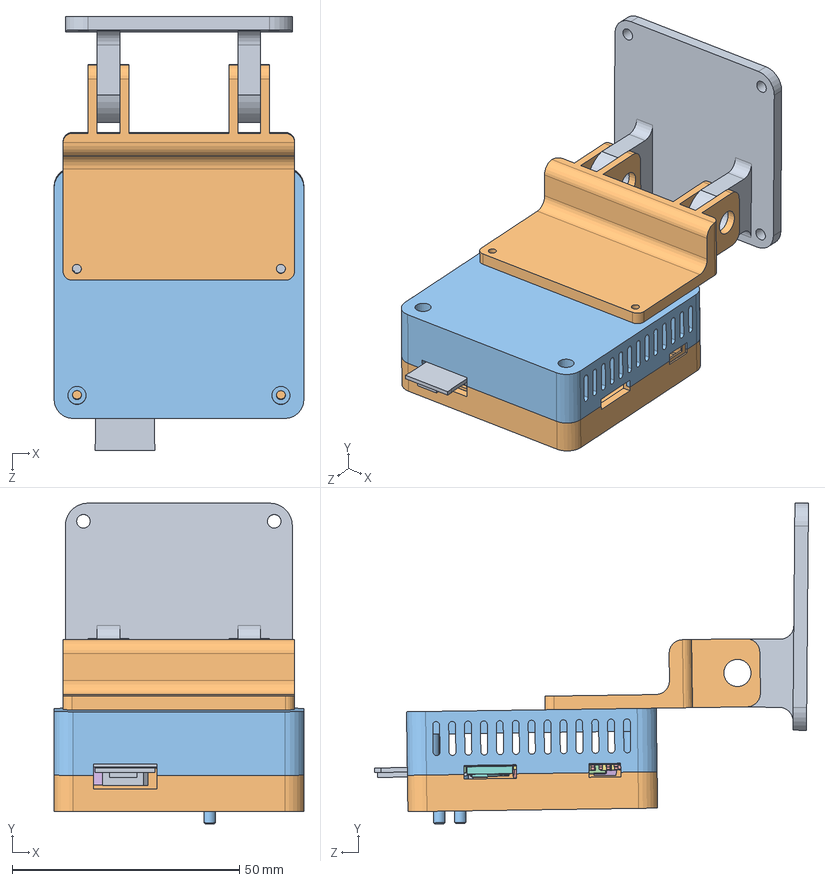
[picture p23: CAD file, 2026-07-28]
hardware/pad/Assem1.SLDASM
55.0 x 70.6 x 95.6 mm
pad_component_1
bottom_anchor
Pads12-15.step
Body.step
Pads5-8.step
Pads1-4.step
Pad9.step
Pad11.step
Pad10.step
Pin_Index.step
tag 1.62.1.step
SM02B-SRSS-TB-LF--SN---3DModel-STEP-56544.step
R_0603_1608Metric.step x 28
C_0805_2012Metric.step x 13
C_0603_1608Metric.step x 15
SOT-23.step x 2
L_0603_1608Metric.step
U.FL_Hirose_U.FL-R-SMT-1_Vertical.step
BM05B-SRSS-TB_LF__SN_.step
LED_0603_1608Metric.step x 6
JST_SH_BM06B-SRSS-TB_1x06-1MP_P1.00mm_Vertical.step
C_0402_1005Metric.step x 2
D_SOD-123.step
DWM1000.step
MAX17048G_T10.step
Crystal_SMD_3225-4Pin_3.2x2.5mm.step
3x4x2 tact button.step x 2
USB_C_Receptacle_GCT_USB4105-xx-A_16P_TopMnt_Horizontal.step
SW_DIP_SPSTx03_Slide_KingTek_DSHP03TJ_W5.25mm_P1.27mm_JPin.step
QFN-48-1EP_7x7mm_P0.5mm_EP5.15x5.15mm.step
FSC-BT603.step
D_SOD-323.step
SM04B-SRSS-TB_LF__SN_.step
WQFN-16-1EP_3x3mm_P0.5mm_EP1.6x1.6mm.step
SKRTLAE010--3DModel-STEP-56544.step
R_0805_2012Metric.step x 2
L_0402_1005Metric.step
Fuse_1206_3216Metric.step
SOT-23-6.step
anchor_PCB.step
top_anchor
button_user&reset x 2

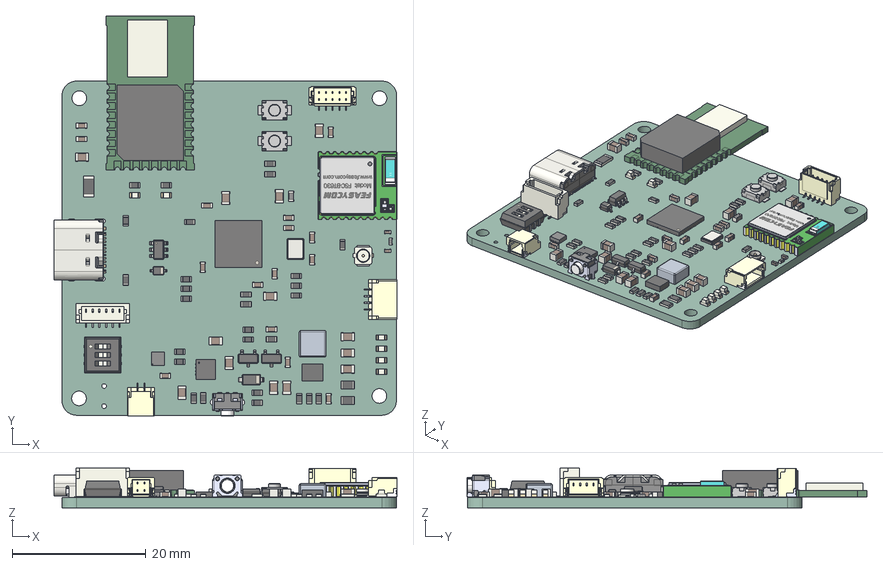
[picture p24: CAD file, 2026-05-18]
hardware/anchor/anchor.step
51.3 x 59.8 x 5.92 mm
SM02B-SRSS-TB-LF--SN---3DModel-STEP-56544
R_0603_1608Metric x 28
C_0805_2012Metric x 13
C_0603_1608Metric x 15
SOT-23 x 2
L_0603_1608Metric
U.FL_Hirose_U.FL-R-SMT-1_Vertical
BM05B-SRSS-TB_LF__SN_
LED_0603_1608Metric x 6
JST_SH_BM06B-SRSS-TB_1x06-1MP_P1.00mm_Vertical
C_0402_1005Metric x 2
D_SOD-123
DWM1000
MAX17048G_T10
Crystal_SMD_3225-4Pin_3.2x2.5mm
3x4x2 tact button x 2
USB_C_Receptacle_GCT_USB4105-xx-A_16P_TopMnt_Horizontal
SW_DIP_SPSTx03_Slide_KingTek_DSHP03TJ_W5.25mm_P1.27mm_JPin
QFN-48-1EP_7x7mm_P0.5mm_EP5.15x5.15mm
FSC-BT603
D_SOD-323
SM04B-SRSS-TB_LF__SN_
WQFN-16-1EP_3x3mm_P0.5mm_EP1.6x1.6mm
SKRTLAE010--3DModel-STEP-56544
R_0805_2012Metric x 2
L_0402_1005Metric
Fuse_1206_3216Metric
SOT-23-6
Pads12-15
Pads5-8
Pads1-4
Pin_Index
anchor 1.92.1
anchor_PCB

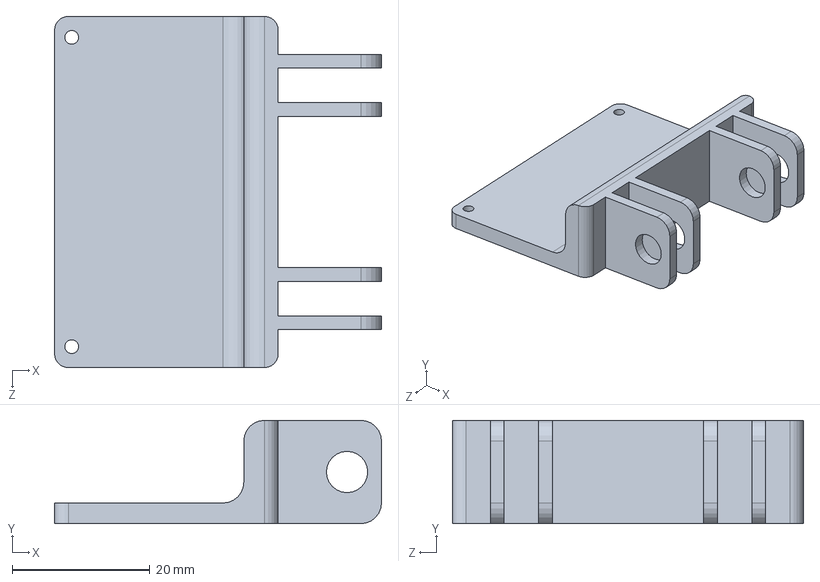
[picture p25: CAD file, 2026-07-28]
hardware/pad/Part3.SLDPRT
47.5 x 15.0 x 51.0 mm

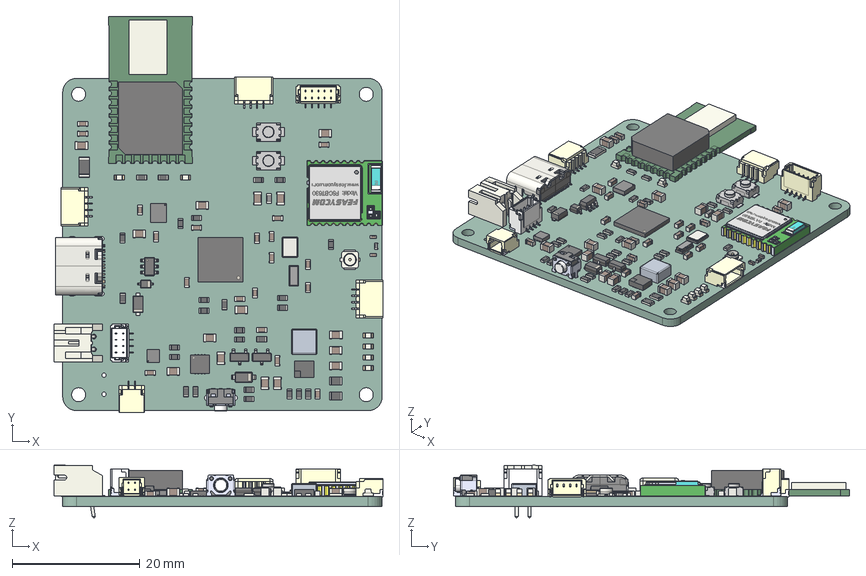
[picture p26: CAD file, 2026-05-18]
hardware/tag/tag.step
51.5 x 62.0 x 8.25 mm
R_0603_1608Metric x 26
R_0805_2012Metric x 2
SKRTLAE010--3DModel-STEP-56544
C_0603_1608Metric x 19
C_0805_2012Metric x 15
SOT-23-6
SOT-23 x 2
BM05B-SRSS-TB_LF__SN_
JST_PH_S2B-PH-K_1x02_P2.00mm_Horizontal
U.FL_Hirose_U.FL-R-SMT-1_Vertical
LED_0603_1608Metric x 6
C_0402_1005Metric x 2
SM04B-SRSS-TB_LF__SN_ x 3
ICM-45686
DWM1000
USB_C_Receptacle_GCT_USB4105-xx-A_16P_TopMnt_Horizontal
L_0603_1608Metric
3x4x2 tact button x 2
Pads12-15
Pads5-8
Pads1-4
Pin_Index
SM02B-SRSS-TB-LF--SN---3DModel-STEP-56544
Fuse_1206_3216Metric
Crystal_SMD_3215-2Pin_3.2x1.5mm
tag 1.62.1
D_SOD-123
WQFN-16-1EP_3x3mm_P0.5mm_EP1.6x1.6mm
D_SOD-323
FSC-BT603
MAX17048G_T10
L_0402_1005Metric
QFN-48-1EP_7x7mm_P0.5mm_EP5.15x5.15mm
Crystal_SMD_3225-4Pin_3.2x2.5mm
BMxxB-SRSS-TB(LF)(SN)_04
D_SOD-123F
tag_PCB

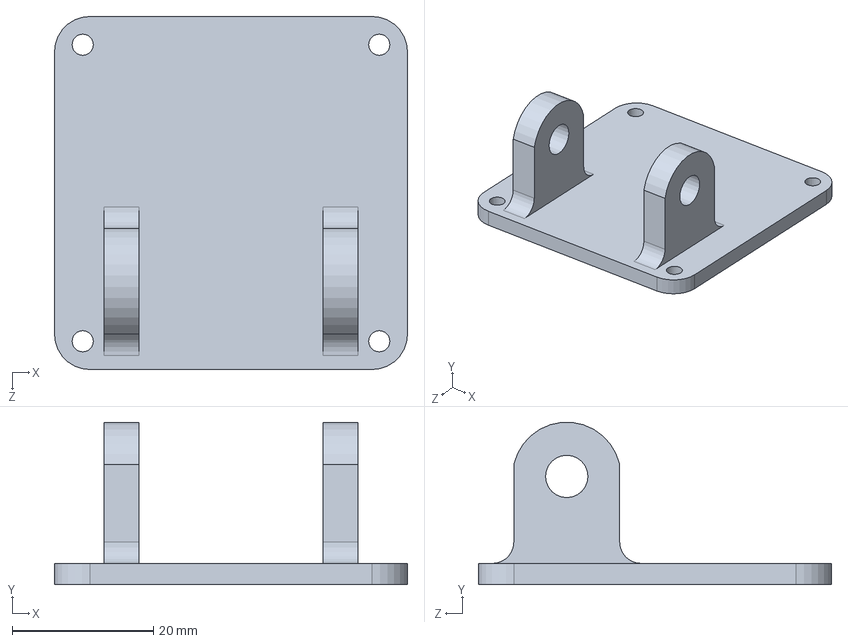
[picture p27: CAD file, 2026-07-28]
hardware/pad/pad_component_1.SLDPRT
50.0 x 23.0 x 50.0 mm

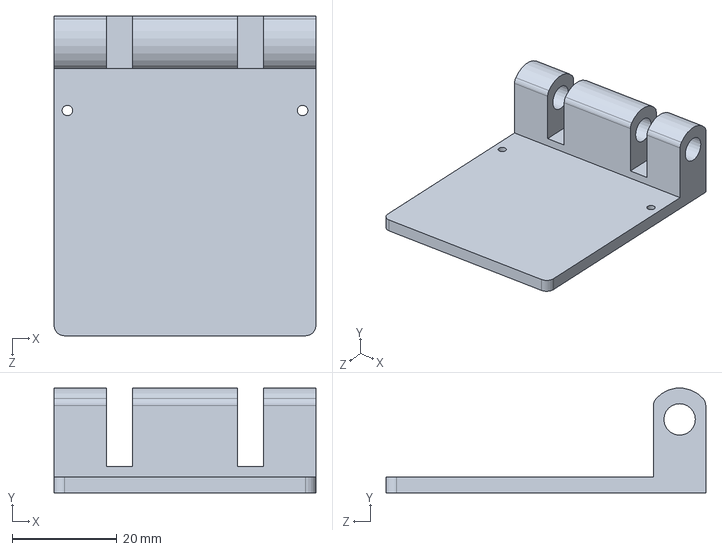
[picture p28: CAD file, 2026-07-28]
hardware/pad/pad_component_2.SLDPRT
50.0 x 20.0 x 61.0 mm

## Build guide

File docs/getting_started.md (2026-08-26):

# Getting Started & Environment Setup Guide

[Documentation Home](README.md) · [Firmware Architecture](firmware/architecture.md) · [Deployment Guide](deployment.md)

This guide provides step-by-step instructions for configuring build toolchains, compiling firmware binaries, and launching desktop software for the **UWB-RTLS** repository.

---

## Table of Contents

1. [Environment & Version Matrix](#1-environment--version-matrix)
2. [Setup Flow](#2-setup-flow)
3. [Step-by-Step Setup Guide](#3-step-by-step-setup-guide)
   - [3.1. Clone Repository & Submodules](#31-clone-repository--submodules)
   - [3.2. Generate Protocol Buffers Code](#32-generate-protocol-buffers-code)
   - [3.3. Toolchain Setup & STM32 Firmware Build](#33-toolchain-setup--stm32-firmware-build)
   - [3.4. Build Nordic BLE Firmware](#34-build-nordic-ble-firmware)
   - [3.5. Setup Python Virtual Environment & Run RTLS Studio](#35-setup-python-virtual-environment--run-rtls-studio)
4. [Troubleshooting](#4-troubleshooting)

---

## 1. Environment & Version Matrix

| Ecosystem Layer | Tool / Component | Verified Version | Purpose |
| --- | --- | --- | --- |
| **IDE / Toolchain** | STM32CubeIDE | `v1.19.0` (or `v1.10+`) | Core IDE & bundled compiler plugins |
| **Arm Compiler** | `arm-none-eabi-gcc` | `v10.3.1` / `v13.3.rel1` | STM32F411 Cortex-M4F compiler |
| **Build Utility** | GNU Make | `v4.4.1` (ST Plugin) | Firmware & Protobuf build automation |
| **Wireless SDK** | Nordic nRF5 SDK | `v17.1.0` | BLE central/peripheral firmware |
| **Host Runtime** | Python | `v3.10+` (v3.12 verified) | Desktop GUI & Protocol generator |

---

## 2. Setup Flow

```mermaid
flowchart TD
    S1["1. Clone Repository & Submodules (git clone --recursive)"] --> S2["2. Generate Protocol Buffers (make -C protocol)"]
    S2 --> S3["3. Build STM32 Firmware (make -C firmware/uwb)"]
    S3 --> S4["4. Launch RTLS Studio (python main.py)"]
```

---

## 3. Step-by-Step Setup Guide

### 3.1. Clone Repository & Submodules

Clone the repository with recursive submodules (for `protocol/nanopb` embedded C compiler):

```bash
git clone --recursive https://github.com/phuongmt08/uwb-rtls.git
cd uwb-rtls
```

> **Note:** If you already cloned without `--recursive`, run `git submodule update --init --recursive` to fetch missing submodules.

### 3.2. Generate Protocol Buffers Code

Generate binary serialization bindings for embedded C and Python desktop software:

```powershell
make -C protocol
```

- **C Firmware Headers**: `protocol/protos/*.pb.c` and `*.pb.h`
- **Python Host Module**: `software/common/protocol_pb2.py`

### 3.3. Toolchain Setup & STM32 Firmware Build

> **Note:** Both `arm-none-eabi-gcc.exe` and `make.exe` are bundled inside your **STM32CubeIDE** installation plugins. No standalone downloads are required.

#### Option A: Build via Command Line (PowerShell)

Set your PowerShell session paths to point to STM32CubeIDE plugins:

```powershell
# 1. Set GCC_PATH to STM32CubeIDE GNU Tools plugin
$env:GCC_PATH = "C:\ST\STM32CubeIDE_1.19.0\STM32CubeIDE\plugins\com.st.stm32cube.ide.mcu.externaltools.gnu-tools-for-stm32.13.3.rel1.win32_1.0.0.202411081344\tools\bin"

# 2. Add GCC and Make plugins to session PATH
$env:PATH = "$env:GCC_PATH;C:\ST\STM32CubeIDE_1.19.0\STM32CubeIDE\plugins\com.st.stm32cube.ide.mcu.externaltools.make.win32_2.2.0.202409170845\tools\bin;" + $env:PATH

# 3. Build firmware
make -C firmware/uwb -j8
```

*Build Artifacts (`firmware/uwb/build/`):* `uwb-rtls.elf`, `uwb-rtls.hex`, `uwb-rtls.bin`

#### Option B: Build inside STM32CubeIDE GUI

1. Open **STM32CubeIDE**.
2. **File $\rightarrow$ Open Projects from File System...** $\rightarrow$ Select `firmware/uwb`.
3. Press **Ctrl + B** to build.

### 3.4. Build Nordic BLE Firmware

1. Download [Nordic nRF5 SDK v17.1.0](https://www.nordicsemi.com/Products/Development-software/nRF5-SDK).
2. Set `SDK_ROOT` and compile:

```powershell
$env:SDK_ROOT = "C:\nRF5_SDK_17.1.0_ddde5a0"
make -C firmware/ble_firmware/central/armgcc
make -C firmware/ble_firmware/peripheral/armgcc
```

### 3.5. Setup Python Virtual Environment & Run RTLS Studio

Create Python virtual environment, install dependencies, and launch the GUI:

```powershell
cd software/uwb_rtls_studio

# Create & activate venv
python -m venv venv
.\venv\Scripts\Activate.ps1

# Install requirements & launch
pip install -r requirements.txt
python main.py
```

---

## 4. Troubleshooting

| Error Message / Symptom | Root Cause | Solution |
| --- | --- | --- |
| **`GCC_PATH is not set`** | Missing environment variable. | Set `$env:GCC_PATH` to point to the `bin/` directory inside STM32CubeIDE plugins. |
| **`make: command not found`** | Make tool is not in session `PATH`. | Add STM32CubeIDE Make plugin directory to `$env:PATH`. |
| **`nanopb_generator.py missing`** | Submodule was not initialized. | Run `git submodule update --init --recursive`. |
| **`No module named protocol_pb2`** | Protobuf bindings not compiled. | Run `make -C protocol` before starting RTLS Studio. |

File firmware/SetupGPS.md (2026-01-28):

#SETUP GPS
## Đo Đạc
Đo khoảng cách từ mạch Tag tới Ground
Đo khoảng cách từ mạch Anchor tới Ground
Đo khoảng cách từ anchor 1 2 3 với hệ trục tọa độ đặt sẵn

## Setup firmware

Mở file positioning_config theo đường dẫn UWB-RTLS/firmware/uwb/sys/positioning_config.h
Nhập khoảng cách đo đạc 
/**
* @brief Tag height from ground (meters)
*/
#define TAG_HEIGHT_M            (0.148f)

/**
* @brief Anchor height from ground (meters)
*/
#define ANCHOR_HEIGHT_M         (0.415f)

Nhập vị trí anchor so với hệ trục tọa độ, Tag cần biết tọa độ của các anchor để tính Trilateration đúng
Nếu như thấy Error cao, cần check lại vị trí của các anchor

Nhập số lương của các anchor setup, lưu ý nếu như nhập sai thì tọa độ sẽ không được tính

#define NUM_ANCHORS  3  /* Total anchors */

#define ANCHOR_1_X   0.0f
#define ANCHOR_1_Y   0.0f

#define ANCHOR_2_X   9.76f
#define ANCHOR_2_Y   0.0f

#define ANCHOR_3_X   4.88f
#define ANCHOR_3_Y   14.64f

#define ANCHOR_4_X   0.0f
#define ANCHOR_4_Y   0.0f

Một số lưu ý sau

Nếu như thấy tỉ lệ mất gói cao ->

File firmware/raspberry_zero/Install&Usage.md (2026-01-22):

"""
Installation on Raspberry Pi Zero:

1. Install dependencies:
   sudo apt update
   sudo apt install python3-serial python3-pip
   pip3 install pyserial

2. Enable UART on Raspberry Pi:
   - Edit /boot/config.txt:
     enable_uart=1
     dtoverlay=disable-bt
   - Reboot: sudo reboot

3. Check UART device:
   ls -l /dev/serial*
   # Should see /dev/serial0 -> ttyAMA0

4. Run the gateway:
   python3 main.py --host 192.168.1.100 --port 5000

5. Run with custom settings:
   python3 main.py --uart /dev/ttyUSB0 --host 10.0.0.50 --port 6000 --log-level DEBUG

6. Run as service (systemd):
   Create /etc/systemd/system/uwb-gateway.service:
   
   [Unit]
   Description=UWB Position Gateway
   After=network.target

   [Service]
   Type=simple
   User=pi
   WorkingDirectory=/home/pi/uwb_gateway
   ExecStart=/usr/bin/python3 /home/pi/uwb_gateway/main.py --host 192.168.1.100
   Restart=always

   [Install]
   WantedBy=multi-user.target
   
   Enable and start:
   sudo systemctl enable uwb-gateway
   sudo systemctl start uwb-gateway
   sudo systemctl status uwb-gateway

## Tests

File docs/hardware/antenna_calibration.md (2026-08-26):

# Antenna Delay Calibration Guide

[Documentation Home](../README.md) · [Hardware Specs](schematics_and_specs.md) · [Deployment Guide](../deployment.md) · [RTLS Studio Guide](../software/rtls_studio_and_tools.md)

This guide explains the physical principles, mathematics, and step-by-step automated workflow for calibrating Ultra-Wideband (UWB) antenna delays in **UWB-RTLS**.

---

## Table of Contents

1. [Why Antenna Delay Calibration Matters](#1-why-antenna-delay-calibration-matters)
2. [The Golden Tag Calibration Principle](#2-the-golden-tag-calibration-principle)
3. [Calibration Mathematics & Damped Iteration](#3-calibration-mathematics--damped-iteration)
4. [Step-by-Step Calibration via RTLS Studio](#4-step-by-step-calibration-via-rtls-studio)
5. [Reference Values & Residual Error](#5-reference-values--residual-error)

---

## 1. Why Antenna Delay Calibration Matters

In Decawave DW1000 transceivers, timestamps are generated inside the digital baseband core. The time required for an RF pulse to travel from the digital core through the internal analog transceiver stage, PCB trace, and antenna into the air is the **Antenna Delay**:

```
[ Digital Baseband Timestamp Core ]
                │
                ▼  (Internal Analog & Driver Delay)
[ DW1000 RF Front-End Pin ]
                │
                ▼  (PCB Trace Delay: ~6.5 ps/mm)
[ Antenna & Matching Network ]
                │
                ▼  (Air Velocity: c ≈ 299,792,458 m/s)
[ Free Space RF Wavefront ]
```

- $1\text{ DW1000 unit} \approx 15.65\text{ ps}$, corresponding to $\approx 4.69\text{ mm}$ of flight distance.
- Uncalibrated nodes introduce systematic ranging errors of $+15 \dots 35\text{ cm}$, which degrade positioning accuracy if left uncompensated.

---

## 2. The Golden Tag Calibration Principle

To calibrate a multi-Anchor network cleanly without mutual dependency loops, UWB-RTLS uses the **Golden Tag** methodology:

```
[ Golden Reference Tag ] <════ Known Distance: d_known (e.g. 5.00 m) ════> [ Target Anchor ]
(Factory Default: 16187)                                                   (Auto-Tuned & Saved to Flash)
```

1. **Reference Tag**: One Tag is designated as the reference unit with default factory delays (`TX_DLY = 16187`, `RX_DLY = 16187`).
2. **Anchor Compensation**: 100% of the systematic distance bias is assigned to the target Anchor.
3. **Automated OTA Updates**: RTLS Studio automatically tunes the Anchor over-the-air via `antenna_delay_bcast_set` without requiring physical debugger connections.

---

## 3. Calibration Mathematics & Damped Iteration

The calibration engine runs on the host PC (RTLS Studio) as a closed-loop iterative optimizer:

```mermaid
flowchart TD
    S1["1. Collect 30 TDMA Range Samples<br/>Compute Mean Measured Distance d_mean"] --> S2["2. Compute Error<br/>e = d_mean - d_known"]
    S2 --> S3{"3. Convergence Check<br/>|e| <= 0.05 m ?"}
    S3 -->|No| S4["4. Apply Damped Step<br/>Delta_DLY = 0.5 * e * 426.4 units/m<br/>Send OTA Delay Update"]
    S4 --> S5["5. Settle 2.0s<br/>Discard Transients"]
    S5 --> S1
    S3 -->|Yes| S6["6. Commit to Flash<br/>Send persist=True to Anchor"]
```

### 3.1. Mathematical Formulations

- **Distance Error**:
  $$e = \bar{d}_{\text{measured}} - d_{\text{known}}$$

- **Damped Delay Correction**:
  $$\Delta \text{Delay} = \alpha \times e \times K_{\text{DW}}$$
  - Damping factor: $\alpha = 0.5$ (prevents oscillation).
  - Scale factor: $K_{\text{DW}} = \frac{1}{0.002345} \approx 426.4\text{ DW units/meter}$ of combined round-trip delay.

- **Convergence Criteria**:
  $$|e| \le 0.05\text{ m } (5\text{ cm}) \quad \text{or} \quad |\Delta \text{Delay}| \le 5\text{ DW units}$$

---

## 4. Step-by-Step Calibration via RTLS Studio

```mermaid
flowchart TD
    A["1. Setup Baseline (Tag-to-Anchor d_known)"] --> B["2. Open RTLS Studio & Switch to Developer Mode"]
    B --> C["3. Tab 4: Calibration -> Enter d_known"]
    C --> D["4. Click Start -> Auto-Iterates & Saves to Flash"]
```

1. **Physical Setup**:
   - Mount the Golden Tag on a tripod at a surveyed distance from the Anchor (e.g., $d_{\text{known}} = 5.00\text{ m}$ measured with a laser meter).
   - Ensure clear line-of-sight with $>20\text{ cm}$ clearance from metal obstacles.

2. **Open RTLS Studio Calibration Tab**:
   - In the top-right header, toggle from **User Mode** to **Developer Mode**.
   - Navigate to **Tab 4: Calibration**.

3. **Run Automated Calibration**:
   - Select the target **Anchor ID** (or select **Parallel Mode** to calibrate all Anchors simultaneously).
   - Enter the known baseline distance ($d_{\text{known}}$).
   - Click **Start Calibration**.
   - The application automatically samples ranges, executes the iterative loop, and displays real-time convergence progress.

4. **Verify & Commit**:
   - Upon convergence, RTLS Studio sends a broadcast packet with `persist=True`.
   - The Anchor saves the calibrated value into internal persistent Flash memory (`sys_flash_storage`).
   - The calibrated delay is permanently applied across all subsequent reboots.

---

## 5. Reference Values & Residual Error

| Parameter | Nominal Factory Default | Typical Calibrated Range | Post-Calibration Residual Error |
| --- | :---: | :---: | :---: |
| **Combined Delay (TX + RX)** | `32374` ($16187 + 16187$) | `32800 .. 33100` | $<\pm 0.03\text{ m}$ ($3\text{ cm}$) |
| **Single-Leg Delay** | `16187` | `16400 .. 16550` | $<\pm 0.03\text{ m}$ |

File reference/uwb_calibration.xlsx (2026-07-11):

Position | Anchor | Antenna Delay
(0,0) | 1 | 16439 | 16436 | 16318 | 16372 | 16422 | 16318
(0,976) | 2 | 16440 | 16361 | 16361 | 16447 | 16412 | 16278
(976,0) | 3 | 16435 | 16329 | 16278 | 16266 | 16316 | 16292
(976,976) | 4 | 16437 | 16234 | 16283 | 16266 | 16298 | 16251
Position | Anchor | Antenna Delay
(0.7,0.03) | 1 | 16383 | 16395 | 16448
(0.7,8.37) | 2 | 16304 | 16397 | 16379
(7.5,8.37) | 3 | 16292 | 16307 | 16318
(7.5,0.03) | 4 | 16274 | 16286 | 16339

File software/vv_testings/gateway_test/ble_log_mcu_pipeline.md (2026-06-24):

# BLE Log Pipeline: Host -> Dongle -> FS-BT630 -> MCU

File này mô tả chu trình lấy log BLE từ host xuống MCU và chiều log từ MCU trả về host.

## Thành phần

- Host: script `software/vv_testings/gateway_test/test_ble_log.py`.
- Dongle: nhận command từ host PC, bridge command sang BLE central.
- FS-BT630/peripheral: nhận BLE NUS RX từ dongle/central, forward qua UART xuống MCU; nhận UART từ MCU rồi forward ngược qua BLE.
- MCU UWB: xử lý protobuf command trong `firmware/common/network/network_cmd.c`, đọc log từ RAM/FLASH logger và gửi `log_data`.

## Packet chính

- `log_data` tag 43:
  - Host gửi `log_data` với `type=LOG_TYPE_DEVICE_LOG` để yêu cầu MCU trả log.
  - MCU cũng dùng tag này để trả payload log về host.
- `log_clear` tag 44:
  - Host gửi sau khi đã nhận và xử lý xong một chunk `log_data`.
  - MCU dùng `length` để consume log khỏi RAM/FLASH.
- `ack`:
  - ACK transport cho một packet cụ thể, dựa trên `ack_seq`.
  - ACK không đồng nghĩa với consume log. ACK chỉ nói packet `log_data` đã tới host.

## Chu trình đúng cho một lần lấy log

1. Host gửi request:
   - Host tạo packet `log_data`.
   - `hdr.src = HOST`, `hdr.dst = MCU`, `hdr.seq = next_seq`.
   - `log_data.type = LOG_TYPE_DEVICE_LOG`.

2. Packet đi qua đường truyền:
   - Host PC -> dongle.
   - Dongle -> BLE central/peripheral link.
   - FS-BT630 nhận BLE NUS RX.
   - FS-BT630 forward frame qua UART xuống MCU.

3. MCU nhận `log_data_get`:
   - Handler: `network_cmd_log_data_get()`.
   - MCU đánh dấu log stream active.
   - `s_log_stream_dst = pkt->hdr.addr.src`.
   - Nếu đang `waiting_ack`, code hiện tại reset tracker cũ để tránh kẹt.
   - MCU gọi `network_send_log(dst, max_payload)`.

4. MCU gửi log:
   - Nếu `s_log_tracker.waiting_ack == true`: MCU không gửi chunk mới, vì chunk trước chưa được ACK.
   - Nếu `s_log_tracker.waiting_clear == true`: MCU chờ host gửi `log_clear`; chưa clear thì không gửi chunk mới trong khoảng `WAIT_TIME_TO_CLEAR_LOG_MS`.
   - Nếu logger không có data: return.
   - Nếu có data:
     - MCU peek một chunk từ RAM/FLASH logger.
     - Gửi packet `log_data` về host.
     - Set:
       - `waiting_ack = true`
       - `waiting_clear = false`
       - `log_len = read_len`
       - `sent_tick = now`
     - Đăng ký ACK tracker bằng `network_core_wait_ack(seq, ..., log_tracker_callback, ...)`.

5. MCU -> host:
   - MCU -> UART -> FS-BT630.
   - FS-BT630 forward qua BLE.
   - Dongle nhận BLE.
   - Host script nhận packet `log_data`.

6. Host xử lý `log_data`:
   - Host parse payload log và in ra terminal.
   - Host gửi `ack` cho packet `log_data` vừa nhận:
     - `ack.ack_seq = seq` của packet `log_data` từ MCU.
     - `ack.response = ACK`.

7. MCU nhận ACK:
   - ACK tracker gọi `log_tracker_callback()`.
   - Nếu ACK state là `FOUND` và `log_len > 0`:
     - `waiting_ack = false`
     - `waiting_clear = true`
     - `sent_tick = now`
     - `tracker_id = -1`
   - Lúc này MCU biết host đã nhận chunk, nhưng vẫn chưa được phép consume log nếu chưa có `log_clear`.

8. Host gửi `log_clear`:
   - Sau khi host đã xử lý xong payload, host nên gửi `log_clear`.
   - `log_clear.type = LOG_TYPE_DEVICE_LOG`.
   - `log_clear.offset = 0`.
   - `log_clear.length = số byte payload log_data đã xử lý`.

9. MCU nhận `log_clear`:
   - Handler: `network_cmd_log_clear()`.
   - Với RAM logger: gọi `sys_logger_ram_consume(length)`.
   - Với FLASH logger: gọi `sys_logger_flash_consume(length)`.
   - Nếu `length == 0` hoặc `length >= s_log_tracker.log_len`:
     - `waiting_ack = false`
     - `waiting_clear = false`
     - `log_len = 0`
     - `tracker_id = -1`
   - Nếu clear một phần:
     - `log_len -= length`
     - tiếp tục chờ clear phần còn lại.

10. Lặp chu trình:
    - Host tiếp tục poll `log_data_get`.
    - MCU chỉ gửi chunk mới khi không còn kẹt `waiting_ack` hoặc `waiting_clear`.

## ACK và clear có gửi cùng lúc không?

Không nên hiểu là một gói duy nhất.

Host cần gửi hai packet khác nhau:

1. `ack`: xác nhận đã nhận packet `log_data` theo `seq`.
2. `log_clear`: xác nhận đã xử lý xong payload và cho phép MCU consume log khỏi RAM/FLASH.

Hai packet này có thể được gửi rất sát nhau về mặt thời gian, nhưng về logic là hai bước khác nhau. MCU cần ACK trước để clear `waiting_ack`, sau đó cần `log_clear` để clear `waiting_clear` và consume log.

## Flow hiện tại trong `test_ble_log.py`

Script hiện tại:

- Có gửi `log_data_get` theo chu kỳ.
- Có gửi `ack` sau khi nhận `log_data`.
- Có `log_clear_all` lúc bootstrap nếu bật `--clear-first`.
- Chưa thấy gửi `log_clear(length=len(payload))` sau mỗi chunk `log_data`.

Vì vậy nếu MCU đang dùng cơ chế `waiting_clear`, host chỉ ACK thôi là chưa đủ. MCU có thể chuyển từ `waiting_ack` sang `waiting_clear`, rồi đứng chờ clear; các lần `log_data_get` tiếp theo sẽ bị block bởi `waiting_clear` cho đến timeout hoặc đến khi nhận `log_clear`.

## Điểm nghẽn cần debug

- Host có gửi `log_data_get` đều không:
  - Xem `log_get_tx` trong stats host.
- Peri có nhận đủ BLE RX không:
  - Xem counter BLE RX và UART TX bên FS-BT630.
- MCU có nhận `log_data_get` không:
  - Watch counter debug ở `network_cmd_log_data_get()`.
- MCU có gửi được `log_data` không:
  - Watch send success/fail trong `network_send_log()`.
- MCU có kẹt `waiting_ack` không:
  - Nếu kẹt ở đây, host ACK không về hoặc ACK seq không match.
- MCU có kẹt `waiting_clear` không:
  - Nếu kẹt ở đây, host đã ACK nhưng chưa gửi `log_clear`.
- MCU có consume log không:
  - Watch `network_cmd_log_clear()`, `log_clear_bytes`, và pending bytes trong logger.

## Kết luận flow chuẩn

Flow chuẩn nên là:

```text
host: log_data_get
  -> dongle
  -> FS-BT630
  -> MCU

MCU: network_cmd_log_data_get()
MCU: network_send_log()
MCU: log_data(seq=N, data=chunk)
  -> FS-BT630
  -> dongle
  -> host

host: parse/in log chunk
host: ack(ack_seq=N)
  -> MCU

MCU: log_tracker_callback(ACK_FOUND)
MCU: waiting_ack=false, waiting_clear=true

host: log_clear(length=len(chunk))
  -> MCU

MCU: consume RAM/FLASH log
MCU: waiting_clear=false

host: poll log_data_get tiếp theo
```

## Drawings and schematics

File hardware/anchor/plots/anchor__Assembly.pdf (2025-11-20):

C8 BATTERY | C13 | C¹⁵ | C12 R18 | C21 C20 R⁷ | 10k C17

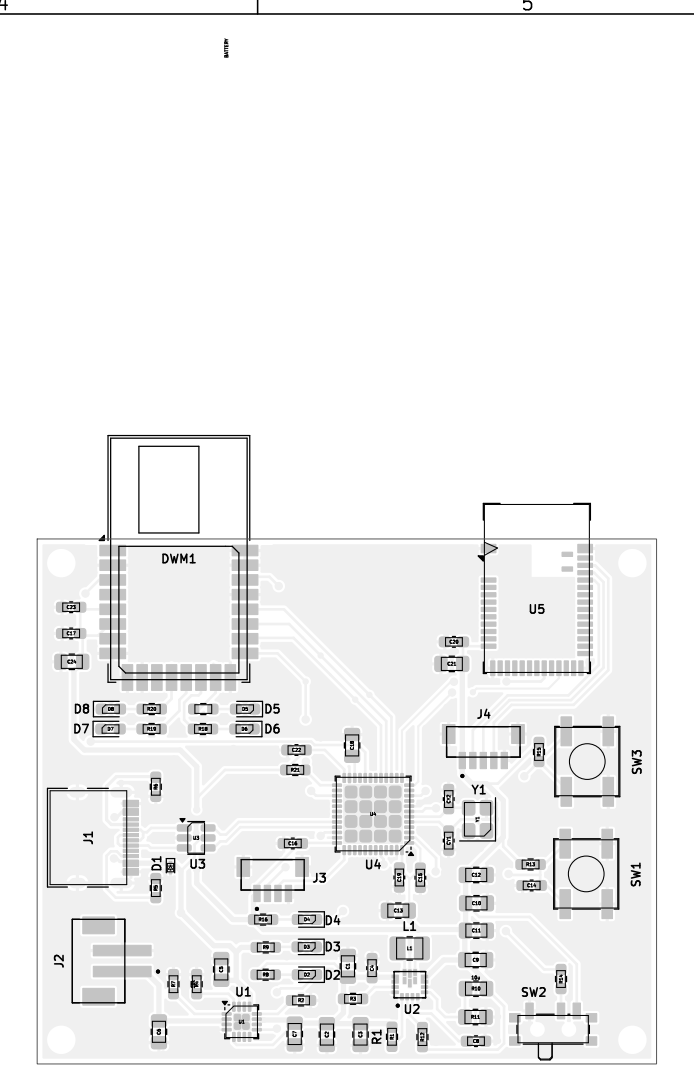
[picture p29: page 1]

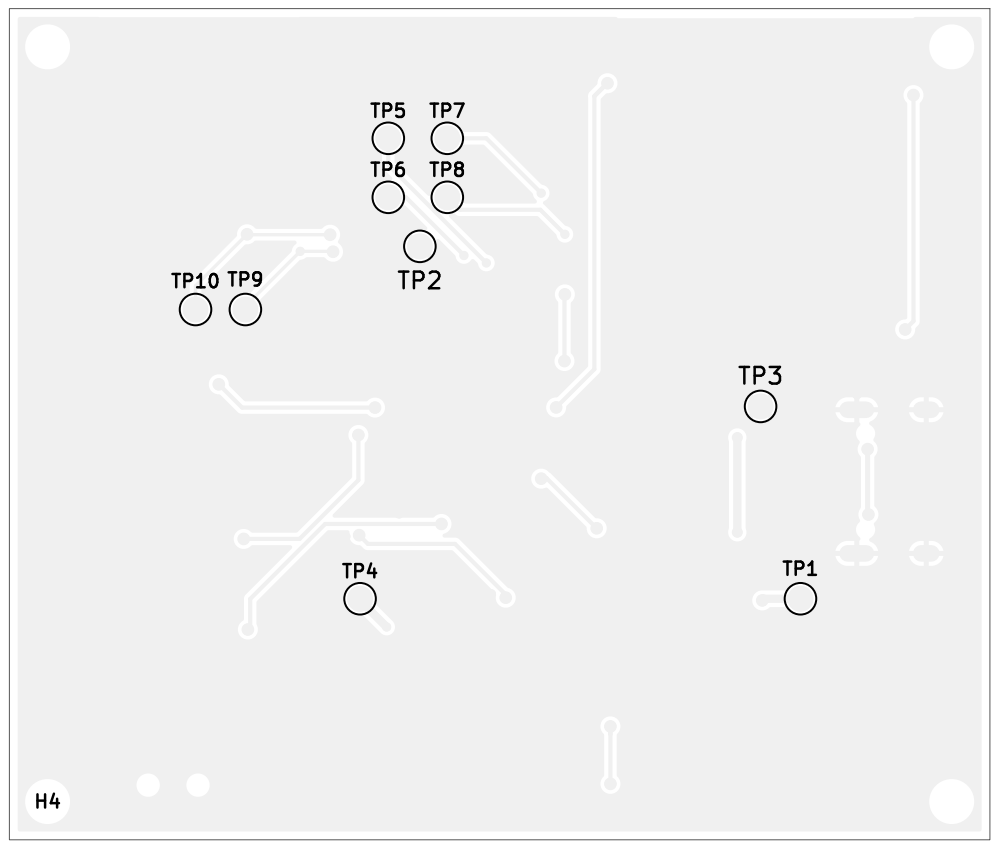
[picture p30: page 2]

C8 BATTERY | C13 | C¹⁵ | C12 R18 | C21 C20 R⁷ | 10k C17

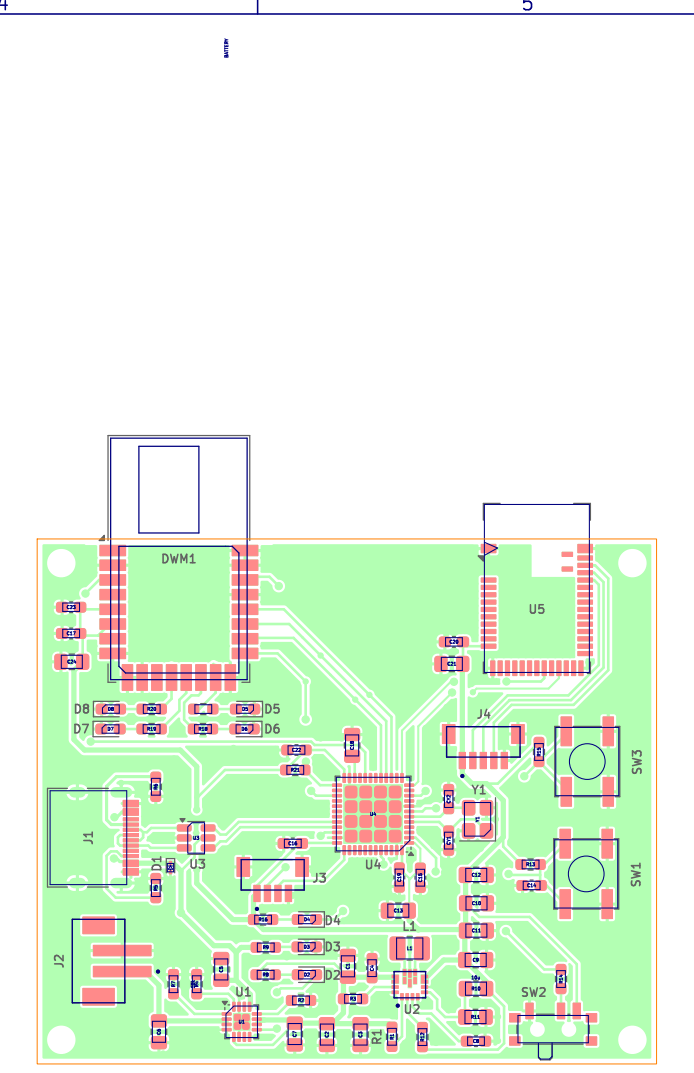
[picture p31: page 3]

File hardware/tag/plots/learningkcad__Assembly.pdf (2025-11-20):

A

A

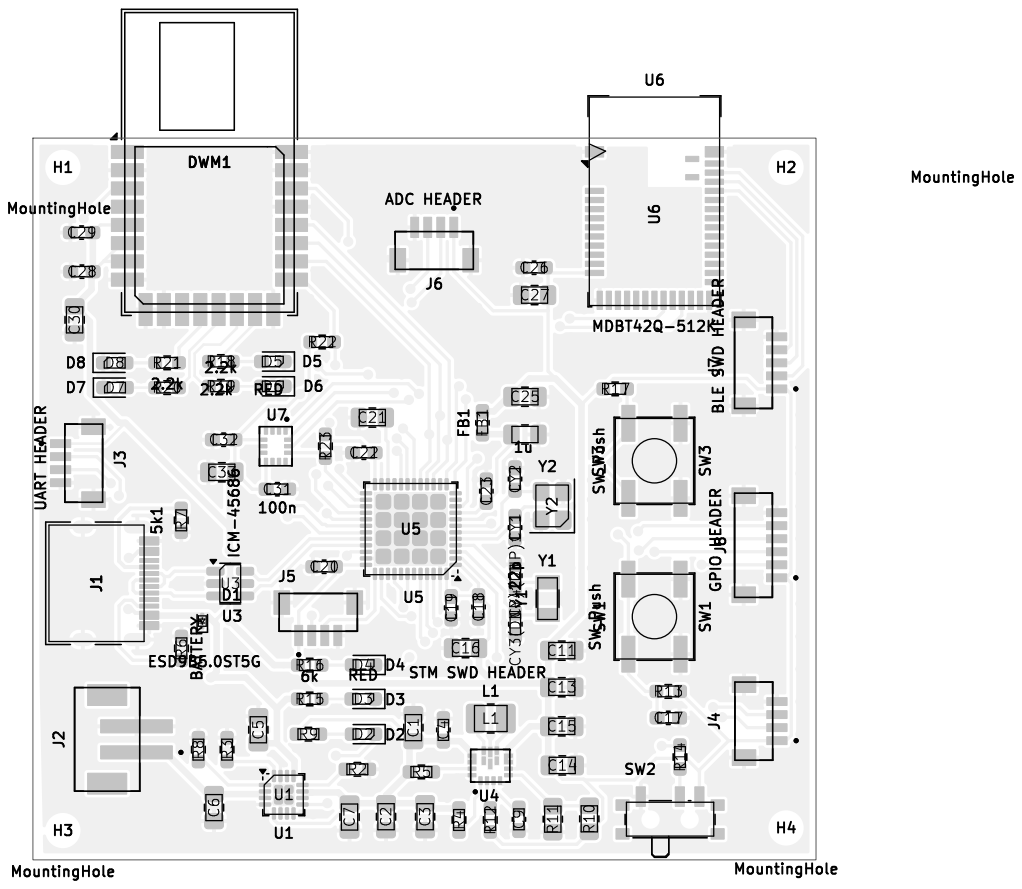
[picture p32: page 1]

A

A

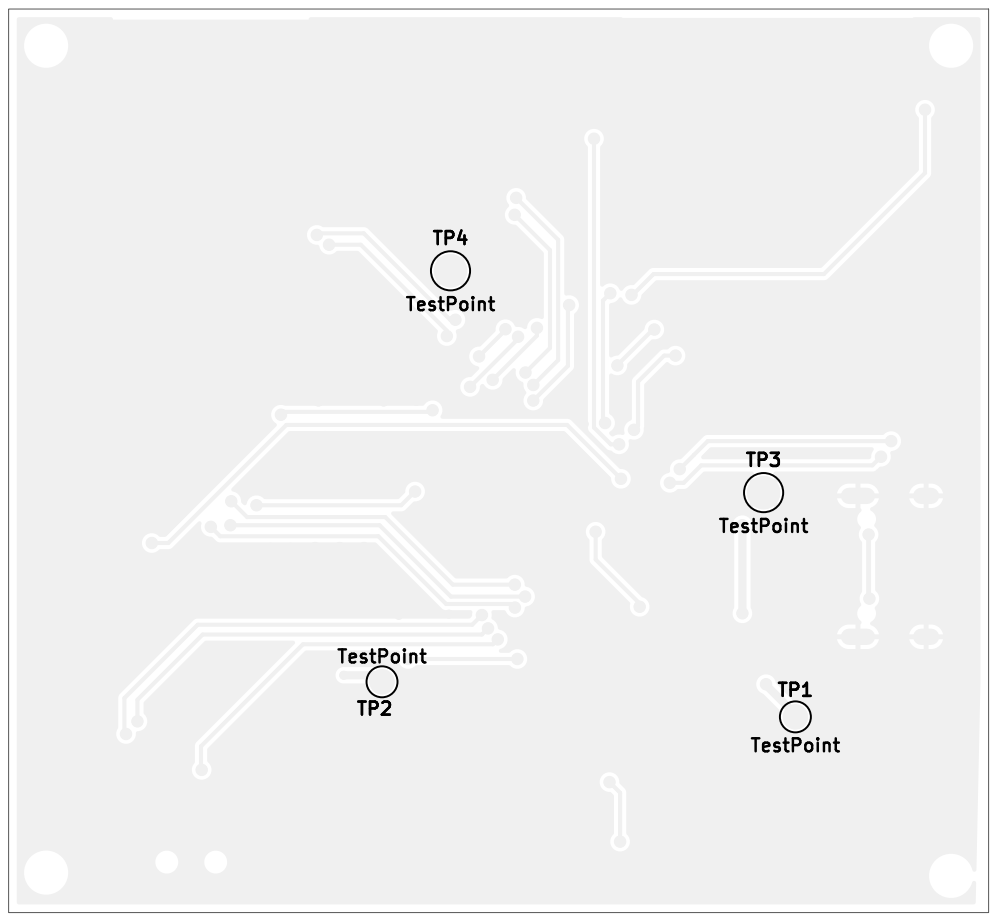
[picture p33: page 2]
D Date: KiCad; E.D.A. 9.0.4 Size: A4; Rev:; Id: /1 Title: File: learningkcad.kicad_pcb Sheet: Black; And; White; BOT Board2Pdf:; Black; BOT -; Page 2/3; TestPoint TP1 TestPoint TP2 TestPoint TP4; TestPoint TP3

A

A

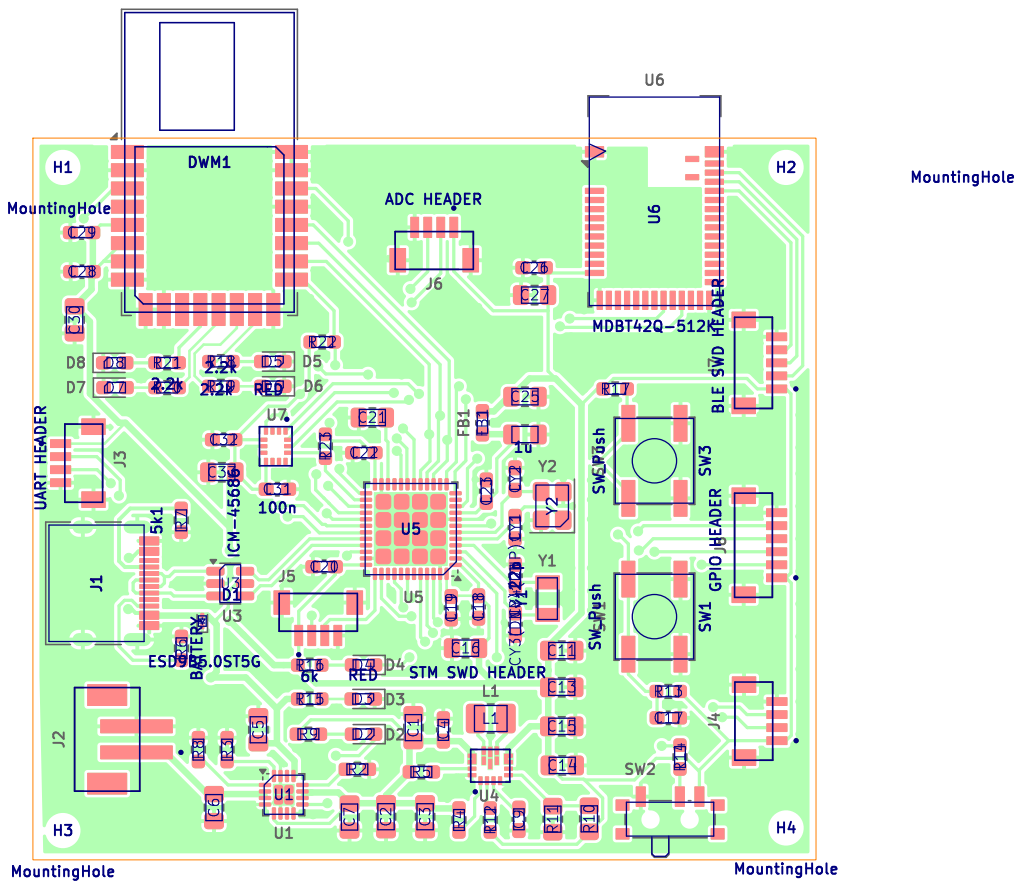
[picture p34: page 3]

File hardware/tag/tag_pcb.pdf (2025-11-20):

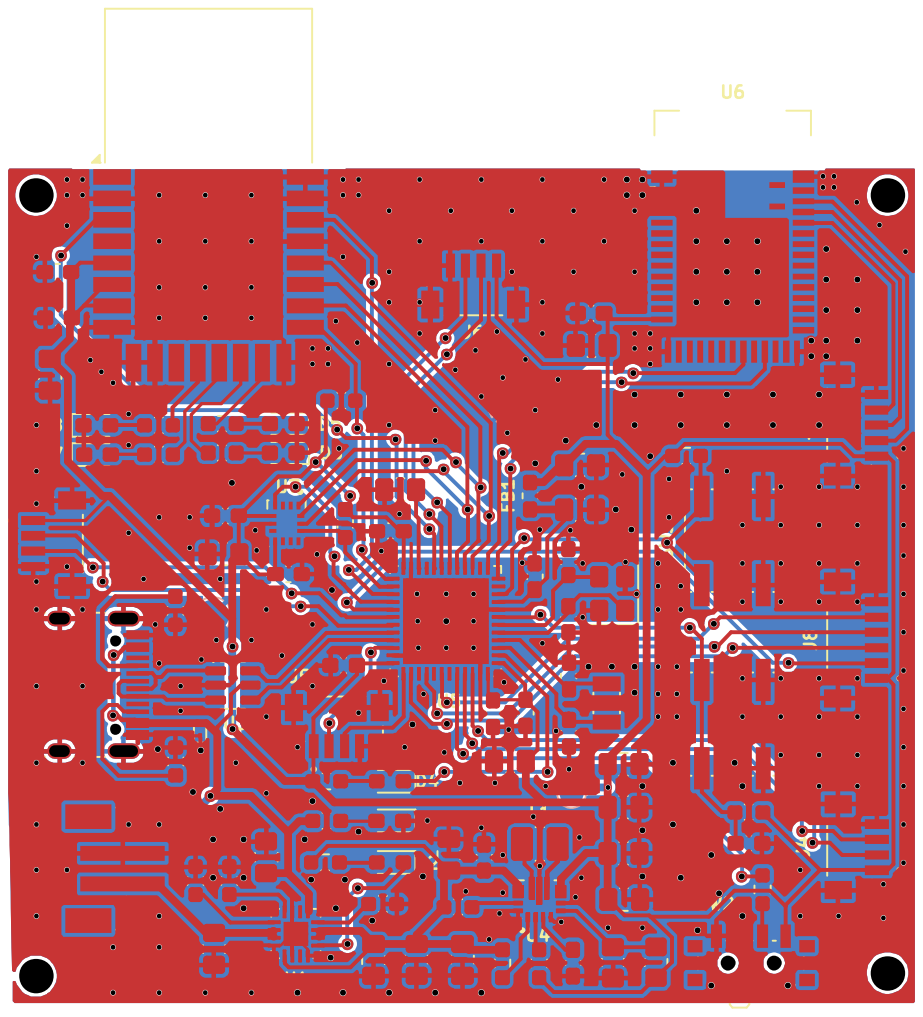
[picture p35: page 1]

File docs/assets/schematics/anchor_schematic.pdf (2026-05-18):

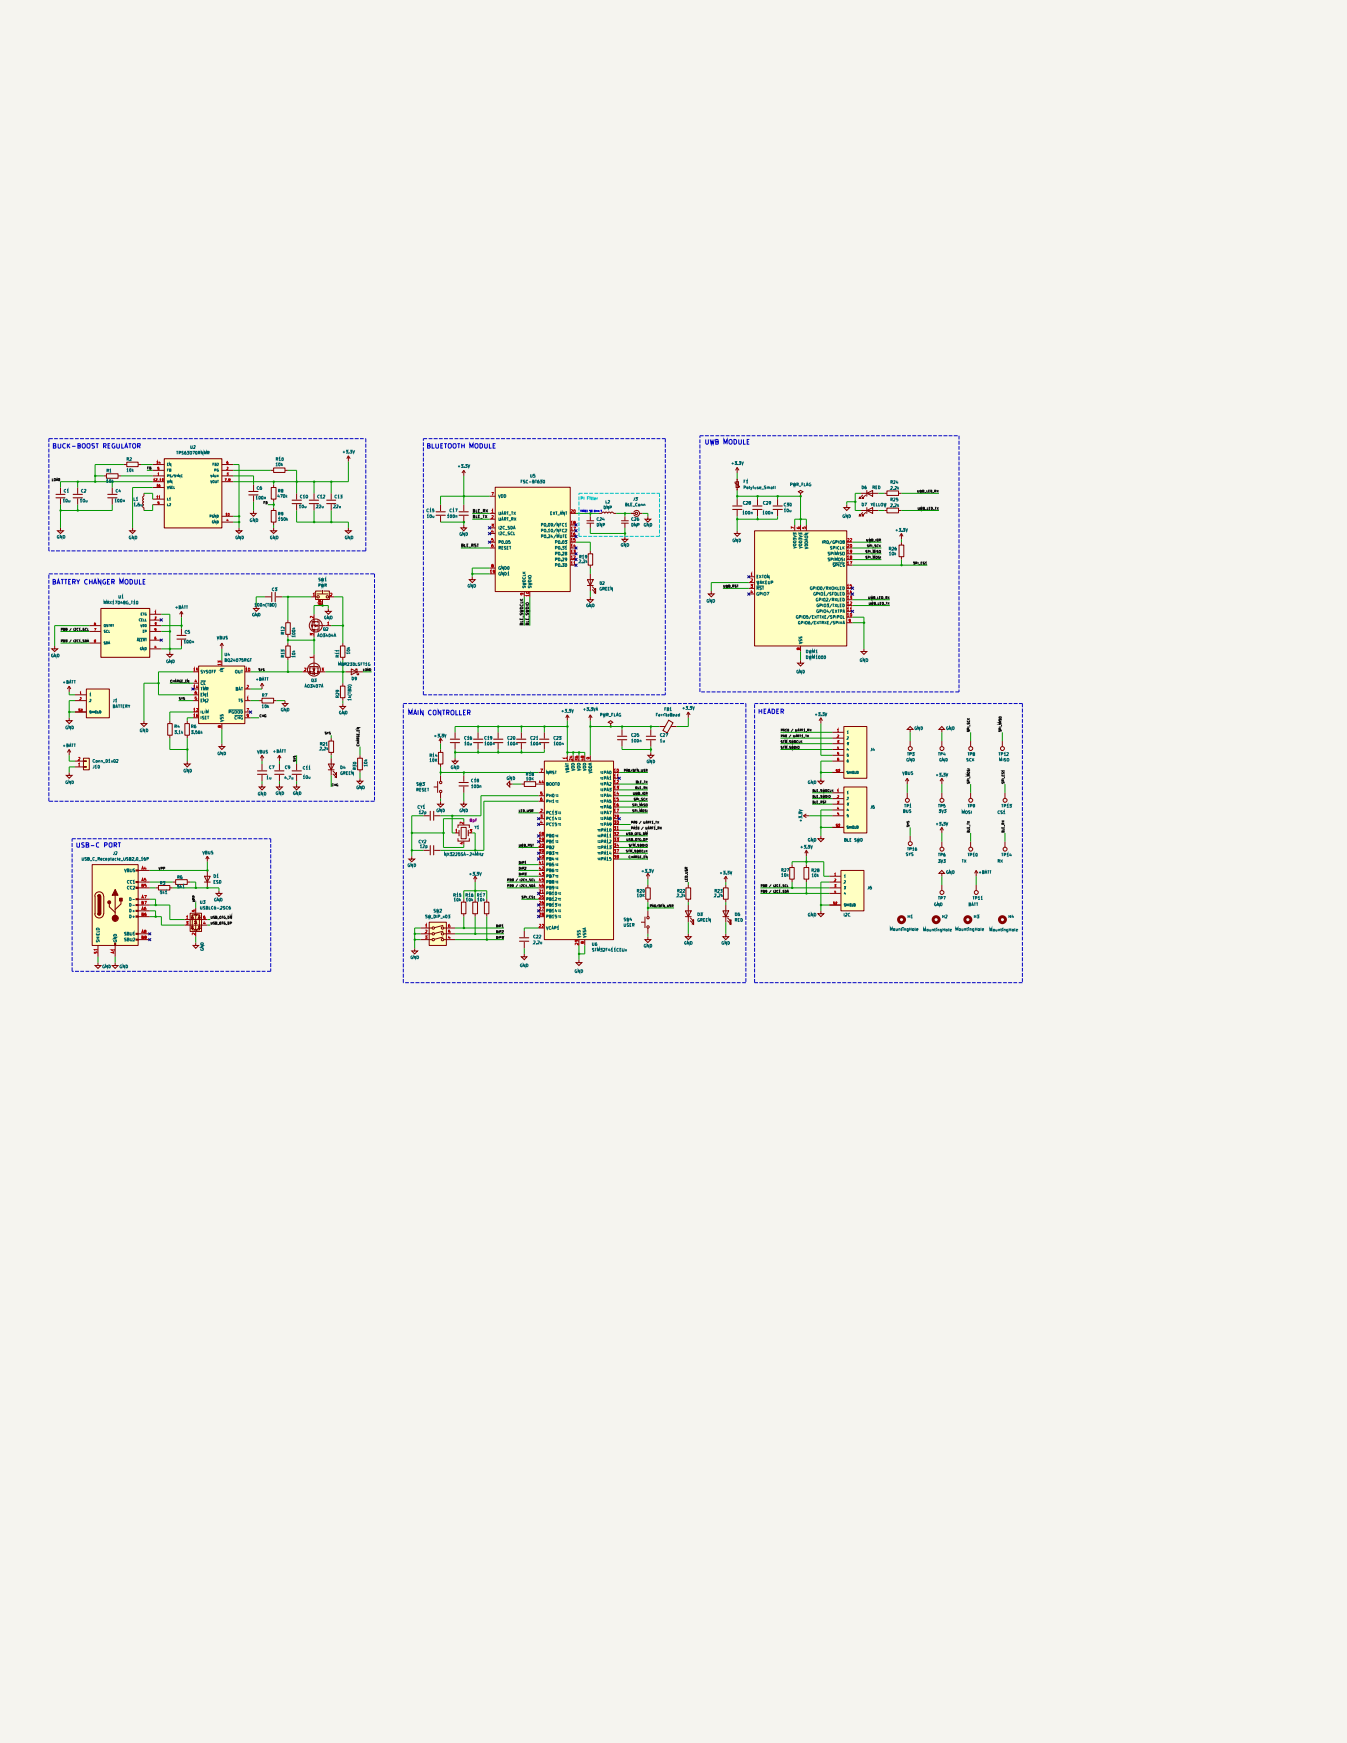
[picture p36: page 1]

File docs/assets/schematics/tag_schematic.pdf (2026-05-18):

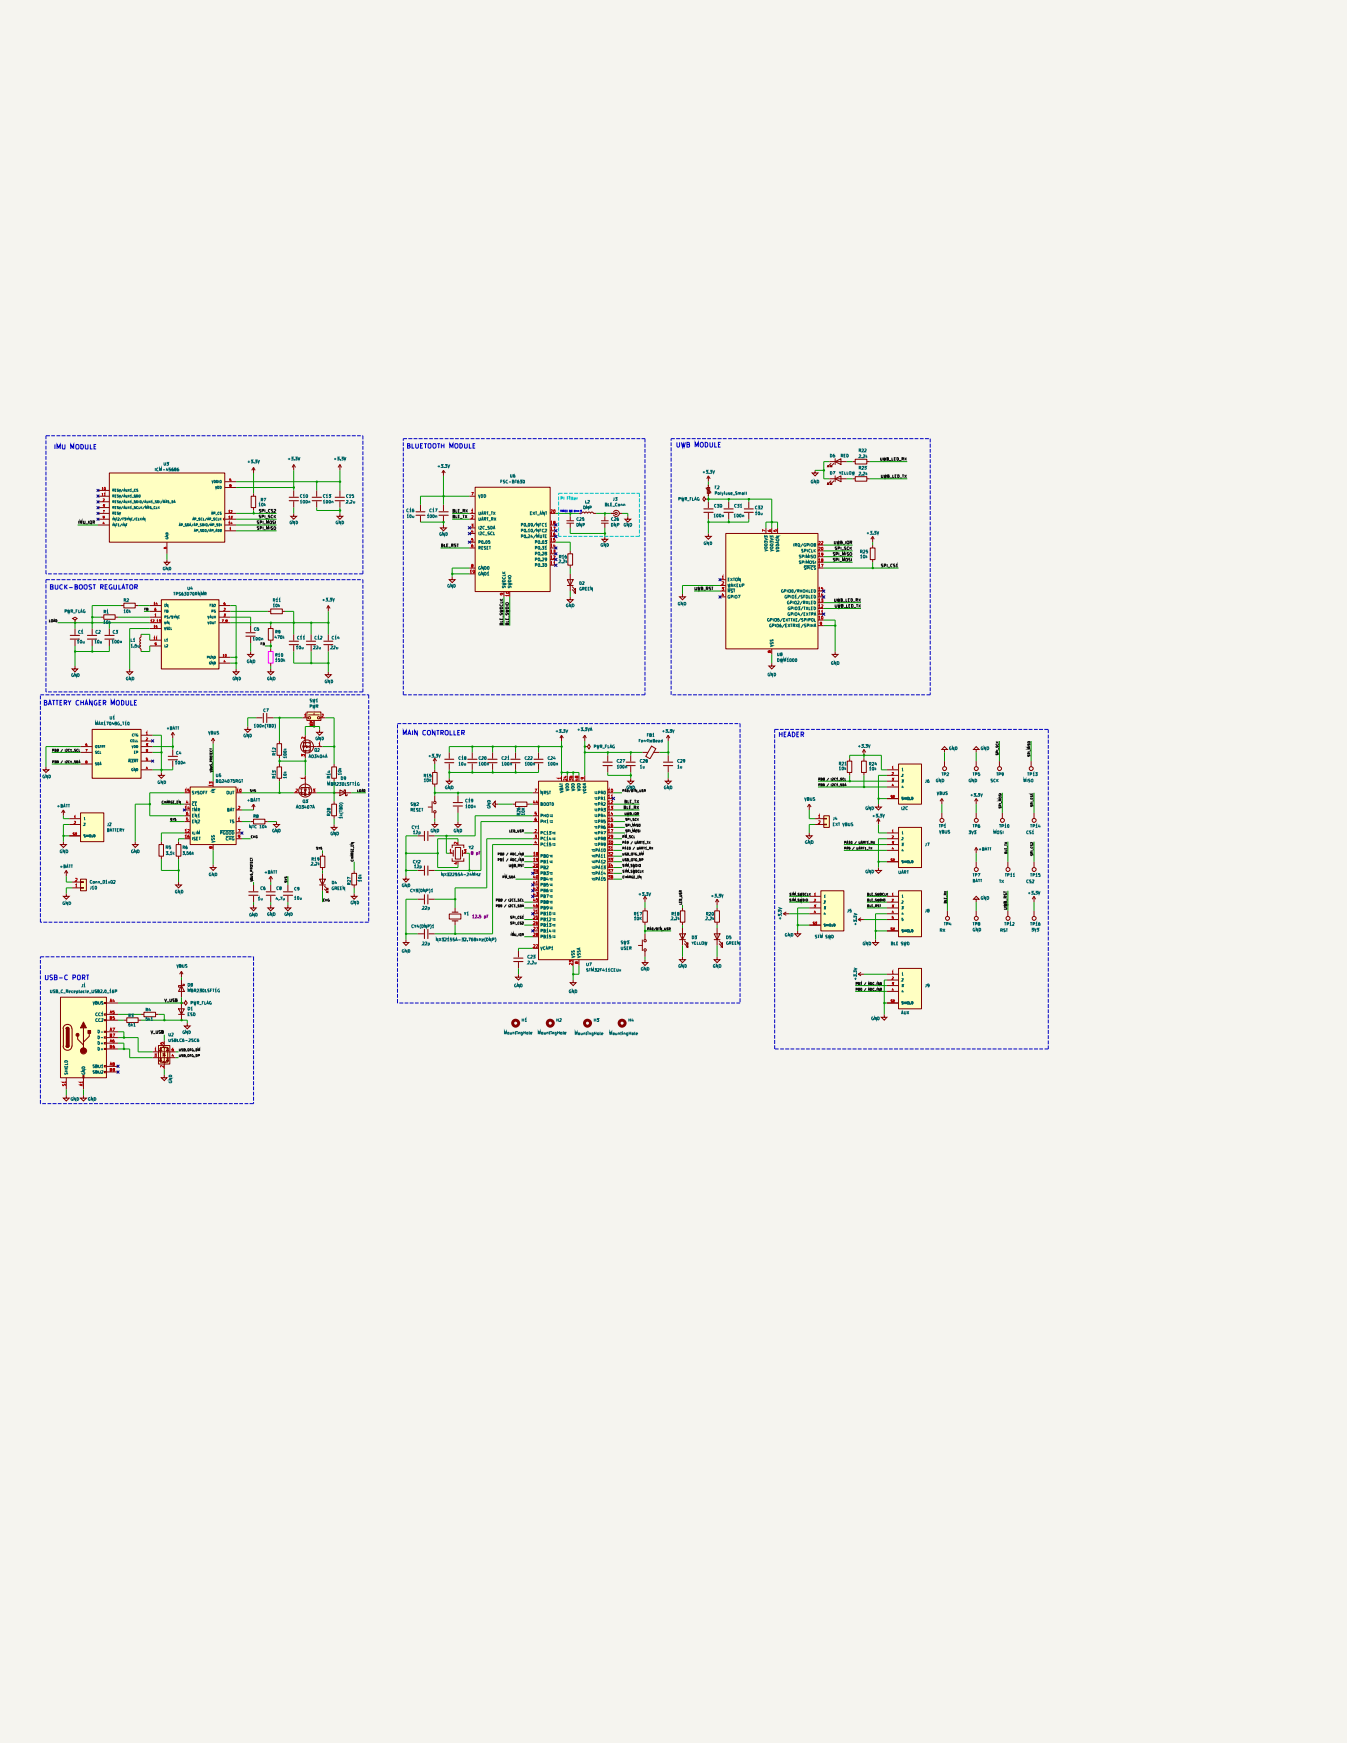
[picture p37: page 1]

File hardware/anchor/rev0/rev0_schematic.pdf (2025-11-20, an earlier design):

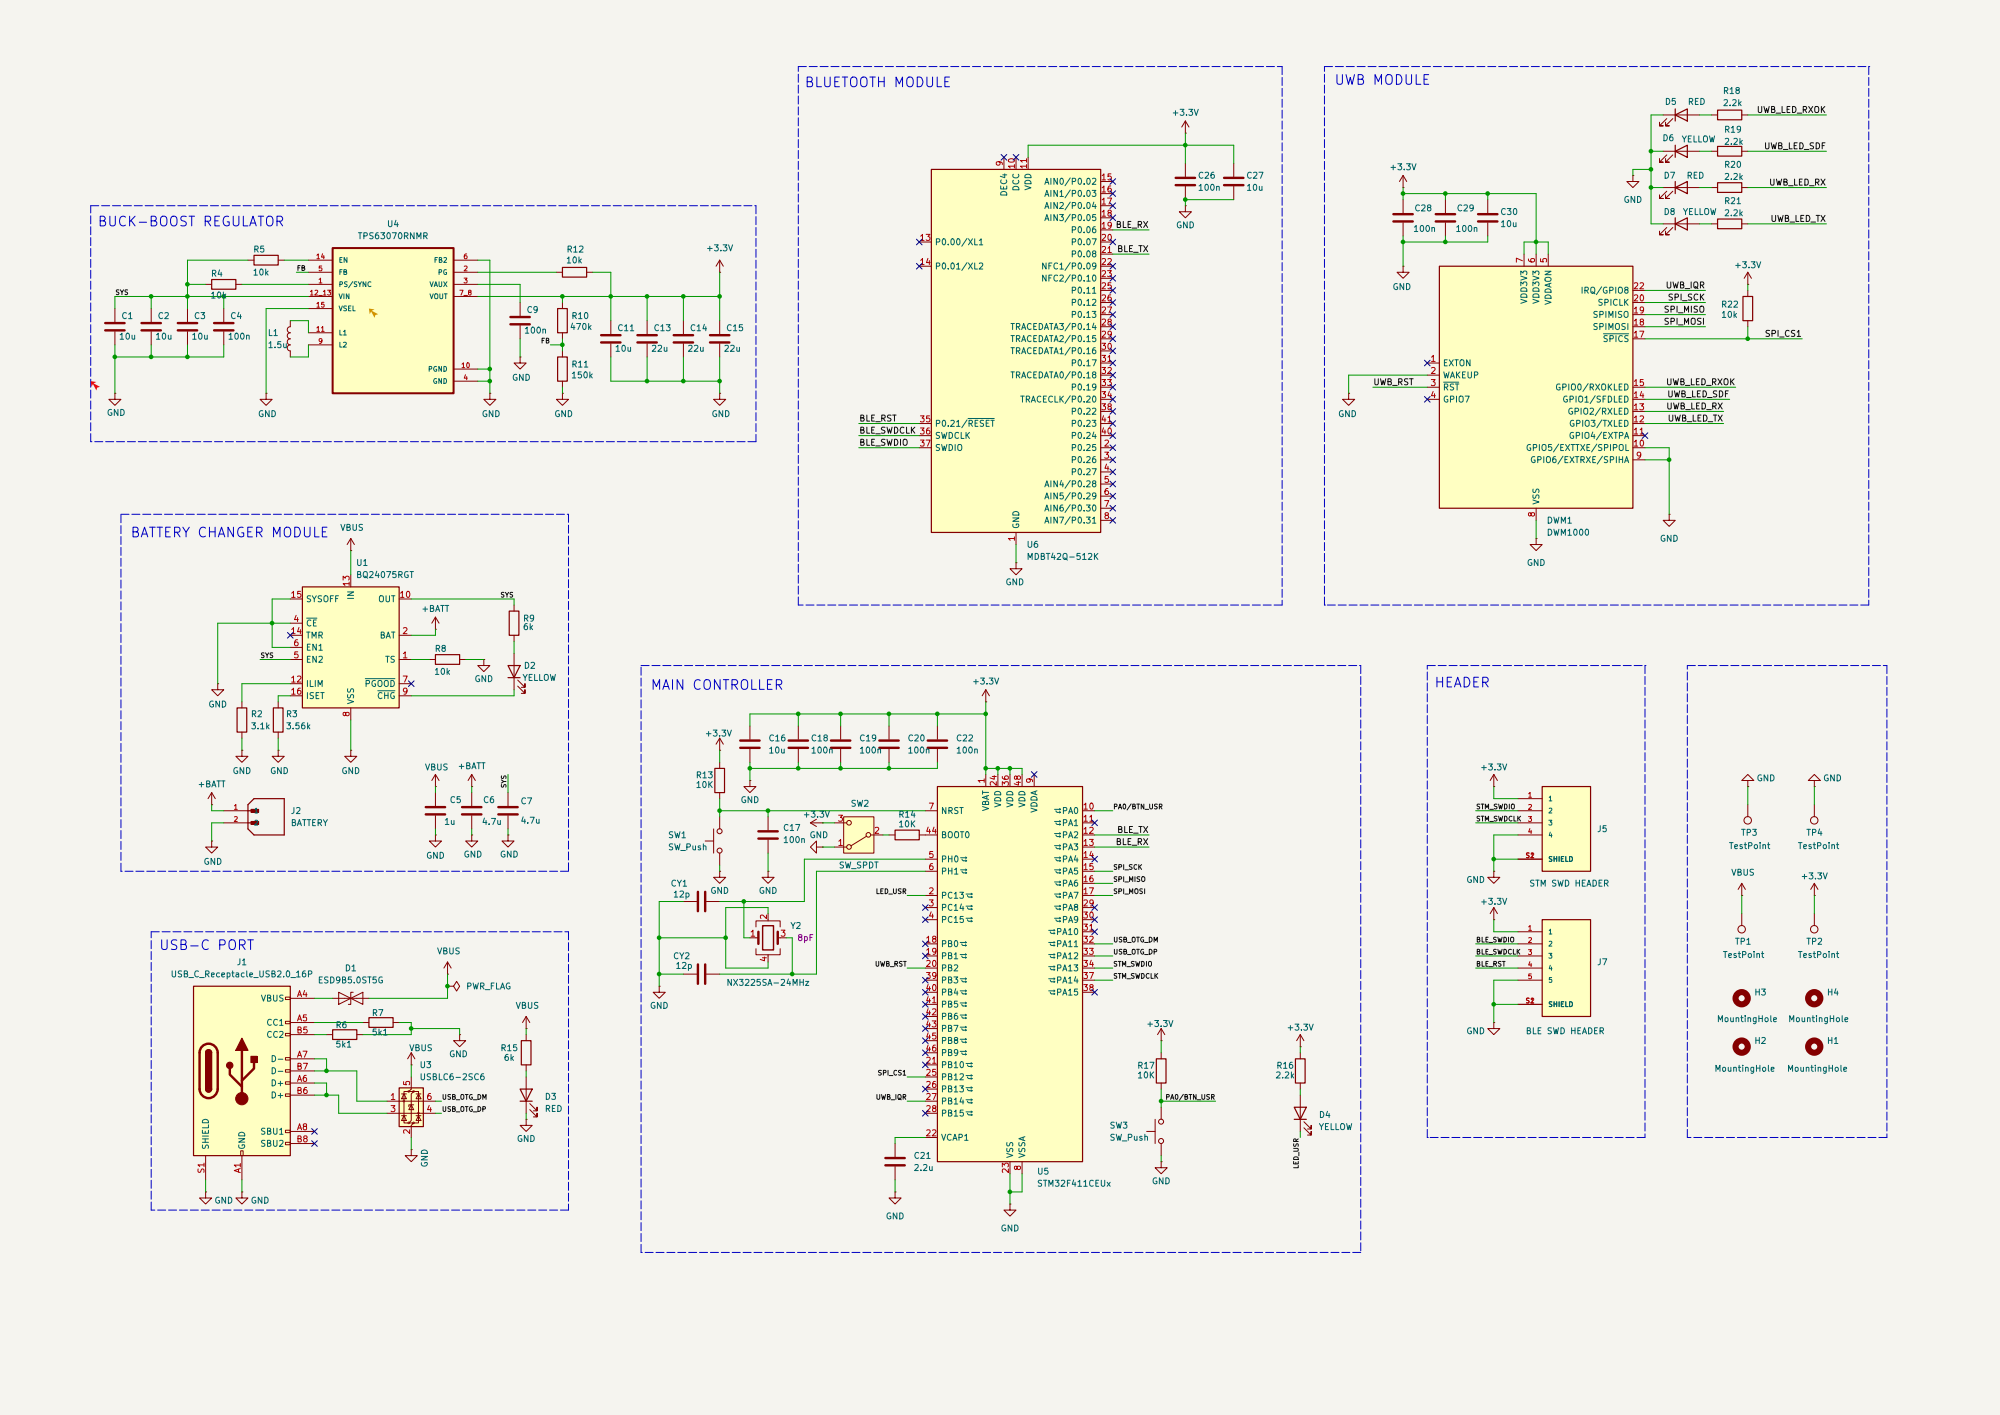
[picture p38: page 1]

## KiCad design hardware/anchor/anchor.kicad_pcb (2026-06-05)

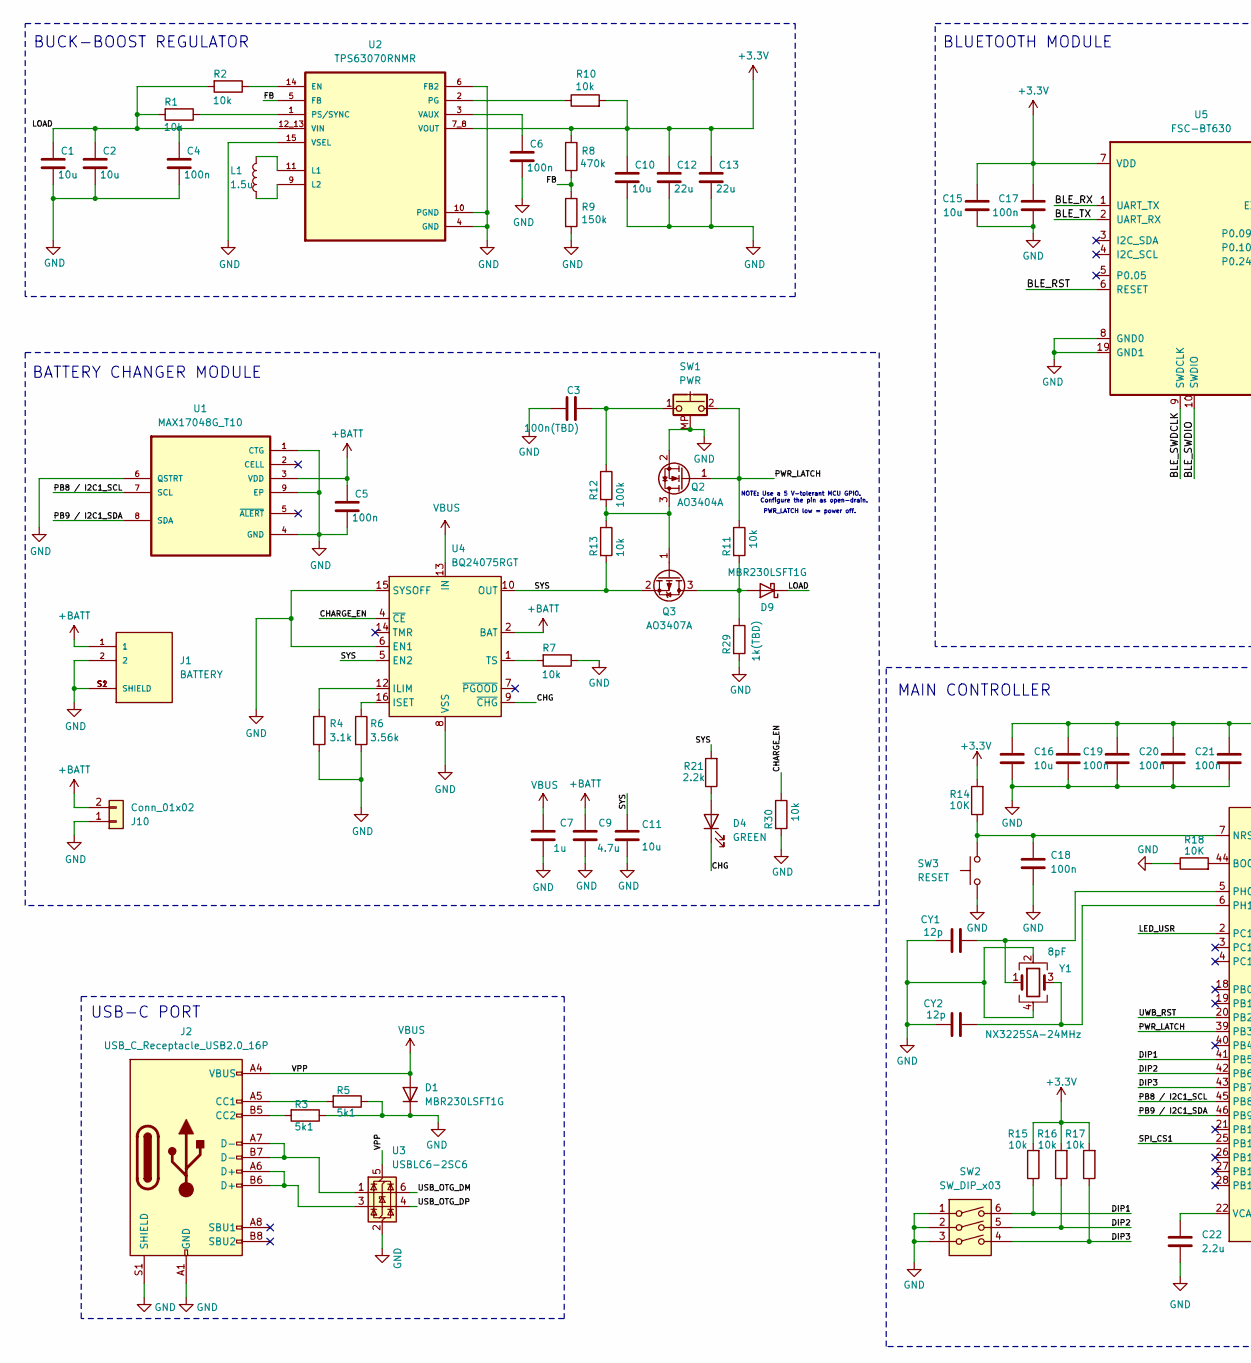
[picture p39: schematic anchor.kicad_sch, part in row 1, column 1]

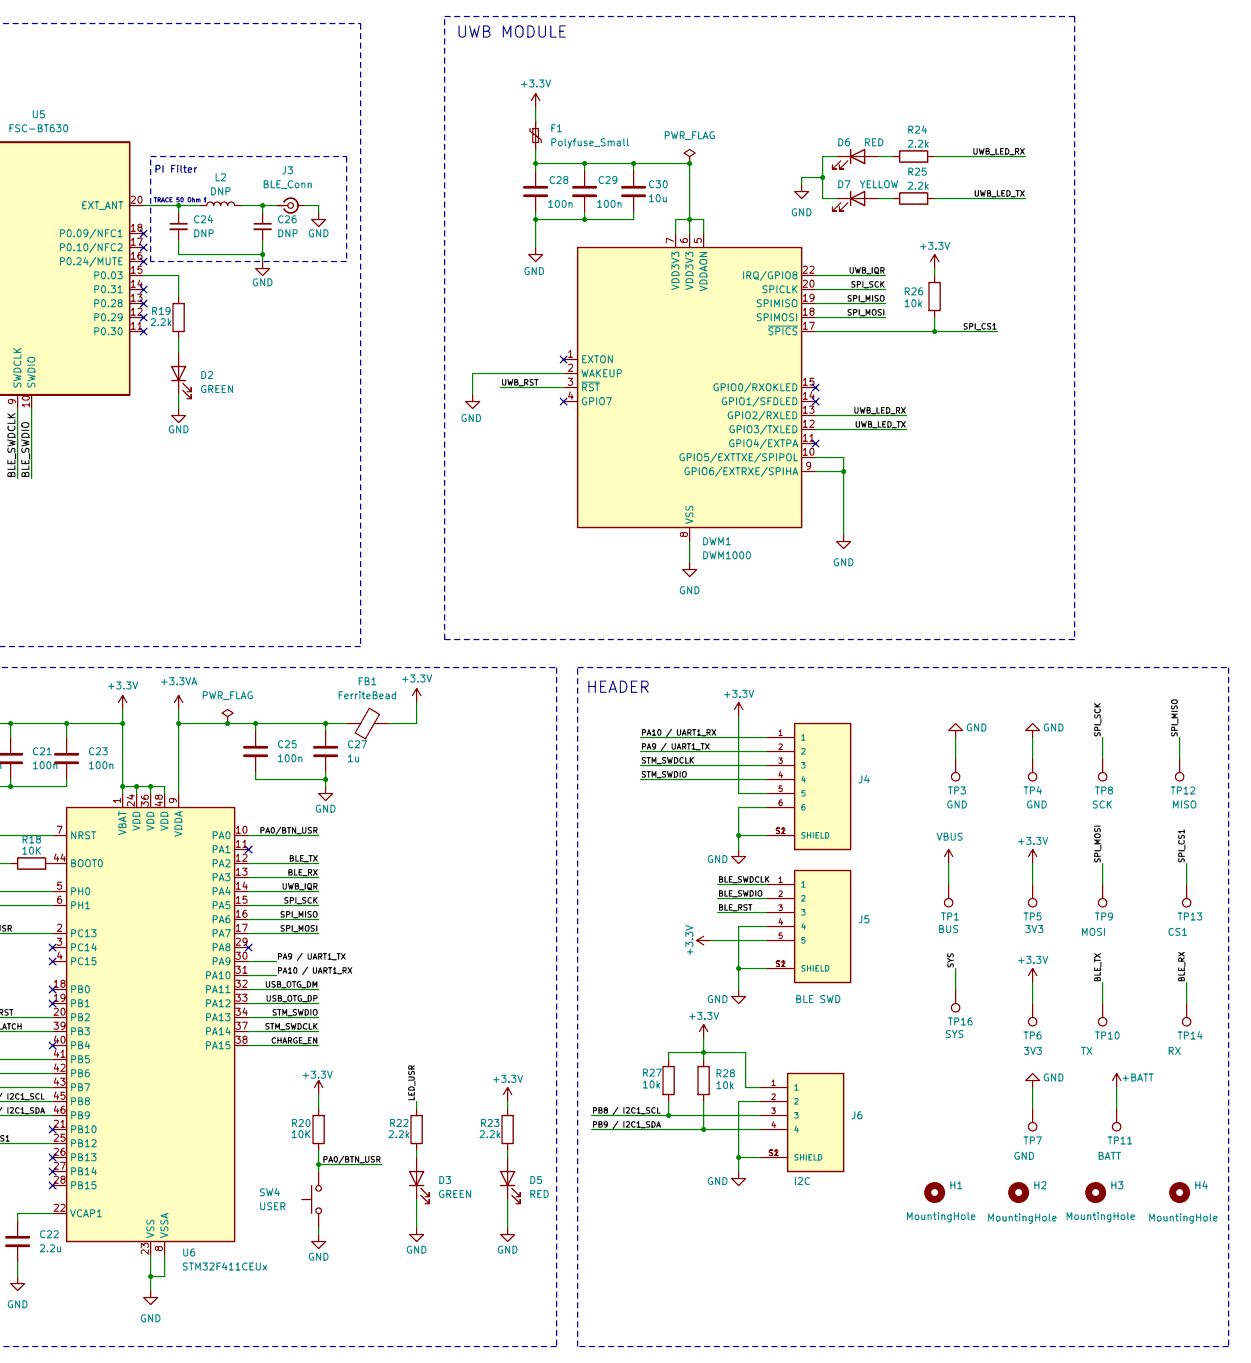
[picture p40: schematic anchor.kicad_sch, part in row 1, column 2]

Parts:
C1, C2, C10, C11: 10u; C_0805_2012Metric
C3: 100n(TBD); C_0603_1608Metric
C4, C5, C6: 100n; C_0603_1608Metric
C7: 1u; C_0805_2012Metric
C9: 4.7u; C_0805_2012Metric
C12, C13: 22u; C_0805_2012Metric
C15, C16, C30: 10u; C_0805_2012Metric_Pad1.18x1.45mm_HandSolder
C17, C18, C19, C20, C21, C23, C25, C28, C29: 100n; C_0603_1608Metric_Pad1.08x0.95mm_HandSolder
C22: 2.2u; C_0805_2012Metric_Pad1.18x1.45mm_HandSolder
C24, C26: DNP; C_0402_1005Metric
C27: 1u; C_0805_2012Metric_Pad1.18x1.45mm_HandSolder
CY1, CY2: 12p; C_0603_1608Metric_Pad1.08x0.95mm_HandSolder
D1: MBR230LSFT1G; D_SOD-323
D2, D3, D4: GREEN; LED_0603_1608Metric_Pad1.05x0.95mm_HandSolder
D5, D6: RED; LED_0603_1608Metric_Pad1.05x0.95mm_HandSolder
D7: YELLOW; LED_0603_1608Metric_Pad1.05x0.95mm_HandSolder
D9: MBR230LSFT1G; D_SOD-123
DWM1: DWM1000
F1: Polyfuse_Small; Fuse_1206_3216Metric
FB1: FerriteBead; L_0603_1608Metric_Pad1.05x0.95mm_HandSolder
H1, H2, H3, H4: MountingHole; MountingHole_2.2mm_M2
J1: BATTERY; JST_BM02B-SRSS-TB_LF__SN_; PARTREV N/A
J2: USB_C_Receptacle_USB2.0_16P; USB_C_Receptacle_HRO_TYPE-C-31-M-12
J3: BLE_Conn; U.FL_Hirose_U.FL-R-SMT-1_Vertical
J4: BM06B-SRSS-TB_LF__SN_; JST_SH_BM06B-SRSS-TB_1x06-1MP_P1.00mm_Vertical; PARTREV N/A
J5: BLE SWD; JST_BM05B-SRSS-TB_LF__SN_; PARTREV N/A
J6: I2C; JST_BM04B-SRSS-TB_LF__SN_; PARTREV N/A
J10: Conn_01x02; SolderWire-0.1sqmm_1x02_P3.6mm_D0.4mm_OD1mm
L1: 1.5u; L_Sunlord_SWPA4020S
L2: DNP; L_0402_1005Metric
Q2: AO3404A; SOT-23
Q3: AO3407A; SOT-23
R1, R2, R7, R10, R11, R13, R30: 10k; R_0603_1608Metric
R3, R5: 5k1; R_0603_1608Metric_Pad0.98x0.95mm_HandSolder
R4: 3.1k; R_0603_1608Metric
R6: 3.56k; R_0603_1608Metric
R8: 470k; R_0805_2012Metric_Pad1.20x1.40mm_HandSolder
R9: 150k; R_0805_2012Metric_Pad1.20x1.40mm_HandSolder
R12: 100k; R_0603_1608Metric
R14, R18, R20: 10K; R_0603_1608Metric_Pad0.98x0.95mm_HandSolder
R15, R16, R17, R26, R27, R28: 10k; R_0603_1608Metric_Pad0.98x0.95mm_HandSolder
R19, R22, R23, R24, R25: 2.2k; R_0603_1608Metric_Pad0.98x0.95mm_HandSolder
R21: 2.2k; R_0603_1608Metric
R29: 1k(TBD); R_0603_1608Metric
SW1: PWR; SW_Push_1P1T-MP_NO_Horizontal_Alps_SKRTLAE010
SW2: SW_DIP_x03; SW_DIP_SPSTx03_Slide_KingTek_DSHP03TJ_W5.25mm_P1.27mm_JPin
SW3: RESET; SW_Tactile_SMD_3x4mm_2pin_update
SW4: USER; SW_Tactile_SMD_3x4mm_2pin_update
TP1: BUS; TestPoint_Pad_D1.5mm
TP3, TP7: GND; TestPoint_Pad_D1.5mm
TP4: GND; TestPoint_Pad_1.0x1.0mm
TP5, TP6: 3V3; TestPoint_Pad_D1.5mm
TP8: SCK; TestPoint_Pad_D1.0mm
TP9: MOSI; TestPoint_Pad_D1.0mm
TP10: TX; TestPoint_Pad_D1.0mm
TP11: BATT; TestPoint_Pad_D1.5mm
TP12: MISO; TestPoint_Pad_D1.0mm
TP13: CS1; TestPoint_Pad_D1.0mm
TP14: RX; TestPoint_Pad_D1.0mm
TP16: SYS; TestPoint_Pad_D1.5mm
U1: MAX17048G_T10; SON-8-1EP_3x2mm_P0.5mm_EP1.4x1.6mm
U2: TPS63070RNMR; VREG_TPS63070RNMR
U3: USBLC6-2SC6; SOT-23-6
U4: BQ24075RGT; VQFN-16-1EP_3x3mm_P0.5mm_EP1.6x1.6mm
U5: FSC-BT630
U6: STM32F411CEUx; QFN-48-1EP_7x7mm_P0.5mm_EP5.6x5.6mm
Y1: NX3225SA-24MHz; Crystal_SMD_3225-4Pin_3.2x2.5mm

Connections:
+3.3V: C10.1, C12.1, C13.1, C15.1, C16.1, C17.1, C19.1, C20.1, C21.1, C23.1, F1.1, FB1.2, J4.5, J5.5, J6.1, R8.1, R10.2, R14.2, R15.2, R16.2, R17.2, R20.2, R23.2, R26.1, R27.1, R28.1, TP5.1, TP6.1, U2.7_8 (VOUT), U5.7 (VDD), U6.1 (VBAT), U6.24 (VDD), U6.36 (VDD), U6.48 (VDD)
+3.3VA: C25.1, C27.1, FB1.1, U6.9 (VDDA)
+BATT: C5.1, C9.1, J1.1, J10.2, TP11.1, U1.3 (VDD), U4.2 (BAT), U4.3 (BAT)
/BLE_RST: J5.3, U5.6 (RESET)
/BLE_RX: TP14.1, U5.1 (UART_TX), U6.13 (PA3)
/BLE_SWDCLK: J5.1, U5.9 (SWDCLK)
/BLE_SWDIO: J5.2, U5.10 (SWDIO)
/BLE_TX: TP10.1, U5.2 (UART_RX), U6.12 (PA2)
/CHARGE_EN: R30.1, U4.4 (~CE), U6.38 (PA15)
/CHG: D4.1 (K), U4.9 (~CHG)
/DIP1: R15.1, SW2.6, U6.41 (PB5)
/DIP2: R16.1, SW2.5, U6.42 (PB6)
/DIP3: R17.1, SW2.4, U6.43 (PB7)
/FB: R8.2, R9.1, U2.5 (FB)
/LED_USR: R22.2, U6.2 (PC13)
/LOAD: C1.1, C2.1, C4.1, D9.1 (K), R1.2, R2.2, U2.12_13 (VIN)
/PA0/BTN_USR: R20.1, SW4.2, U6.10 (PA0)
/PA9 / UART1_TX: J4.2, U6.30 (PA9)
/PA10 / UART1_RX: J4.1, U6.31 (PA10)
/PB8 / I2C1_SCL: J6.3, R27.2, U1.7 (SCL), U6.45 (PB8)
/PB9 / I2C1_SDA: J6.4, R28.2, U1.8 (SDA), U6.46 (PB9)
/PWR_LATCH: Q2.1 (G), R11.1, SW1.2, U6.39 (PB3)
/SPI_CS1: DWM1.17 (~SPICS), R26.2, TP13.1, U6.25 (PB12)
/SPI_MISO: DWM1.19 (SPIMISO), TP12.1, U6.16 (PA6)
/SPI_MOSI: DWM1.18 (SPIMOSI), TP9.1, U6.17 (PA7)
/SPI_SCK: DWM1.20 (SPICLK), TP8.1, U6.15 (PA5)
/STM_SWDCLK: J4.3, U6.37 (PA14)
/STM_SWDIO: J4.4, U6.34 (PA13)
/SYS: C11.1, Q3.2 (S), R13.2, R21.2, TP16.1, U4.5 (EN2), U4.10 (OUT), U4.11 (OUT)
/USB_OTG_DM: U3.6 (I/O1), U6.32 (PA11)
/USB_OTG_DP: U3.4 (I/O2), U6.33 (PA12)
/UWB_IQR: DWM1.22 (IRQ/GPIO8), U6.14 (PA4)
/UWB_LED_RX: DWM1.13 (GPIO2/RXLED), R24.2
/UWB_LED_TX: DWM1.12 (GPIO3/TXLED), R25.2
/UWB_RST: DWM1.3 (~RST), U6.20 (PB2)
GND: C1.2, C2.2, C3.1, C4.2, C5.2, C6.2, C7.1, C9.2, C10.2, C11.2, C12.2, C13.2, C15.2, C16.2, C17.2, C18.2, C19.2, C20.2, C21.2, C22.2, C23.2, C24.2, C25.2, C26.2, C27.2, C28.2, C29.2, C30.2, CY1.1, CY2.1, D1.1 (K), D2.1 (K), D3.1 (K), D5.1 (K), D6.1 (K), D7.1 (K), DWM1.2 (WAKEUP), DWM1.8 (VSS), DWM1.9 (GPIO6/EXTRXE/SPIHA), DWM1.10 (GPIO5/EXTTXE/SPIPOL), DWM1.16 (VSS), DWM1.21 (VSS), DWM1.23 (VSS), DWM1.24 (VSS), J1.2, J1.S1 (SHIELD), J1.S2 (SHIELD), J2.A1 (GND), J2.A12 (GND), J2.B1 (GND), J2.B12 (GND), J2.S1 (SHIELD), J3.2 (Ext), J4.6, J4.S1 (SHIELD), J4.S2 (SHIELD), J5.4, J5.S1 (SHIELD), J5.S2 (SHIELD), J6.2, J6.S1 (SHIELD), J6.S2 (SHIELD), J10.1, Q2.2 (S), R3.1, R4.2, R5.1, R6.2, R7.1, R9.2, R18.1, R29.2, R30.2, SW1.MP (B), SW2.1, SW2.2, SW2.3, SW3.1, SW4.1, TP3.1, TP4.1, TP7.1, U1.1 (CTG), U1.4 (GND), U1.6 (QSTRT), U1.9 (EP), U2.4 (GND), U2.6 (FB2), U2.10 (PGND), U2.15 (VSEL), U3.2 (GND), U4.6 (EN1), U4.8 (VSS), U4.15 (SYSOFF), U4.17 (VSS), U5.8 (GND0), U5.19 (GND1), U6.8 (VSSA), U6.23 (VSS), U6.35 (VSS), U6.47 (VSS), U6.49 (VSS), Y1.2, Y1.4
unnamed: C3.2, R12.1, SW1.1
unnamed: D2.2 (A), R19.1
unnamed: D3.2 (A), R22.1
unnamed: D4.2 (A), R21.1
unnamed: D5.2 (A), R23.1
unnamed: D6.2 (A), R24.1
unnamed: D7.2 (A), R25.1
unnamed: D9.2 (A), Q3.3 (D), R11.2, R29.1
unnamed: C28.1, C29.1, C30.1, DWM1.5 (VDDAON), DWM1.6 (VDD3V3), DWM1.7 (VDD3V3), F1.2
unnamed: J2.A5 (CC1), R5.2
unnamed: J2.B5 (CC2), R3.2
unnamed: J2.A6 (D+), J2.B6 (D+), U3.3 (I/O2)
unnamed: J2.A7 (D-), J2.B7 (D-), U3.1 (I/O1)
unnamed: C26.1, J3.1 (In), L2.2
unnamed: Q2.3 (D), Q3.1 (G), R12.2, R13.1
unnamed: R2.1, U2.14 (EN)
unnamed: L1.2, U2.11 (L1)
unnamed: L1.1, U2.9 (L2)
unnamed: R10.1, U2.2 (PG)
unnamed: R1.1, U2.1 (PS/SYNC)
unnamed: C6.1, U2.3 (VAUX)
unnamed: R4.1, U4.12 (ILIM)
unnamed: R6.1, U4.16 (ISET)
unnamed: R7.2, U4.1 (TS)
unnamed: C24.1, L2.1, U5.20 (EXT_ANT)
unnamed: R19.2, U5.15 (P0.03)
unnamed: R18.2, U6.44 (BOOT0)
unnamed: C18.1, R14.1, SW3.2, U6.7 (NRST)
unnamed: CY1.2, U6.5 (PH0), Y1.1
unnamed: CY2.2, U6.6 (PH1), Y1.3
unnamed: C22.1, U6.22 (VCAP1)
VBUS: C7.2, D1.2 (A), J2.A4 (VBUS), J2.A9 (VBUS), J2.B4 (VBUS), J2.B9 (VBUS), TP1.1, U3.5 (VBUS), U4.13 (IN)

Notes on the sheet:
BLUETOOTH MODULE
USB-C PORT
MAIN CONTROLLER
HEADER
BATTERY CHANGER MODULE
UWB MODULE
BUCK-BOOST REGULATOR
PI Filter
NOTE: Use a 5 V-tolerant MCU GPIO. Configure the pin as open-drain.
TRACE 50 Ohm !
PWR_LATCH low = power off.

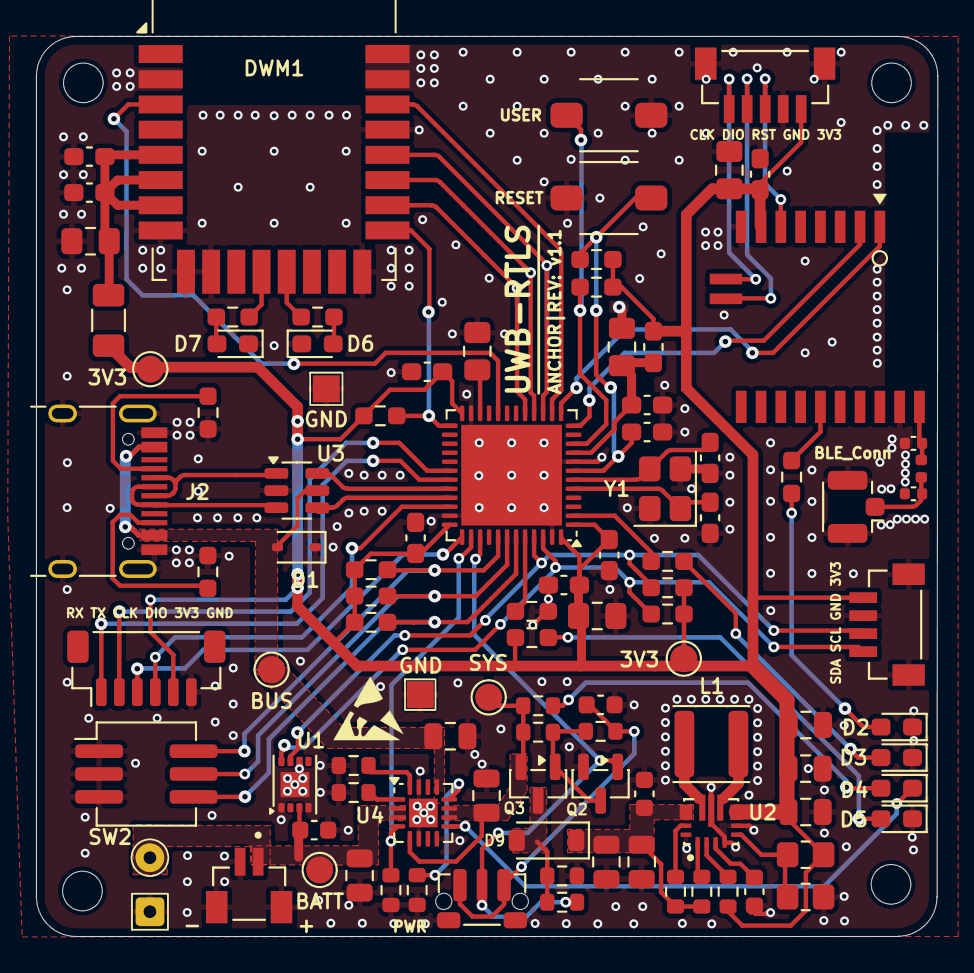
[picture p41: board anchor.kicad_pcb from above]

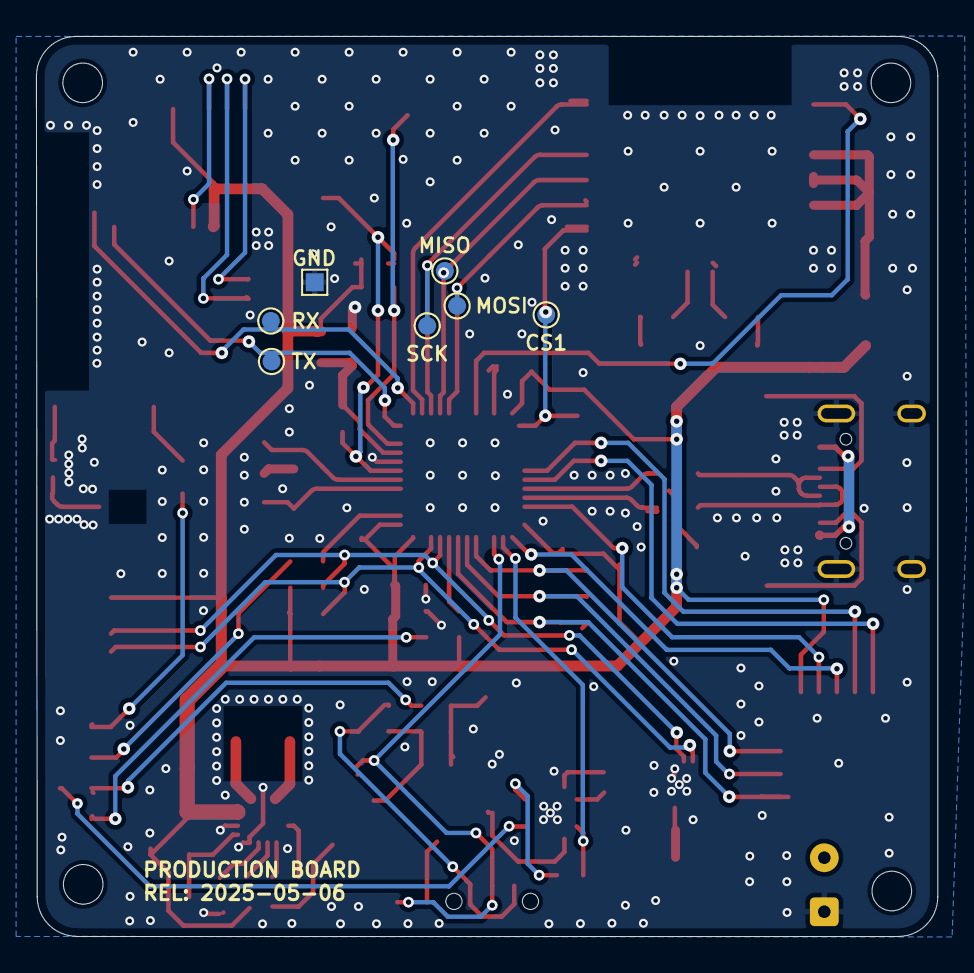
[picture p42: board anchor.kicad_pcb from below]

Board: 2 copper layers, 50.1 x 50.0 mm, 111 parts (8 on the bottom side), 68 nets.

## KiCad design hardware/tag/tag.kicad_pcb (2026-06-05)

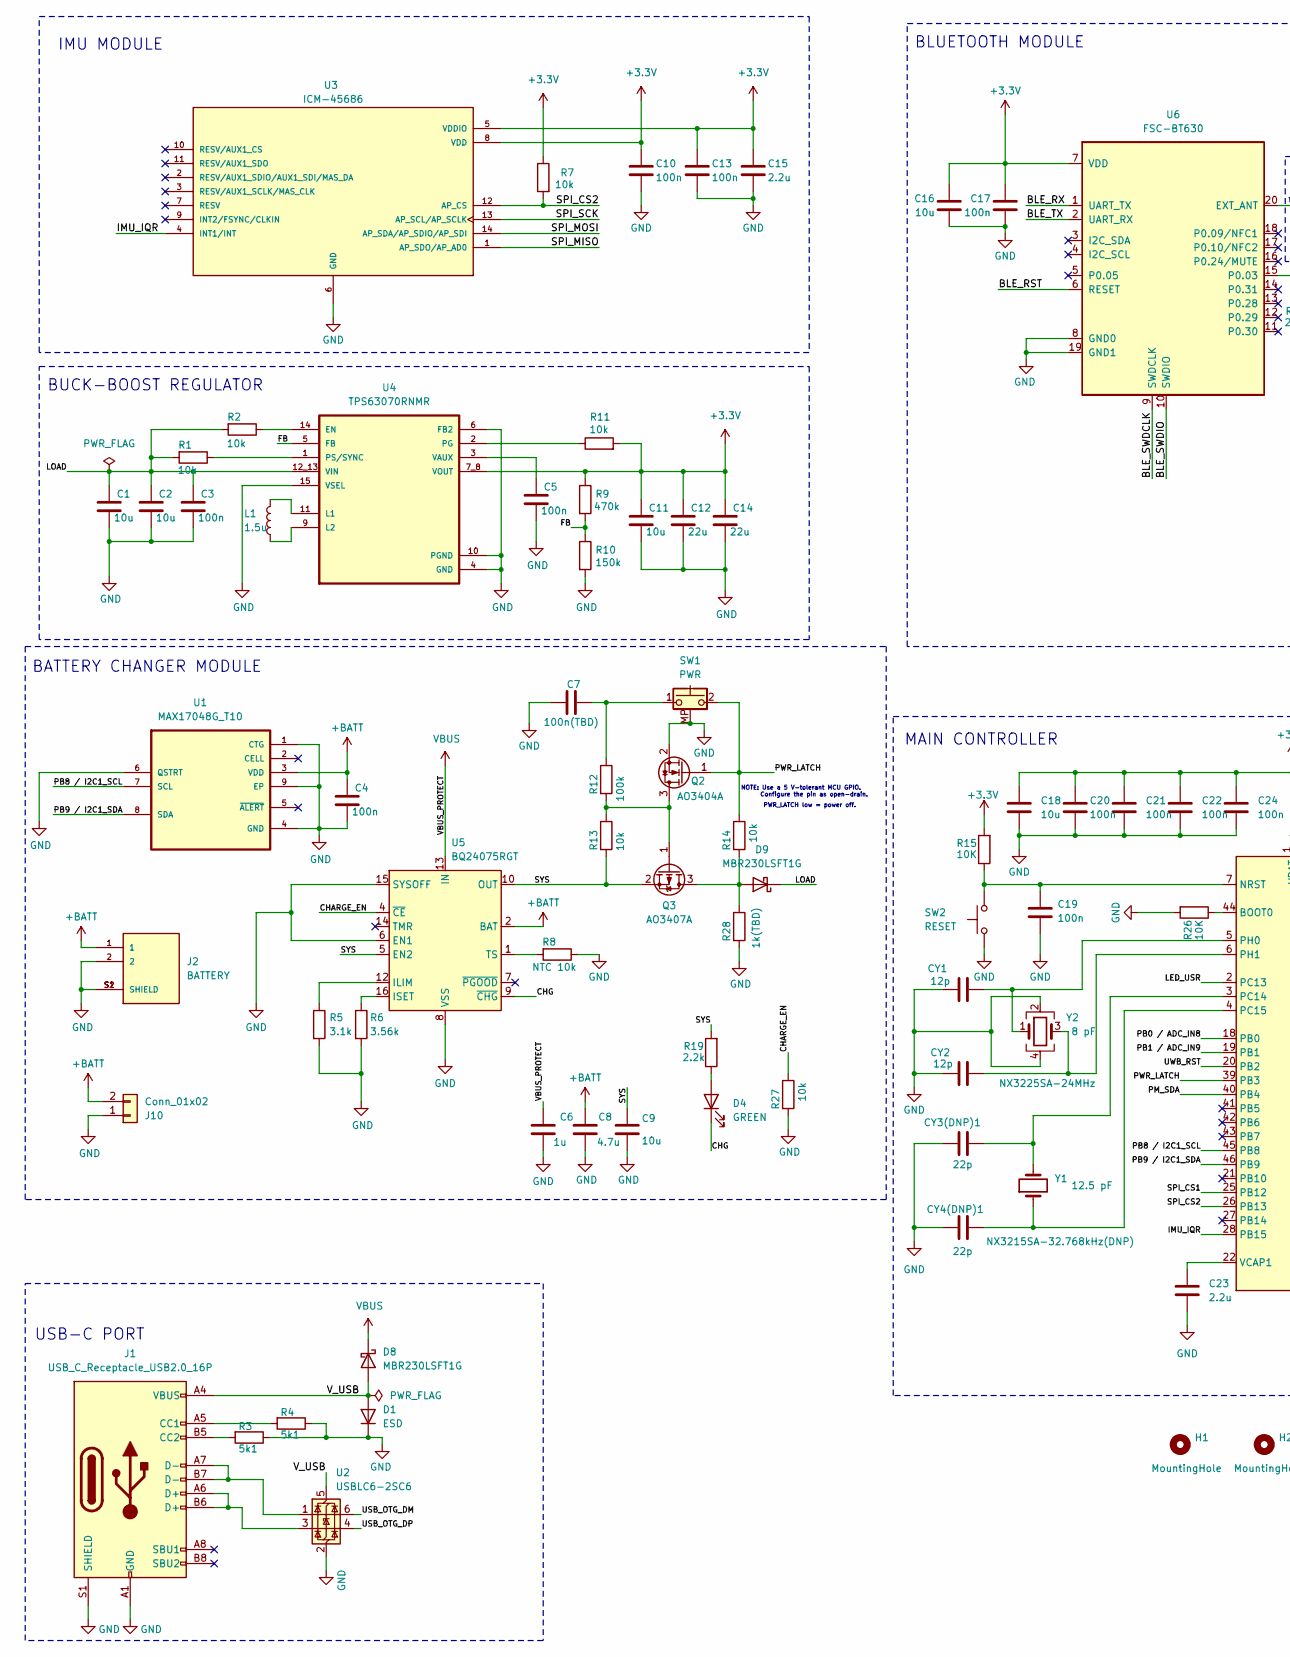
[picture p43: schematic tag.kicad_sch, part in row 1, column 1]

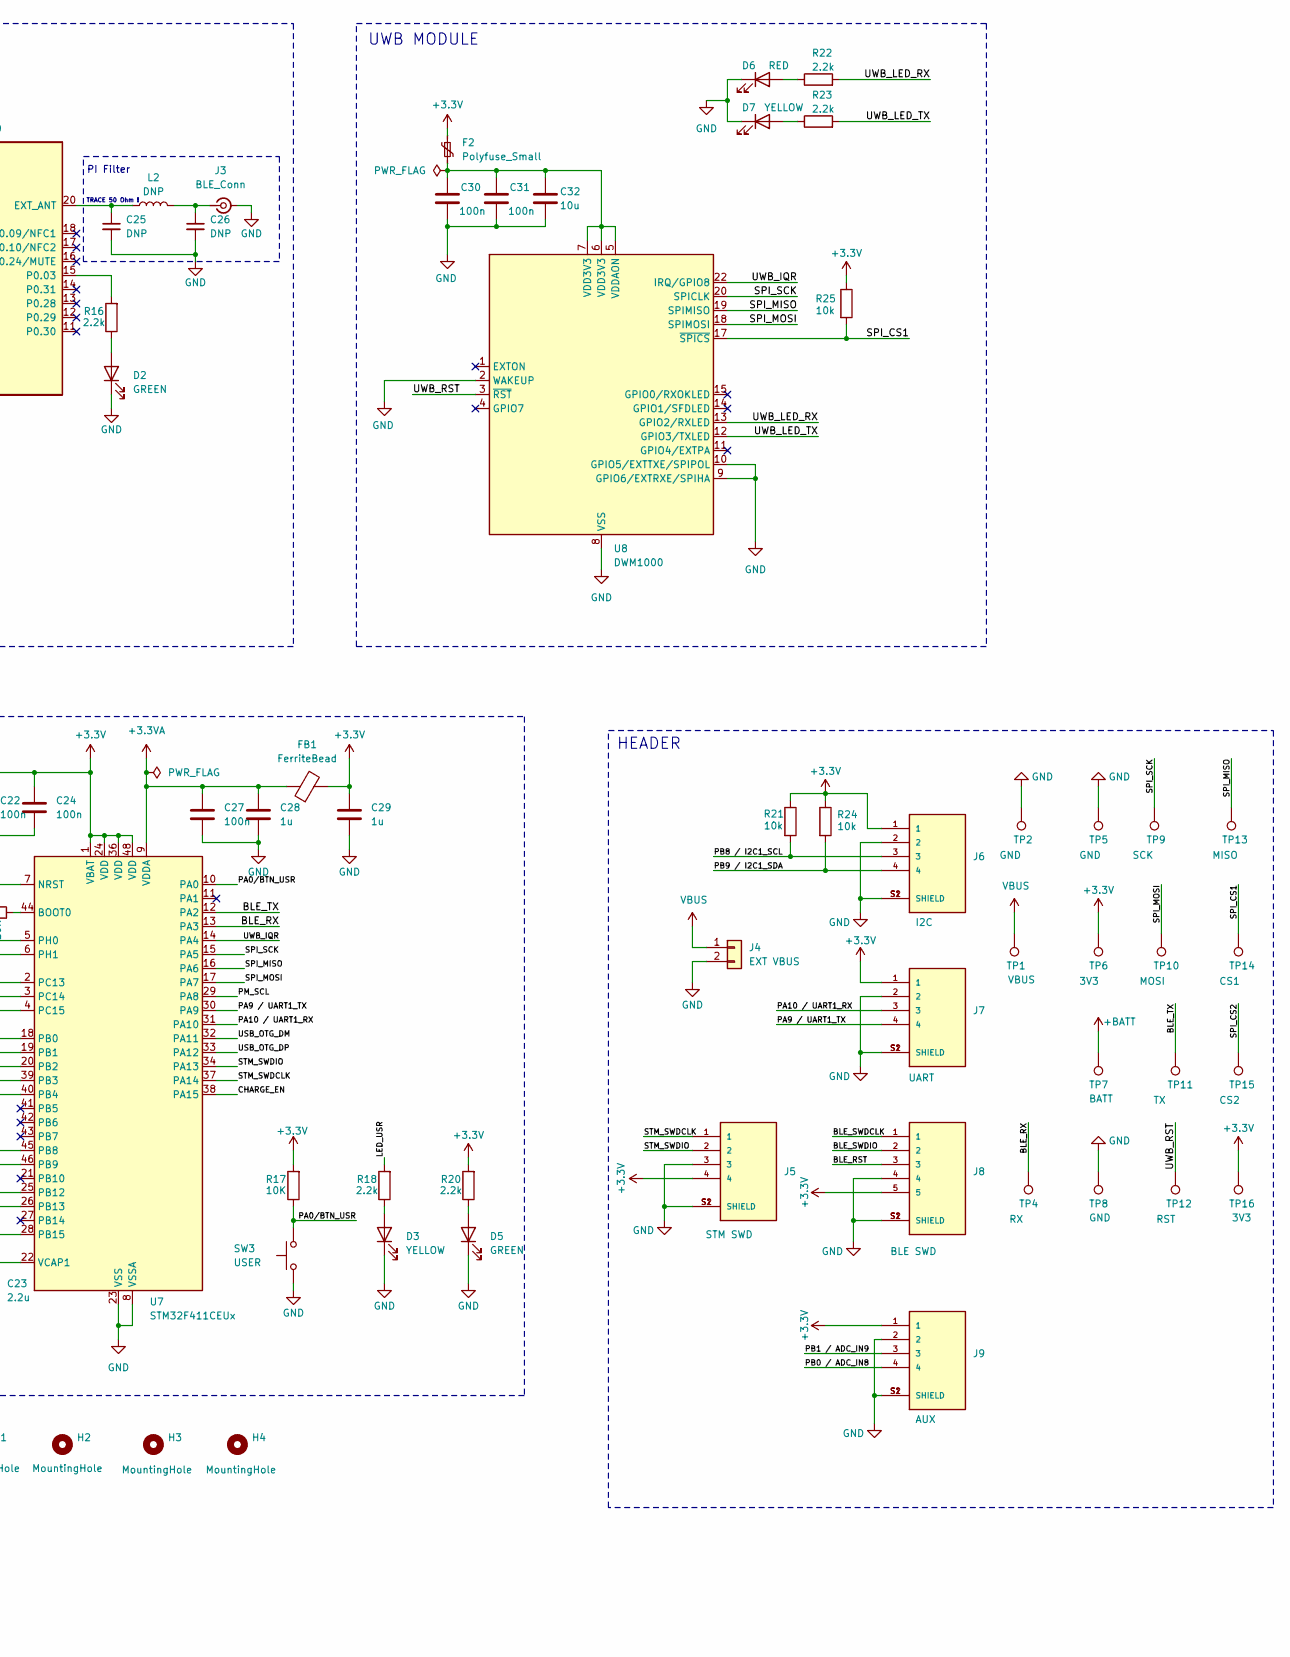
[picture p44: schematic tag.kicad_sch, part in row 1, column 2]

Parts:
C1, C2, C9, C11: 10u; C_0805_2012Metric
C3, C4, C5: 100n; C_0603_1608Metric
C6: 1u; C_0805_2012Metric
C7: 100n(TBD); C_0603_1608Metric
C8: 4.7u; C_0805_2012Metric
C10, C13, C17, C19, C20, C21, C22, C24, C27, C30, C31: 100n; C_0603_1608Metric_Pad1.08x0.95mm_HandSolder
C12, C14: 22u; C_0805_2012Metric
C15, C23: 2.2u; C_0805_2012Metric_Pad1.18x1.45mm_HandSolder
C16, C18, C32: 10u; C_0805_2012Metric_Pad1.18x1.45mm_HandSolder
C25, C26: DNP; C_0402_1005Metric
C28, C29: 1u; C_0805_2012Metric_Pad1.18x1.45mm_HandSolder
CY1, CY2: 12p; C_0603_1608Metric_Pad1.08x0.95mm_HandSolder
CY3(DNP)1, CY4(DNP)1: 22p; C_0603_1608Metric_Pad1.08x0.95mm_HandSolder
D1: ESD; D_SOD-323
D2, D4, D5: GREEN; LED_0603_1608Metric_Pad1.05x0.95mm_HandSolder
D3, D7: YELLOW; LED_0603_1608Metric_Pad1.05x0.95mm_HandSolder
D6: RED; LED_0603_1608Metric_Pad1.05x0.95mm_HandSolder
D8: MBR230LSFT1G; D_SOD-123F
D9: MBR230LSFT1G; D_SOD-123
F2: Polyfuse_Small; Fuse_1206_3216Metric
FB1: FerriteBead; L_0603_1608Metric_Pad1.05x0.95mm_HandSolder
H1, H2, H3, H4: MountingHole; MountingHole_2.2mm_M2
J1: USB_C_Receptacle_USB2.0_16P; USB_C_Receptacle_HRO_TYPE-C-31-M-12
J2: BATTERY; JST_BM02B-SRSS-TB_LF__SN_; PARTREV N/A
J3: BLE_Conn; U.FL_Hirose_U.FL-R-SMT-1_Vertical
J4: EXT VBUS
J5: STM SWD; JST_BM04B-SRSS-TB_LF__SN_; PARTREV N/A
J6: I2C; JST_BM04B-SRSS-TB_LF__SN_; PARTREV N/A
J7: UART; JST_BM04B-SRSS-TB_LF__SN_; PARTREV N/A
J8: BLE SWD; JST_BM05B-SRSS-TB_LF__SN_; PARTREV N/A
J9: AUX; JST_BM04B-SRSS-TB_LF__SN_; PARTREV N/A
J10: Conn_01x02; SolderWire-0.1sqmm_1x02_P3.6mm_D0.4mm_OD1mm
L1: 1.5u; L_Sunlord_SWPA4020S
L2: DNP; L_0402_1005Metric
Q2: AO3404A; SOT-23
Q3: AO3407A; SOT-23
R1, R2, R11, R13, R14, R27: 10k; R_0603_1608Metric
R3, R4: 5k1; R_0603_1608Metric_Pad0.98x0.95mm_HandSolder
R5: 3.1k; R_0603_1608Metric
R6: 3.56k; R_0603_1608Metric
R7, R21, R24, R25: 10k; R_0603_1608Metric_Pad0.98x0.95mm_HandSolder
R8: NTC 10k; R_0603_1608Metric
R9: 470k; R_0805_2012Metric_Pad1.20x1.40mm_HandSolder
R10: 150k; R_0805_2012Metric_Pad1.20x1.40mm_HandSolder
R12: 100k; R_0603_1608Metric
R15, R17, R26: 10K; R_0603_1608Metric_Pad0.98x0.95mm_HandSolder
R16, R18, R20, R22, R23: 2.2k; R_0603_1608Metric_Pad0.98x0.95mm_HandSolder
R19: 2.2k; R_0603_1608Metric
R28: 1k(TBD); R_0603_1608Metric
SW1: PWR; SW_Push_1P1T-MP_NO_Horizontal_Alps_SKRTLAE010
SW2: RESET; SW_Tactile_SMD_3x4mm_2pin_update
SW3: USER; SW_Tactile_SMD_3x4mm_2pin_update
TP1: VBUS; TestPoint_Pad_D1.5mm
TP2, TP5: GND; TestPoint_Pad_1.5x1.5mm
TP4: RX; TestPoint_Pad_D1.0mm
TP6, TP16: 3V3; TestPoint_Pad_D1.5mm
TP7: BATT; TestPoint_Pad_D1.5mm
TP8: GND; TestPoint_Pad_1.0x1.0mm
TP9: SCK; TestPoint_Pad_D1.0mm
TP10: MOSI; TestPoint_Pad_D1.0mm
TP11: TX; TestPoint_Pad_D1.0mm
TP12: RST; TestPoint_Pad_D1.0mm
TP13: MISO; TestPoint_Pad_D1.0mm
TP14: CS1; TestPoint_Pad_D1.0mm
TP15: CS2; TestPoint_Pad_D1.0mm
U1: MAX17048G_T10; SON-8-1EP_3x2mm_P0.5mm_EP1.4x1.6mm
U2: USBLC6-2SC6; SOT-23-6
U3: ICM-45686; IC_ICM-45686; PARTREV 0.2
U4: TPS63070RNMR; VREG_TPS63070RNMR
U5: BQ24075RGT; VQFN-16-1EP_3x3mm_P0.5mm_EP1.6x1.6mm
U6: FSC-BT630
U7: STM32F411CEUx; QFN-48-1EP_7x7mm_P0.5mm_EP5.6x5.6mm
U8: DWM1000
Y1: NX3215SA-32.768kHz(DNP); Crystal_SMD_3215-2Pin_3.2x1.5mm
Y2: NX3225SA-24MHz; Crystal_SMD_3225-4Pin_3.2x2.5mm

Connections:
+3.3V: C10.1, C11.1, C12.1, C13.1, C14.1, C15.1, C16.1, C17.1, C18.1, C20.1, C21.1, C22.1, C24.1, C29.1, F2.1, FB1.2, J5.4, J6.1, J7.1, J8.5, J9.1, R7.1, R9.1, R11.2, R15.2, R17.2, R20.2, R21.1, R24.1, R25.1, TP6.1, TP16.1, U3.5 (VDDIO), U3.8 (VDD), U4.7_8 (VOUT), U6.7 (VDD), U7.1 (VBAT), U7.24 (VDD), U7.36 (VDD), U7.48 (VDD)
+3.3VA: C27.1, C28.1, FB1.1, U7.9 (VDDA)
+BATT: C4.1, C8.1, J2.1, J10.2, TP7.1, U1.3 (VDD), U5.2 (BAT), U5.3 (BAT)
/BLE_RST: J8.3, U6.6 (RESET)
/BLE_RX: TP4.1, U6.1 (UART_TX), U7.13 (PA3)
/BLE_SWDCLK: J8.1, U6.9 (SWDCLK)
/BLE_SWDIO: J8.2, U6.10 (SWDIO)
/BLE_TX: TP11.1, U6.2 (UART_RX), U7.12 (PA2)
/CHARGE_EN: R27.1, U5.4 (~CE), U7.38 (PA15)
/CHG: D4.1 (K), U5.9 (~CHG)
/FB: R9.2, R10.1, U4.5 (FB)
/IMU_IQR: U3.4 (INT1/INT), U7.28 (PB15)
/LED_USR: R18.2, U7.2 (PC13)
/LOAD: C1.1, C2.1, C3.1, D9.1 (K), R1.2, R2.2, U4.12_13 (VIN)
/PA0/BTN_USR: R17.1, SW3.2, U7.10 (PA0)
/PA9 / UART1_TX: J7.4, U7.30 (PA9)
/PA10 / UART1_RX: J7.3, U7.31 (PA10)
/PB0 / ADC_IN8: J9.4, U7.18 (PB0)
/PB1 / ADC_IN9: J9.3, U7.19 (PB1)
/PB8 / I2C1_SCL: J6.3, R21.2, U1.7 (SCL), U7.45 (PB8)
/PB9 / I2C1_SDA: J6.4, R24.2, U1.8 (SDA), U7.46 (PB9)
/PM_SCL: U7.29 (PA8)
/PM_SDA: U7.40 (PB4)
/PWR_LATCH: Q2.1 (G), R14.1, SW1.2, U7.39 (PB3)
/SPI_CS1: R25.2, TP14.1, U7.25 (PB12), U8.17 (~SPICS)
/SPI_CS2: R7.2, TP15.1, U3.12 (AP_CS), U7.26 (PB13)
/SPI_MISO: TP13.1, U3.1 (AP_SDO/AP_AD0), U7.16 (PA6), U8.19 (SPIMISO)
/SPI_MOSI: TP10.1, U3.14 (AP_SDA/AP_SDIO/AP_SDI), U7.17 (PA7), U8.18 (SPIMOSI)
/SPI_SCK: TP9.1, U3.13 (AP_SCL/AP_SCLK), U7.15 (PA5), U8.20 (SPICLK)
/STM_SWDCLK: J5.1, U7.37 (PA14)
/STM_SWDIO: J5.2, U7.34 (PA13)
/SYS: C9.1, Q3.2 (S), R13.2, R19.2, U5.5 (EN2), U5.10 (OUT), U5.11 (OUT)
/USB_OTG_DM: U2.6 (I/O1), U7.32 (PA11)
/USB_OTG_DP: U2.4 (I/O2), U7.33 (PA12)
/UWB_IQR: U7.14 (PA4), U8.22 (IRQ/GPIO8)
/UWB_LED_RX: R22.2, U8.13 (GPIO2/RXLED)
/UWB_LED_TX: R23.2, U8.12 (GPIO3/TXLED)
/UWB_RST: TP12.1, U7.20 (PB2), U8.3 (~RST)
/V_USB: D1.2 (A), D8.2 (A), J1.A4 (VBUS), J1.A9 (VBUS), J1.B4 (VBUS), J1.B9 (VBUS), U2.5 (VBUS)
GND: C1.2, C2.2, C3.2, C4.2, C5.2, C6.1, C7.1, C8.2, C9.2, C10.2, C11.2, C12.2, C13.2, C14.2, C15.2, C16.2, C17.2, C18.2, C19.2, C20.2, C21.2, C22.2, C23.2, C24.2, C25.2, C26.2, C27.2, C28.2, C29.2, C30.2, C31.2, C32.2, CY1.1, CY2.1, CY3(DNP)1.1, CY4(DNP)1.1, D1.1 (K), D2.1 (K), D3.1 (K), D5.1 (K), D6.1 (K), D7.1 (K), J1.A1 (GND), J1.A12 (GND), J1.B1 (GND), J1.B12 (GND), J1.S1 (SHIELD), J2.2, J2.S1 (SHIELD), J2.S2 (SHIELD), J3.2 (Ext), J4.2, J5.3, J5.S1 (SHIELD), J5.S2 (SHIELD), J6.2, J6.S1 (SHIELD), J6.S2 (SHIELD), J7.2, J7.S1 (SHIELD), J7.S2 (SHIELD), J8.4, J8.S1 (SHIELD), J8.S2 (SHIELD), J9.2, J9.S1 (SHIELD), J9.S2 (SHIELD), J10.1, Q2.2 (S), R3.1, R4.1, R5.2, R6.2, R8.1, R10.2, R26.2, R27.2, R28.2, SW1.MP (B), SW2.1, SW3.1, TP2.1, TP5.1, TP8.1, U1.1 (CTG), U1.4 (GND), U1.6 (QSTRT), U1.9 (EP), U2.2 (GND), U3.6 (GND), U4.4 (GND), U4.6 (FB2), U4.10 (PGND), U4.15 (VSEL), U5.6 (EN1), U5.8 (VSS), U5.15 (SYSOFF), U5.17 (VSS), U6.8 (GND0), U6.19 (GND1), U7.8 (VSSA), U7.23 (VSS), U7.35 (VSS), U7.47 (VSS), U7.49 (VSS), U8.2 (WAKEUP), U8.8 (VSS), U8.9 (GPIO6/EXTRXE/SPIHA), U8.10 (GPIO5/EXTTXE/SPIPOL), U8.16 (VSS), U8.21 (VSS), U8.23 (VSS), U8.24 (VSS), Y2.2, Y2.4
unnamed: C7.2, R12.1, SW1.1
unnamed: D2.2 (A), R16.1
unnamed: D3.2 (A), R18.1
unnamed: D4.2 (A), R19.1
unnamed: D5.2 (A), R20.1
unnamed: D6.2 (A), R22.1
unnamed: D7.2 (A), R23.1
unnamed: D9.2 (A), Q3.3 (D), R14.2, R28.1
unnamed: J1.A5 (CC1), R4.2
unnamed: J1.B5 (CC2), R3.2
unnamed: J1.A6 (D+), J1.B6 (D+), U2.3 (I/O2)
unnamed: J1.A7 (D-), J1.B7 (D-), U2.1 (I/O1)
unnamed: C26.1, J3.1 (In), L2.2
unnamed: Q2.3 (D), Q3.1 (G), R12.2, R13.1
unnamed: R2.1, U4.14 (EN)
unnamed: L1.2, U4.11 (L1)
unnamed: L1.1, U4.9 (L2)
unnamed: R11.1, U4.2 (PG)
unnamed: R1.1, U4.1 (PS/SYNC)
unnamed: C5.1, U4.3 (VAUX)
unnamed: R5.1, U5.12 (ILIM)
unnamed: R6.1, U5.16 (ISET)
unnamed: R8.2, U5.1 (TS)
unnamed: C25.1, L2.1, U6.20 (EXT_ANT)
unnamed: R16.2, U6.15 (P0.03)
unnamed: R26.1, U7.44 (BOOT0)
unnamed: C19.1, R15.1, SW2.2, U7.7 (NRST)
unnamed: CY3(DNP)1.2, U7.3 (PC14), Y1.2
unnamed: CY4(DNP)1.2, U7.4 (PC15), Y1.1
unnamed: CY1.2, U7.5 (PH0), Y2.1
unnamed: CY2.2, U7.6 (PH1), Y2.3
unnamed: C23.1, U7.22 (VCAP1)
unnamed: C30.1, C31.1, C32.1, F2.2, U8.5 (VDDAON), U8.6 (VDD3V3), U8.7 (VDD3V3)
VBUS: C6.2, D8.1 (K), J4.1, TP1.1, U5.13 (IN)

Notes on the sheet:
TRACE 50 Ohm !
PI Filter
BATTERY CHANGER MODULE
NOTE: Use a 5 V-tolerant MCU GPIO. Configure the pin as open-drain.
MAIN CONTROLLER
IMU MODULE
PWR_LATCH low = power off.
HEADER
USB-C PORT
BUCK-BOOST REGULATOR
BLUETOOTH MODULE
UWB MODULE

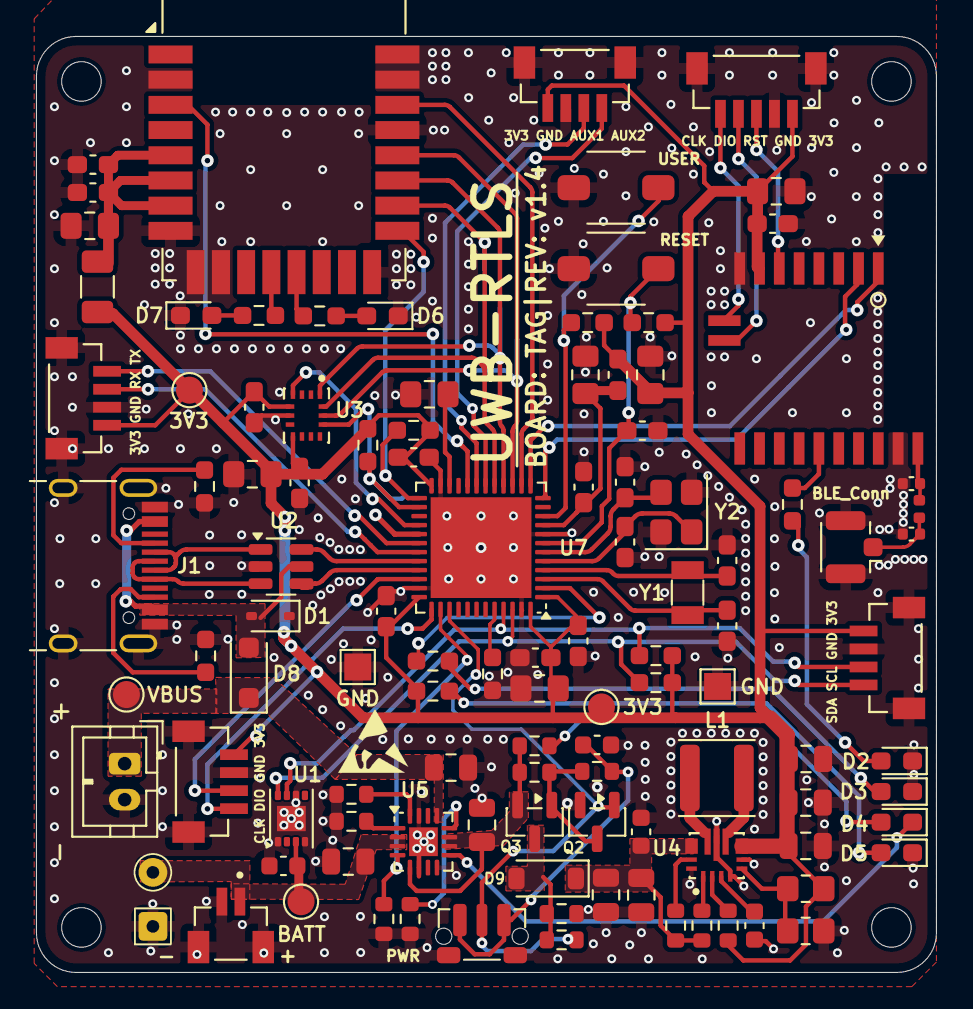
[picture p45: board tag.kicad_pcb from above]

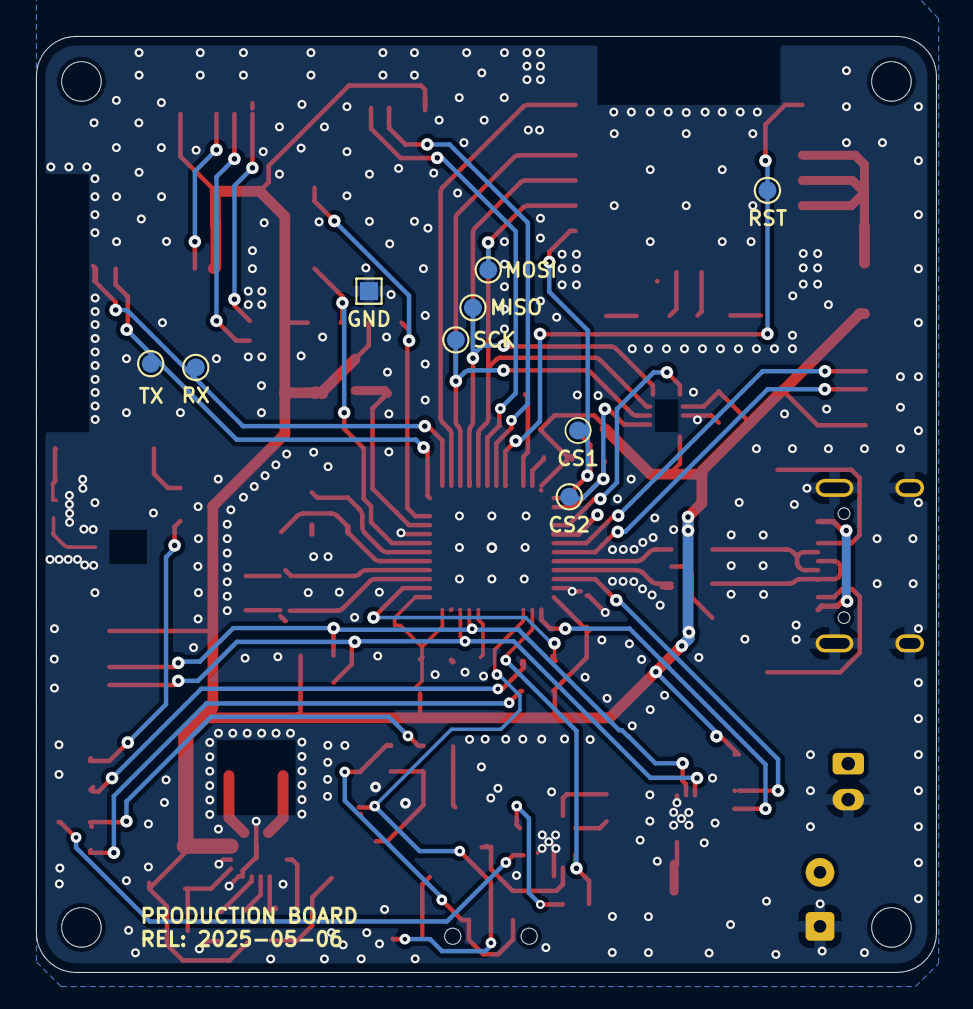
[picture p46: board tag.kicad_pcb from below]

Board: 2 copper layers, 50.0 x 52.0 mm, 121 parts (9 on the bottom side), 72 nets.

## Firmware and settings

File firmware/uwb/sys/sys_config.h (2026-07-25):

/**
 * @file       sys_config.h
 * @copyright
 * @license
 * @version    1.2.0
 * @date       2026-03-05
 * @author     Phuong Mai
 * @brief      System configuration — runtime config IS protobuf_sys_config_t
 * @note       sys_config_t is a typedef for protobuf_sys_config_t.
 *             device_type is stored separately (device_type_set/get commands).
 */
#ifndef __SYS_CONFIG_H
#define __SYS_CONFIG_H

/* Includes ----------------------------------------------------------------- */
#include "bsp_util.h"
#include "config.h"
#include "otp/otp.h"
#include "positioning_config.h"
#include "protos/protocol.pb.h"

#include <stdbool.h>
#include <stdint.h>

/* Type aliases ------------------------------------------------------------- */
typedef protobuf_device_role_t        device_role_t;
typedef protobuf_device_type_t        device_type_t;
typedef protobuf_host_transport_t     host_transport_t;
typedef protobuf_anchor_layout_item_t sys_anchor_layout_t;
typedef protobuf_prefilter_cfg_t      sys_prefilter_cfg_t;

#define DEVICE_ROLE_UNSPECIFIED      protobuf_DEVICE_ROLE_UNSPECIFIED
#define DEVICE_ROLE_TAG              protobuf_DEVICE_ROLE_TAG
#define DEVICE_ROLE_ANCHOR           protobuf_DEVICE_ROLE_ANCHOR

#define DEVICE_TYPE_UNSPECIFIED      protobuf_DEVICE_TYPE_UNSPECIFIED
#define DEVICE_TYPE_TAG              protobuf_DEVICE_TYPE_TAG
#define DEVICE_TYPE_ANCHOR           protobuf_DEVICE_TYPE_ANCHOR
#define DEVICE_TYPE_GATEWAY          protobuf_DEVICE_TYPE_GATEWAY
#define DEVICE_TYPE_DEBUG_TOOL       protobuf_DEVICE_TYPE_DEBUG_TOOL

#define HOST_TRANSPORT_UNSPECIFIED   protobuf_HOST_TRANSPORT_UNSPECIFIED
#define HOST_TRANSPORT_USB           protobuf_HOST_TRANSPORT_USB
#define HOST_TRANSPORT_UART          protobuf_HOST_TRANSPORT_UART

#define SYS_CONFIG_MAX_ANCHORS       MAX_ANCHORS_SUPPORTED
#define SYS_CONFIG_CALIB_MAX_SAMPLES 64

typedef protobuf_anchor_power_mode_t anchor_power_mode_t;

#define ANCHOR_POWER_MODE_PERFORMANCE protobuf_ANCHOR_POWER_MODE_PERFORMANCE
#define ANCHOR_POWER_MODE_BALANCED    protobuf_ANCHOR_POWER_MODE_BALANCED
#define ANCHOR_POWER_MODE_ECO         protobuf_ANCHOR_POWER_MODE_ECO
#define ANCHOR_POWER_MODE_DEEP_ECO    protobuf_ANCHOR_POWER_MODE_DEEP_ECO

/**
 * @brief System configuration stored in flash and RAM.
 *        config_version and device_type are non-protobuf bookkeeping fields.
 *        uwb contains the full UWB runtime config as protobuf_uwb_cfg_t.
 */
typedef struct
{
  uint8_t             config_version; /* bump → forces flash reset on upgrade */
  uint8_t             _pad[3];
  device_type_t       device_type;
  host_transport_t    host_transport;
  protobuf_uwb_cfg_t  uwb; /* maps to sys_config_set/resp.config */
  sys_prefilter_cfg_t prefilter;
  uint32_t            anchor_count;
  sys_anchor_layout_t anchor_layout[SYS_CONFIG_MAX_ANCHORS];

  /* Zone Profile configurations */
  uint32_t            default_zone_id;
  protobuf_zone_profile_t zone_profiles[4];
} sys_config_t;

/* Default values ----------------------------------------------------------- */
#define CONFIG_VERSION            52     /* bump → forces flash reset on upgrade */

#define DEFAULT_DEVICE_ROLE       DEVICE_TYPE_ANCHOR
#define DEFAULT_DEVICE_TYPE       DEVICE_TYPE_ANCHOR
#define DEFAULT_HOST_TRANSPORT    HOST_TRANSPORT_USB
#define DEFAULT_DEVICE_ID         0x03
#define DEFAULT_RANGING_PERIOD_MS 100     /* ~14.1Hz target update rate */
#define DEFAULT_RX_TIMEOUT_MS     80
#define DEFAULT_UWB_CHANNEL       4
#define DEFAULT_UWB_PRF           64
#define DEFAULT_UWB_DATA_RATE     1 /* 0=110kbps, 1=850kbps, 2=6.8Mbps */
#define DEFAULT_ZONE_1_PREAMBLE_CODE 17
#define DEFAULT_ZONE_2_PREAMBLE_CODE 18
#define DEFAULT_ZONE_3_PREAMBLE_CODE 19
#define DEFAULT_ZONE_4_PREAMBLE_CODE 20
#define DEFAULT_TX_ANT_DLY        16436
#define DEFAULT_RX_ANT_DLY        16436
#define DEFAULT_TX_POWER          0x3A5A7A9AUL /* ~-14.5 dBm with smart power on */
#define DEFAULT_ANCHOR_POWER_MODE   ANCHOR_POWER_MODE_DEEP_ECO
#define DEFAULT_UWB_PREAMBLE_LEN  0x34 /* DWT_PLEN_512 */
#define DEFAULT_UWB_RX_PAC        2    /* DWT_PAC32: recommended for DWT_PLEN_512 */
#define DEFAULT_UWB_NS_SFD        1
#define DEFAULT_UWB_PHR_MODE      0    /* DWT_PHRMODE_STD */
#define DEFAULT_SMART_TX_POWER    true
#define DEFAULT_PG_DELAY          0xC2
#define DEFAULT_PREFILTER_ENABLE  ENABLE_MAHALANOBIS_PREFILTER

/* ========================================================================== */
/*                         PUBLIC FUNCTIONS                                  */
/* ========================================================================== */

void sys_config_init(void);

/**
 * @brief Get pointer to live config struct (protobuf_sys_config_t).
 *        Callers may read/write fields directly — call sys_config_save() to persist.
 */
sys_config_t *sys_config_get(void);

/* Identity setters (validated) */
int                    sys_config_set_role(device_role_t role);
int                    sys_config_set_device_type(device_type_t device_type);
int                    sys_config_set_host_transport(host_transport_t host_transport);
int                    sys_config_set_device_id(uint8_t id);
device_type_t          sys_config_get_device_type(void);
host_transport_t       sys_config_get_host_transport(void);
const sys_prefilter_cfg_t *sys_config_get_prefilter(void);
int                    sys_config_set_prefilter(const sys_prefilter_cfg_t *prefilter);
void                   sys_config_get_anchor_layout(sys_anchor_layout_t *anchors, uint32_t *count);
int                    sys_config_set_anchor_layout(const sys_anchor_layout_t *anchors, uint32_t count);
int sys_config_set_power_mode(anchor_power_mode_t mode);
otp_err_t sys_config_factory_otp_write(const protobuf_factory_otp_write_t *req);
uint8_t sys_config_get_hw_rev(void);

uint32_t sys_config_get_active_zone_id(void);
void sys_config_set_active_zone_id(uint32_t zone_id);
bool sys_config_zone_profile_valid(const protobuf_zone_profile_t *profile);
int sys_config_set_zone_profile(const protobuf_zone_profile_t *profile);
bool sys_config_apply_zone_profile(uint32_t zone_id);

/* Storage */
int  sys_config_save(void);
int  sys_config_load(void);
void sys_config_reset_to_defaults(void);
void sys_config_print(void);

#endif /* __SYS_CONFIG_H */

/* End of file -------------------------------------------------------- */

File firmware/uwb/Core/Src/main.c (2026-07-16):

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
/* Includes ------------------------------------------------------------------*/
#include "main.h"
#include "cmsis_os.h"
#include "adc.h"
#include "crc.h"
#include "dma.h"
#include "i2c.h"
#include "rtc.h"
#include "spi.h"
#include "tim.h"
#include "usart.h"
#include "usb_device.h"
#include "gpio.h"

/* USER CODE BEGIN Includes */
#include "app_anchor.h"
#include "app_tag.h"
#include "ble/sys_ble_peripheral.h"
#include "bsp_battery.h"
#include "bsp_io.h"
#include "bsp_util.h"
#include "bsp_uwb.h"
#include "common.h"
#include "config.h"
#include "network/network_cmd.h"
#include "network/network_core.h"
#include "positioning_config.h"
#include "serial/serial.h"
#include "sys_config.h"
#include "sys_flash_storage.h"
#include "sys_logger.h"
#ifdef HAVE_BLE_PERIPHERAL
#include "ble/sys_ble_peripheral.h"
#endif
//#include "sys_task.h" /* Deprecated */
#include "sys_pm.h"
#include "app_rtos_handles.h"

#include <string.h>
#include "bsp_imu.h"
/* USER CODE END Includes */

/* USER CODE BEGIN PD */
#define BL_MAGIC_ADDR  (0x2001FFF0UL)
#define BL_MAGIC_VALUE (0xDEADB007UL)

/* ========== Position Test Mode ========== */
#define TEST_SEND_POS  0 /* 0=disabled, 1=enabled */

#if TEST_SEND_POS
#define TEST_DISABLE_RANGING 1    /* 1=disable ranging (UART only), 0=keep ranging */
#define TEST_POS_INTERVAL_MS 100  /* Send interval (ms) */
#define TEST_POS_START_X     1.0f /* Start X coordinate */
#define TEST_POS_START_Y     1.0f /* Start Y coordinate */
#define TEST_POS_END_X       5.0f /* End X coordinate */
#define TEST_POS_END_Y       5.0f /* End Y coordinate */
#define TEST_POS_STEP        0.5f /* Step increment 	*/
#define TEST_POS_Z           0.5f /* Fixed Z coordinate */
#define TEST_POS_ERROR       0.1f /* Fixed error estimate */
#endif

/* USER CODE END PD */

extern network_core_t g_network_core;
extern uint8_t g_network_rx_buf[NETWORK_CORE_PACKET_BUFFER_SIZE];

/* USER CODE BEGIN PV */
#if TEST_SEND_POS
static float    s_test_x              = TEST_POS_START_X;
static float    s_test_y              = TEST_POS_START_Y;
static uint32_t s_last_test_send_tick = 0;
#endif
/* USER CODE END PV */

void SystemClock_Config(void);
void MX_FREERTOS_Init(void);
/* USER CODE BEGIN 0 */

#if TEST_SEND_POS
/**
 * @brief Test function to send dummy position data via UART
 * @note Non-blocking, called periodically from main loop
 */
static void test_send_position(void)
{
  uint32_t current_tick = HAL_GetTick();

  /* Check if enough time has passed */
  if ((current_tick - s_last_test_send_tick) < TEST_POS_INTERVAL_MS)
  {
    return;
  }

  s_last_test_send_tick = current_tick;

  /* Send current position */
  bsp_err_t ret = bsp_io_uart_send_position(s_test_x, s_test_y, TEST_POS_Z, TEST_POS_ERROR);

  if (ret == BSP_OK)
  {
    /* Update position for next send */
    s_test_x += TEST_POS_STEP;

    /* Check X boundary */
    if (s_test_x > TEST_POS_END_X)
    {
      s_test_x = TEST_POS_START_X;
      s_test_y += TEST_POS_STEP;

      /* Check Y boundary - loop back */
      if (s_test_y > TEST_POS_END_Y)
      {
        s_test_y = TEST_POS_START_Y;
      }
    }
  }
  /* If BSP_ERR (busy), just skip this interval and try next time */
}

static void test_send_pos_task(void *arg)
{
  test_send_position();
}
#endif

void app_reset_config(void)
{
  __disable_irq();
  SCB->VTOR     = 0x0800C000;
  SysTick->CTRL = 0;
  SysTick->LOAD = 0;
  SysTick->VAL  = 0;

  for (uint32_t i = 0; i < 8; i++)
  {
    NVIC->ICER[i] = 0xFFFFFFFF;
    NVIC->ICPR[i] = 0xFFFFFFFF;
  }

  __DSB();
  __ISB();
  __enable_irq();
}

/* USER CODE END 0 */

/**
  * @brief  The application entry point.
  * @retval int
  */
int main(void)
{

  /* USER CODE BEGIN 1 */
  app_reset_config();
  /* USER CODE END 1 */

  /* MCU Configuration--------------------------------------------------------*/

  /* Reset of all peripherals, Initializes the Flash interface and the Systick. */
  HAL_Init();

  /* Configure the system clock */
  SystemClock_Config();

  /* Initialize all configured peripherals */
  MX_GPIO_Init();
  MX_DMA_Init();
  MX_I2C1_Init();
  MX_USART1_UART_Init();
  MX_USART2_UART_Init();
  MX_SPI1_Init();
  MX_TIM10_Init();
  MX_TIM11_Init();
  MX_TIM2_Init();
  MX_CRC_Init();
  MX_RTC_Init();
  MX_ADC1_Init();
  /* USER CODE BEGIN 2 */
  int flash_storage_init_status = sys_flash_storage_init();

  sys_logger_init();
  if (flash_storage_init_status != 0)
  {
    RLOG_W(LOG_OBJECT_CODE_APPLICATION, "Flash storage init failed; log persistence may be degraded");
  }
  RLOG_I(LOG_OBJECT_CODE_APPLICATION, "System Starting...");

#if TEST_SEND_POS
  RLOG_I(LOG_OBJECT_CODE_APPLICATION, "========================================");
  RLOG_I(LOG_OBJECT_CODE_APPLICATION, "TEST MODE: Position sending ENABLED");
  RLOG_I(LOG_OBJECT_CODE_APPLICATION, "Interval: %dms", TEST_POS_INTERVAL_MS);
  RLOG_I(LOG_OBJECT_CODE_APPLICATION, "Range: (%.1f,%.1f) to (%.1f,%.1f)", TEST_POS_START_X, TEST_POS_START_Y,
         TEST_POS_END_X, TEST_POS_END_Y);
  RLOG_I(LOG_OBJECT_CODE_APPLICATION, "Step: %.2f", TEST_POS_STEP);
#if TEST_DISABLE_RANGING
  RLOG_I(LOG_OBJECT_CODE_APPLICATION, "*** RANGING DISABLED (UART TEST ONLY) ***");
#endif
  RLOG_I(LOG_OBJECT_CODE_APPLICATION, "========================================");
#endif

  sys_config_init();
  sys_config_t *cfg = sys_config_get();

  bool network_stack_ready = false;
  serial_init();
  if (!network_core_init(&g_network_core, protobuf_PACKET_ADDR_MCU, g_network_rx_buf, sizeof(g_network_rx_buf)))
  {
    RLOG_E(LOG_OBJECT_CODE_APPLICATION, ERR_NOT_INIT, "network_core_init failed");
  }
  else if (!network_cmd_init(&g_network_core))
  {
    RLOG_E(LOG_OBJECT_CODE_APPLICATION, ERR_NOT_INIT, "network_cmd_init failed");
  }
  else
  {
    network_stack_ready = true;
    RLOG_I(LOG_OBJECT_CODE_APPLICATION, "Network command stack ready");
#ifdef HAVE_BLE_PERIPHERAL
    if (!sys_ble_peripheral_init(&g_network_core))
    {
      RLOG_E(LOG_OBJECT_CODE_APPLICATION, ERR_NOT_INIT, "sys_ble_peripheral_init failed");
    }
    else
    {
      sys_ble_peripheral_set_config();
      if (!sys_ble_peripheral_enable(true))
      {
        RLOG_W(LOG_OBJECT_CODE_APPLICATION, "BLE peripheral enable request failed");
      }
    }
#endif
  }

  bsp_util_init();
  if (cfg->device_type == DEVICE_TYPE_TAG)
  {
    if (bsp_imu_init() != BSP_IMU_OK)
    {
      RLOG_W(LOG_OBJECT_CODE_APPLICATION, "IMU initialization failed");
    }
  }
  else
  {
    RLOG_I(LOG_OBJECT_CODE_APPLICATION, "IMU initialization skipped for non-tag device_type=%u",
           (unsigned)cfg->device_type);
  }

#if TEST_SEND_POS && TEST_DISABLE_RANGING
  RLOG_I(LOG_OBJECT_CODE_APPLICATION, "[SKIP] UWB init skipped (test mode)");
  RLOG_I(LOG_OBJECT_CODE_APPLICATION, "[SKIP] App init skipped (test mode)");
#else
  RLOG_I(LOG_OBJECT_CODE_APPLICATION, "[INIT] Initializing DW1000...");
  bool uwb_startup_ready = false;

  if (bsp_uwb_init() != 0)
  {
    RLOG_E(LOG_OBJECT_CODE_APPLICATION, ERR_UWB_INIT, "DW1000 initialization failed!");
  }

#if ENABLE_FORCE_DEFAULT_ANT_DLY
  if (cfg->uwb.role == DEVICE_ROLE_TAG)
  {
    cfg->uwb.tx_antenna_delay = TAG_FACTORY_TX_ANT_DLY;
    cfg->uwb.rx_antenna_delay = TAG_FACTORY_RX_ANT_DLY;
    RLOG_I(LOG_OBJECT_CODE_APPLICATION, "[CFG] Force TAG antenna delay to config default: TX=%u RX=%u",
           TAG_FACTORY_TX_ANT_DLY, TAG_FACTORY_RX_ANT_DLY);
  }
  else if (cfg->uwb.role == DEVICE_ROLE_ANCHOR)
  {
    cfg->uwb.tx_antenna_delay = ANCHOR_DEFAULT_TX_ANT_DLY;
    cfg->uwb.rx_antenna_delay = ANCHOR_DEFAULT_RX_ANT_DLY;
    RLOG_I(LOG_OBJECT_CODE_APPLICATION, "[CFG] Force ANCHOR antenna delay to config default: TX=%u RX=%u",
           ANCHOR_DEFAULT_TX_ANT_DLY, ANCHOR_DEFAULT_RX_ANT_DLY);

    sys_config_save();
    RLOG_I(LOG_OBJECT_CODE_APPLICATION, "[CFG] Saved FORCE_DEFAULT_ANT_DLY to flash");
  }
#else
  RLOG_I(LOG_OBJECT_CODE_APPLICATION, "[CFG] Use previous/calibrated antenna delay from flash");
#endif

  RLOG_I(LOG_OBJECT_CODE_APPLICATION, "[CFG] Active config: CH=%u PRF=%u DR=%u PCode=%u",
         cfg->uwb.uwb_channel, cfg->uwb.uwb_prf, cfg->uwb.uwb_data_rate, cfg->uwb.uwb_preamble_code);
  RLOG_I(LOG_OBJECT_CODE_APPLICATION, "[CFG] Antenna delays: TX=%u RX=%u", cfg->uwb.tx_antenna_delay,
         cfg->uwb.rx_antenna_delay);

  if (bsp_uwb_configure(&cfg->uwb) == BSP_OK)
  {
    uwb_startup_ready = true;
  }
  else
  {
    RLOG_E(LOG_OBJECT_CODE_APPLICATION, ERR_UWB_INIT,
           "DW1000 configuration skipped/failed because init is not ready");
  }
#endif

  bsp_io_init();
  bsp_io_led_off();

  /* sys_task scheduler removed — tasks are managed by FreeRTOS */
  bsp_battery_init(); /* Still init hardware; task runs in power_manage_entry */
  sys_pm_init();

#if !(TEST_SEND_POS && TEST_DISABLE_RANGING)
  /* Initialize application based on role */
  if (cfg->uwb.role == DEVICE_ROLE_TAG)
  {
    app_tag_init();
    RLOG_I(LOG_OBJECT_CODE_APPLICATION, "Tag application initialized");
  }
  else
  {
    app_anchor_init();
    RLOG_I(LOG_OBJECT_CODE_APPLICATION, "Anchor application initialized");
  }

#if UWB_SLEEP_ENABLE
  /* Ranging starts disabled. Put the DW1000 into low-power sleep instead of
   * leaving it in idle; wake restores the cached runtime PHY configuration. */
  if (uwb_startup_ready && bsp_uwb_sleep_enter() == BSP_OK)
  {
    RLOG_I(LOG_OBJECT_CODE_UWB_DRIVER, "[SLEEP] DW1000 sleeping until ranging starts");
  }
  else if (!uwb_startup_ready)
  {
    RLOG_W(LOG_OBJECT_CODE_UWB_DRIVER,
           "[SLEEP] Startup sleep skipped because DW1000 is not initialized");
  }
  else
  {
    RLOG_W(LOG_OBJECT_CODE_UWB_DRIVER, "[SLEEP] DW1000 startup sleep failed");
  }
#else
  if (uwb_startup_ready)
  {
    bsp_uwb_idle();
    RLOG_I(LOG_OBJECT_CODE_UWB_DRIVER, "[SLEEP] Disabled; DW1000 kept awake after init");
  }
#endif
#endif

  if (network_stack_ready)
  {
    if (sys_ble_peripheral_init(&g_network_core))
    {
      sys_ble_peripheral_set_config();
      sys_ble_peripheral_enable(true);
    }
    else
    {
      RLOG_E(LOG_OBJECT_CODE_APPLICATION, ERR_NOT_INIT, "BLE peripheral init failed");
    }
  }
#ifdef DEVELOPER_MODE
  RLOG_I(LOG_OBJECT_CODE_APPLICATION, "DEVELOPER MODE ENABLED: Verbose");
  // Configure SystemView here; recording starts after the scheduler is running.
  SYSVIEW_INIT();
  #pragma message("Developer mode: SystemView enabled")
#endif
/* Init scheduler */
osKernelInitialize();  /* Call init function for freertos objects (in cmsis_os2.c) */
MX_FREERTOS_Init();

/* Start scheduler */
osKernelStart();

/* We should never get here as control is now taken by the scheduler */
/* USER CODE END 2 */

  /* Infinite loop */
  /* USER CODE BEGIN WHILE */
  while (1)
  {
    /* Should never reach here. Button events and ranging control
     * are now handled inside IO task (io_entry) and UwbRanging task. */
    osDelay(1000);
    /* USER CODE END WHILE */

    /* USER CODE BEGIN 3 */
  }
  /* USER CODE END 3 */
}

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
/**
  * @brief  Period elapsed callback in non blocking mode
  * @note   This function is called  when TIM9 interrupt took place, inside
  * HAL_TIM_IRQHandler(). It makes a direct call to HAL_IncTick() to increment
  * a global variable "uwTick" used as application time base.
  * @param  htim : TIM handle
  * @retval None
  */
void HAL_TIM_PeriodElapsedCallback(TIM_HandleTypeDef *htim)
{
  if (htim->Instance == TIM9)
  {
    HAL_IncTick();
  }
}

/**
  * @brief  This function is executed in case of error occurrence.
  * @retval None
  */
void Error_Handler(void)
{
  /* USER CODE BEGIN Error_Handler_Debug */
  __disable_irq();
  while (1)
  {

  }
  /* USER CODE END Error_Handler_Debug */
}
#ifdef USE_FULL_ASSERT
/**
  * @brief  Reports the name of the source file and the source line number
  *         where the assert_param error has occurred.
  * @param  file: pointer to the source file name
  * @param  line: assert_param error line source number
  * @retval None
  */
void assert_failed(uint8_t *file, uint32_t line)
{
}
#endif /* USE_FULL_ASSERT */

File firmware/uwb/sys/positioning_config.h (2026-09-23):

/**
 * @file       positioning_config.h
 * @version    2.0.0
 * @date       2026-01-29
 * @author     Phuong Mai
 * @brief      Centralized configuration for positioning system
 *             All filter parameters and thresholds controlled from here
 */
#ifndef __POSITIONING_CONFIG_H
#define __POSITIONING_CONFIG_H

#include "config.h"

/* ===================================================================
 * ANTENNA DELAY CONFIGURATION
 * =================================================================== */

 /* Enable/Disable: Force antenna delay to otp values on startup
 * 0 = Use calibrated values (if available)
 * 1 = Force antenna delay to otp
 */
#define ENABLE_OTP_ANTENNA_DELAY    0

/* Enable/Disable: Force antenna delay to default values on startup
 * 0 = Use calibrated values (if available)
 * 1 = Force antenna delay to factory defaults
 */
#define ENABLE_FORCE_DEFAULT_ANT_DLY    0

#define TAG_FACTORY_TX_ANT_DLY      16436
#define TAG_FACTORY_RX_ANT_DLY      16436

#define ANCHOR_DEFAULT_TX_ANT_DLY   16187
#define ANCHOR_DEFAULT_RX_ANT_DLY   16187

/* ===================================================================
 * HEIGHT CONFIGURATION
 * =================================================================== */

/**
 * @brief Tag height from ground (meters)
 */
#define TAG_HEIGHT_M            (0.088f)

/**
 * @brief Anchor height from ground (meters)
 */
#define ANCHOR_HEIGHT_M         (0.910f)

/**
 * @brief Height offset between Anchor and Tag (meters)
 */
#define HEIGHT_OFFSET_M         (ANCHOR_HEIGHT_M - TAG_HEIGHT_M)

/* ===================================================================
 * ANCHOR LAYOUT
 * =================================================================== */

#define MAX_ANCHORS_SUPPORTED  8
/* Maximum number of anchors participating in one zone/ranging cycle. */
#define NUM_ANCHORS            4
#if NUM_ANCHORS > MAX_ZONE_ANCHORS
#error "NUM_ANCHORS exceeds protobuf zone-profile capacity"
#endif

#if NUM_ANCHORS > MAX_ANCHORS_SUPPORTED
#error "NUM_ANCHORS exceeds ranging anchor-ID capacity"
#endif

/* Default active zone ID (1 or 2) */
#ifndef DEFAULT_ZONE_ID
#define DEFAULT_ZONE_ID        1
#endif

/* When enabled, a ranging cycle is aborted unless at least three anchors
 * respond and return results. Keep disabled so survey and degraded-layout
 * operation can consume partial ranging results. */
#define SYS_RANGING_REQUIRE_MIN_ANCHOR_SAMPLES  0

/* ===================================================================
 * ZONE SWITCH STRESS TEST
 * =================================================================== */

/* 0 = normal runtime
 * 1 = repeatedly switch between valid zone profiles to measure radio
 *     reconfiguration latency and ranging timing disturbance. Keep this
 *     disabled outside bench testing. */
#ifndef SYS_ZONE_SWITCH_STRESS_TEST_ENABLE
#define SYS_ZONE_SWITCH_STRESS_TEST_ENABLE       0
#endif

#ifndef SYS_ZONE_SWITCH_STRESS_INTERVAL_MS
#define SYS_ZONE_SWITCH_STRESS_INTERVAL_MS       500U
#endif

/* Zone 1 Defaults */
#define ZONE_1_ANCHOR_1_ID   1
#define ZONE_1_ANCHOR_1_X    -0.5f
#define ZONE_1_ANCHOR_1_Y    -0.5f
#define ZONE_1_ANCHOR_1_Z    ANCHOR_HEIGHT_M

#define ZONE_1_ANCHOR_2_ID   2
#define ZONE_1_ANCHOR_2_X    10.26f
#define ZONE_1_ANCHOR_2_Y    -0.5f
#define ZONE_1_ANCHOR_2_Z    ANCHOR_HEIGHT_M

#define ZONE_1_ANCHOR_3_ID   3      
#define ZONE_1_ANCHOR_3_X    -0.5f
#define ZONE_1_ANCHOR_3_Y    10.26f
#define ZONE_1_ANCHOR_3_Z    ANCHOR_HEIGHT_M

#define ZONE_1_ANCHOR_4_ID   4
#define ZONE_1_ANCHOR_4_X    10.26f
#define ZONE_1_ANCHOR_4_Y    10.26f
#define ZONE_1_ANCHOR_4_Z    ANCHOR_HEIGHT_M

#define ZONE_1_ANCHOR_5_ID   5
#define ZONE_1_ANCHOR_5_X    0.0f
#define ZONE_1_ANCHOR_5_Y    0.0f
#define ZONE_1_ANCHOR_5_Z    0.0f

#define ZONE_1_ANCHOR_6_ID   6
#define ZONE_1_ANCHOR_6_X    0.0f
#define ZONE_1_ANCHOR_6_Y    0.0f
#define ZONE_1_ANCHOR_6_Z    0.0f

/* Zone 2 is intentionally left unconfigured for now. */

/* ===================================================================
 * DISTANCE VALIDATION
 * =================================================================== */

#define MAX_VALID_DISTANCE_M    (50.0f)
#define MIN_VALID_DISTANCE_M    (0.05f)

/* ===================================================================
 * FILTER ENABLE/DISABLE CONTROL
 * =================================================================== */

/**
 * @brief Enable/Disable the mw_filter Mahalanobis pre-filter.
 *        0 = bypass Mahalanobis gate
 *        1 = apply Mahalanobis gate before anchor selection
 */
#ifndef ENABLE_MAHALANOBIS_PREFILTER
#define ENABLE_MAHALANOBIS_PREFILTER  1
#endif
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

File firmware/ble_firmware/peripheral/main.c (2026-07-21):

/**
 * Copyright (c) 2015 - 2021, Nordic Semiconductor ASA
 *
 * All rights reserved.
 *
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
 * 3. Neither the name of Nordic Semiconductor ASA nor the names of its
 *    contributors may be used to endorse or promote products derived from this
 *    software without specific prior written permission.
 *
 * 4. This software, with or without modification, must only be used with a
 *    Nordic Semiconductor ASA integrated circuit.
 *
 * 5. Any software provided in binary form under this license must not be reverse
 *    engineered, decompiled, modified and/or disassembled.
 *
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
 */
/**
 * @brief Blinky Sample Application main file.
 *
 * This file contains the source code for a sample server application using the LED Button service.
 */

#include <stdint.h>
#include <string.h>
#include "nordic_common.h"
#include "nrf.h"
#include "app_error.h"
#include "boards.h"
#include "app_timer.h"
#include "nrf_pwr_mgmt.h"
#include "nrf_drv_wdt.h"

// System-wide BLE configs
#include "../ble_common/ble_config.h"

#include "../ble_common/ble_bridge/bb_router.h"
#include "../ble_common/ble_bridge/bb_cmd_hdl.h"
#include "../ble_common/ble_bridge/bb_debug.h"
#include "../ble_common/ble_bridge/bb_broadcast.h"

#include "nrf_log.h"
#include "nrf_log_ctrl.h"

#include "bsp_uart.h"
#include "bsp_utils.h"

#include "logger.h"

#include "ble_peripheral.h"
#include "bb_transport.h"

/*
**@brief Function for initializing power management.
*/
static void power_management_init(void)
{
    ret_code_t err_code;
    err_code = nrf_pwr_mgmt_init();
    APP_ERROR_CHECK(err_code);
}

static nrf_drv_wdt_channel_id m_wdt_channel_id;

static void wdt_event_handler(void)
{
    // Minimal handler. Reset is imminent.
}

static void watchdog_init(void)
{
    ret_code_t err_code;
    nrf_drv_wdt_config_t config = NRF_DRV_WDT_DEAFULT_CONFIG;
    err_code = nrf_drv_wdt_init(&config, wdt_event_handler);
    APP_ERROR_CHECK(err_code);
    err_code = nrf_drv_wdt_channel_alloc(&m_wdt_channel_id);
    APP_ERROR_CHECK(err_code);
    nrf_drv_wdt_enable();
}

static void idle_state_handle(void)
{
    if (NRF_LOG_PROCESS() == false)
    {
        nrf_pwr_mgmt_run();
    }
}

/**@brief Function for application main entry.
 */
int main(void)
{
    // Initialize.
    logger_init();
    bsp_utils_init();
    power_management_init();

    ret_code_t err_code = bb_router_init();
    APP_ERROR_CHECK(err_code);
    err_code = bb_cmd_request_ble_adv_config();
    if (err_code != NRF_SUCCESS)
    {
        NRF_LOG_WARNING("ble_adv_config_request failed: 0x%08X", err_code);
    }
    // BLE is disabled by default, initialized later via STM32 command

    // Start execution.
    BB_DEBUG_LOG_INFO("BLE Peripheral started !");

    // Start watchdog AFTER all initialization is complete.
    watchdog_init();

    // Enter main loop.
    for (;;)
    {
        nrf_drv_wdt_channel_feed(m_wdt_channel_id);
        bb_router_process();
        ble_peripheral_process();
        bb_broadcast_process();
        bb_cmd_ble_adv_config_request_process();
        idle_state_handle();
    }
}

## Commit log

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2025-11-09 wip: Save all hardware changes
    [BOM Anchor Board.xlsx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]
2025-11-12 update(anchor): Clear DRC errors and release anchor rev 0.2
    [anchor-B_Cu.gbl, anchor-B_Mask.gbs, anchor-B_Silkscreen.gbo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]
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2025-11-14 Update(bootloader): Improve LED blink logic for correct status display
    [main.c]
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2025-11-19 feat(hardware): Add led status for BLE module and via stiching
    [tag.kicad_pcb, tag.kicad_sch]
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2025-12-13 feat(uwb): Update DWM1000 driver with critical fixes
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2025-12-13 feat: Update application to utilize bsp_io for LED control and DIP switch reading
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2025-12-28 feat: Add antenna delay calibration algorithm for anchor
    [tag.step]
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2026-01-28 refactor: correct comment + bring up 4 anchor
    [positioning_config.h, sys_config.h]
2026-02-02 update: modify bsp_uwb with new functions for current time and delayed TX validation
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2026-02-19 chore: untrack backup files
    [learningkcad.kicad_pcb.bk.kicad_pcb]
2026-02-19 refactor(hw): iterate on tag rev 0.2 design
    [tag.kicad_pcb, tag.kicad_sch]
2026-02-19 update(hw): release tag revision 0.2
    [tag-rounded-B_Cu.gbr, tag-rounded-B_Mask.gbr, tag-rounded-B_Paste.gbr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]
2026-02-19 update(hw): Apply design changes to anchor
    [anchor.kicad_pcb, anchor.kicad_sch]
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2026-02-23 feat: Implement UWB IRQ on PA4 with event-driven RX
    - Configure PA4 as EXTI4 rising edge interrupt
    - Add EXTI4_IRQHandler to forward interrupts to BSP
    - Implement IRQ event flag system in bsp_uwb (on_irq, wait, clear APIs)
    - Route PA4 EXTI callback in bsp_io to bsp_uwb_on_irq()
    - Update hardware PCB production labels (TAG v1.1, REL 2025-02-22)
    [tag.kicad_pcb]
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2026-02-27 update: resolve warning and update log object codes
    [sys_config.h]
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2026-03-07 feat: add device reset command and update serial number retrieval
    [memorylayout.h]
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2026-03-14 update(hw): add schottky diode to prevent reverse current between USB and 5V header
    [tag.kicad_pcb, tag.kicad_sch]
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2026-03-17 fix: update battery read function
2026-03-17 update: Add Python protobuf generation for vv_testings in Makefile
    [tag-B_Cu.gbr, tag-B_Mask.gbr, tag-B_Paste.gbr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]
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2026-03-30 fix bug data crate battery
2026-03-30 Revert "fix bug data crate battery"
    This reverts commit b142a82953f5c8d9de1132e2c303e96b1648bf17.
2026-03-30 fix bug battery
2026-04-03 Update: schematic adjustments
    [tag.kicad_pcb, tag.kicad_sch]
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2026-04-04 fix: resolve build error after merge
    [main.c]
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2026-04-05 Update: Change the on/off power logic on tag
    [tag.kicad_pcb, tag.kicad_sch]
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2026-04-10 feat: Release final hardware for tag & anchor
    [$tempfile$.step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]
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2026-04-14 refactor: modularize BLE Central architecture, optimize dual-scan filter and fix CLI connection logic
    [main.c]
2026-04-14 feat: add inactive sector read logic to prevent log loss
    [main.c]
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2026-04-20 feat: add delayed RX enable functionality and power mode configuration
    (cherry picked from commit e065569b6f29716fd05af83846423743ba0d0544)
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2026-04-22 update: improve UWB frame handling for dynamic payload length and distance array
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2026-04-27 feat(ble_bridge): complete packet routing and MCU command handlers - Update protobuf read/write process for BLE configuration commands. - Add logic in `bb_router` to automatically forward packets (no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
2026-04-27 feat(ble_peripheral): integrate NUS server and fix Adv name truncation - Move DEVICE_NAME to Scan Response to avoid truncation. - Initialize the Nordic UART Service for transparent protobuf packet tr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
    [main.c]
2026-04-30 feat: enhance anchor calibration logic with A2A gradient support and status management
2026-04-30 update: re-generate ioc file
    - Enable temperature and VREF sensor
    - Enable DMA and IRQ for UART
    - Increase system clock to 96MHz
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2026-05-05 update: add schottky diode to prevent the biased voltage back to soft latch circuit
    [tag.kicad_pcb, tag.kicad_sch]
2026-05-06 wip hardware changes
    [tag.kicad_pcb, tag.kicad_sch]
2026-05-06 feat: release final final hardware for tag + anchor
    [$tempfile$.step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]
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2026-05-17 update: improve BLE advertising logic and fix UART read function
    [bsp_uart.c]
2026-05-18 feat(icm42688): - add hardware offset reset API - fix init calibration flow to avoid double bias compensation - remove redundant gravity compensation
2026-05-18 chore(ibsp_mu): - change IMU config (gyro, accel FS) - disable use calib data - add null pointer validation
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2026-05-18 refactor sys_sensor_fusion - change define - add comment - track error
2026-05-19 Resolve conflicts, update protocol files, and optimize anchor calibration solver
    [uwb_calibration.xlsx]
2026-05-19 feat: update clock to 96MHz, configure UART DMA, and sync idle-line logic
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2026-05-22 feat: initialization checks and error handling
    [main.c]
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2026-05-22 Update: schematic with new dimensions and additional notes
    [anchor.kicad_pcb, anchor.kicad_sch, tag.kicad_pcb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]
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2026-05-23 (exxcel) save antenna delay
    [uwb_calibration.xlsx]
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2026-05-29 - Move UKF Vx and UKF Vy from IMU Rotation plot to Integrated Velocity plot - Show current sample index in trajectory replay controls - Render replay breadcrumbs as points instead of connected lines 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
2026-05-29 - Route ENABLE_SYS_FUSION_LOG output through sensor_fusion_entry - Send fusion log frames after UKF predict in the SensorFusion task - Store latest ranging snapshot in app_tag for fusion log output -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
2026-05-29 feat: update ranging logic for improved performance + correct logic prefilter in firmware
    [main.c, sys_config.h]
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2026-06-01 save antenna delay
    [uwb_calibration.xlsx]
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2026-06-03 Update: try to fix the MCU bricked issue + adding more debug logic in DEVELOPER mode
    [common.h, main.c]
2026-06-05 implement sensor fusion stream: - add protobuf message and rearrange packet id - rebuild programmer - vvtesting sensor fusion stream
2026-06-05 refactor: adjust UI device manager & live tracking, fix logic detect dongle
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2026-06-09 call API update UI for device_manager tabs and fix some bug in software
    [config_tab.py, main.py]
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2026-06-10 Fix: BLE broadcast and central ADV test flow
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2026-06-11 feat(hw/mcu): configure ADC DMA conversion and skip IMU on non-tag devices
    [main.c]
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2026-06-12 fix: remap BLE UART RX pin to P0.05 due to burned-out pin
2026-06-13 - ble log fast push - add print debug in test_pushing_log - mcu auto send log
2026-06-16 - implement stream log on supermini nrf52840 - test_ble_log: + scan by uuid + choose device to connect
2026-06-16 user can endsession and choose another device to get log by hotkey q
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2026-06-16 feat(hw): configure ADC DMA conversion and skip IMU on non-tag devices
    [main.c]
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2026-06-17 wip: log data - peri: print seq of log packet - mcu: add variables to debug, fix not auto return true - app: remove auto start log when connect, only start when press Start Log
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2026-06-20 /* test anchor layout */ - freertos + fix mode disable fusion - config + change anchor to eco mode - live_plot + draw distance graph by dot
    [positioning_config.h, sys_config.h]
2026-06-20 /* fix log and stream */ - ble + remove handle ack + print status every 5s + increase buffer size to 1024 - mcu + reduce resend ack to 3s + reset s_log_tracker in endsession - scripts + log: disable 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
    [bsp_uart.c]
2026-06-20 - fix mode disable fusion - change baudrate uart2 bootloader to 230400
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2026-06-24 feat: add logic call api rtos, set change interface usb/uart dev mode, logic ble params edit
2026-06-25 refactor: fix cant kill app, add message ble into tab communication/test
    [main.py]
2026-06-25 refactor: fix disconnect dongle cant open popup scan, format decode data, block send twice for packet
    [main.py]
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2026-06-26 feat: implement packet device_type_get/set && fix bug in tab log&communication, call battery information polling(2s)
    [config_tab.py, main.py]
2026-06-27 - uwb: send sensor fusion BLE/UART data with int16 x100 fields and anchor metadata - pi: accept the new fusion uart payload length and decode fixed-point values - dashboard: support the new fusion fr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
    [config.py, uwb_gateway.py]
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2026-06-27 refactor: change state button start/stop log and clear log, add logic button connect device other
2026-06-30 feat: - packet handler for rtos_task_stats_get_t , rtos_resource_get_t, sensor_fusion_cfg_get_t, sys_config_set_t - force antenna delay - live plot: change graph_d x-axis to time
2026-06-30 feat: implement sleeping logic during IDLE state for both STM32 and NRF +fix minor bugs
    [main.c, positioning_config.h]
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2026-07-02 (software/utils): - scripts calculate atenna delay
    [antenna_config.txt]
2026-07-02 (simulation): - graph d domain x - add ground truth - change anchor layout
2026-07-02 feat: rework logic connect device, handshake state UI with state dongle, resolve conflict end_session, implement factory OTP
    [config_tab.py, main.py]
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2026-07-03 refactor: adjust ui FE, bind button send/get layout MCU, reflow draw panel & add helper from keyboard
2026-07-04 - imu: + implement imu task + change logic get imu temp - calib: + add ground truth to live plot
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2026-07-05 feat: add offset yaw, resolve command send/get packet ack, handle ble_status for telemetry logic
2026-07-05 feat: add field serial number to popupscan & other device, remove logic target device to action read/write in config/calib, adjust realtime for communication
2026-07-07 fix: update battery temperature compensation to 35C
2026-07-08 refactor: fix limit row parser_packet runtime, fix block establishing connect form device to device, check error ble_adv_status dont show popup/other
2026-07-08 fix cant show status adv for multi device results
2026-07-09 update antenna delay
    [uwb_calibration.xlsx]
2026-07-09 refactor: success fix connect flow device
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2026-07-09 bootloader: - bypass application CRC validation uwb: - add UWB sleep disable flag - include UKF step and anchor mask in fusion frames - update ranging and UKF stream flags simulation: - add CSV brows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
    [config.py, main.c, sys_config.h]
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2026-07-10 refactor: rework flow call api
2026-07-10 refactor: fix cant show anchor layout into map, block fps under 60hz
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2026-07-10 rework flow call api, resolve thread api
    [config_tab.py]
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2026-07-13 refactor: remove old cache data , fix thread flow api and print debug global queue commands on terminal
    [config_tab.py, main.py]
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2026-07-15 simulation: fix no imu data
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2026-07-16 fix ground truth can't draw rounded corners or snap to points., disable scanning after connected
    [config_tab.py, main.py]
2026-07-17 feat(sim): align IMU axes conversion in log parser fix(sim): secure report generation with thread lock and cache reset feat(sim): add IMU debug panel and sync channel to replay UI
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2026-07-19 feat: simplify prefilter and improve stability
    [positioning_config.h]
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2026-07-22 refactor(calib): move antenna-delay calibration from firmware to app, per-anchor host-driven closed loop
    Remove app_calib_master.c (one-shot, unweighted, wrong sensitivity constant,
    only self-applied to the calibrating tag) and its firmware calib_start/stop/
    status_get/candidate_apply protocol messages. Firmware now just ranges
    normally; all error computation, iteration control, and convergence logic
    moves to a new AntennaDelayCalibrationViewModel that targets anchors
    individually via antenna_delay_bcast_set (adds a persist flag so trial
    values during the search don't hit flash every round).
    [main.py]
2026-07-25 - change initial covariance value - fix IMU body axis - add code test ukf
    [positioning_config.h]
2026-07-25 refactor: replace legacy calibration with antenna delay broadcast
    [config_tab.py, main.py]
2026-07-27 feat: Hide Config tab in Developer mode && add backup wall pad design
    [Assem1.SLDASM, Part3.SLDPRT, pad_component_1.SLDPRT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]
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2026-09-17 fix(firmware): resolve sensor fusion 50Hz timing slip and prefilter deadlock on sudden motion
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
